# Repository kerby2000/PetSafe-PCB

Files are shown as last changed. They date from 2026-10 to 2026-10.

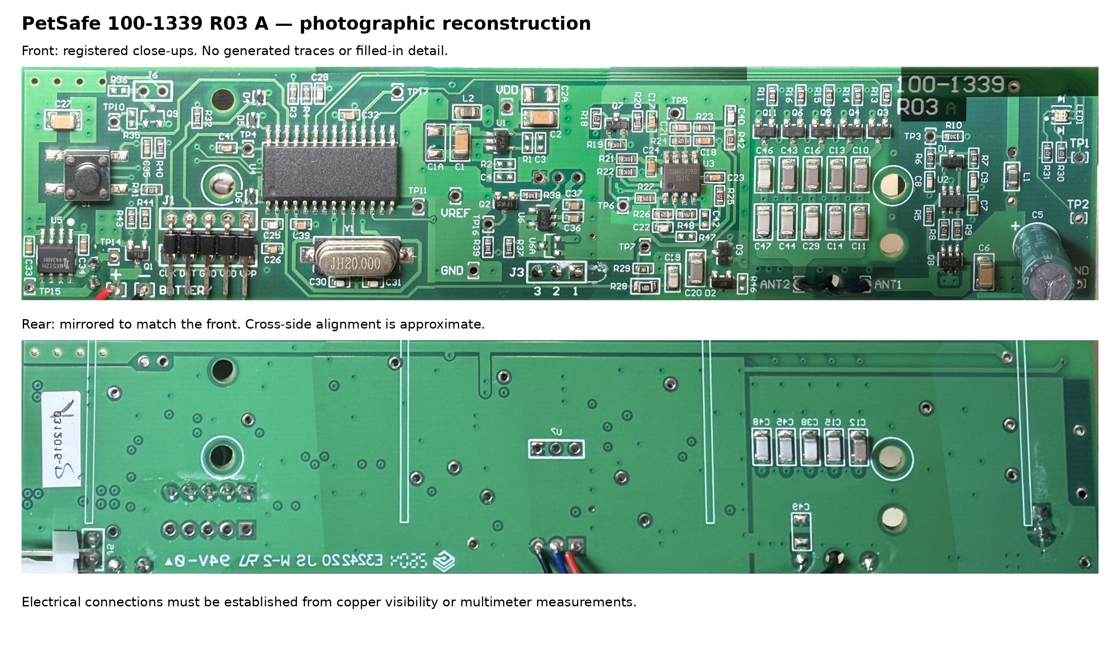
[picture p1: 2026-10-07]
photos/two_sides_overview.jpg

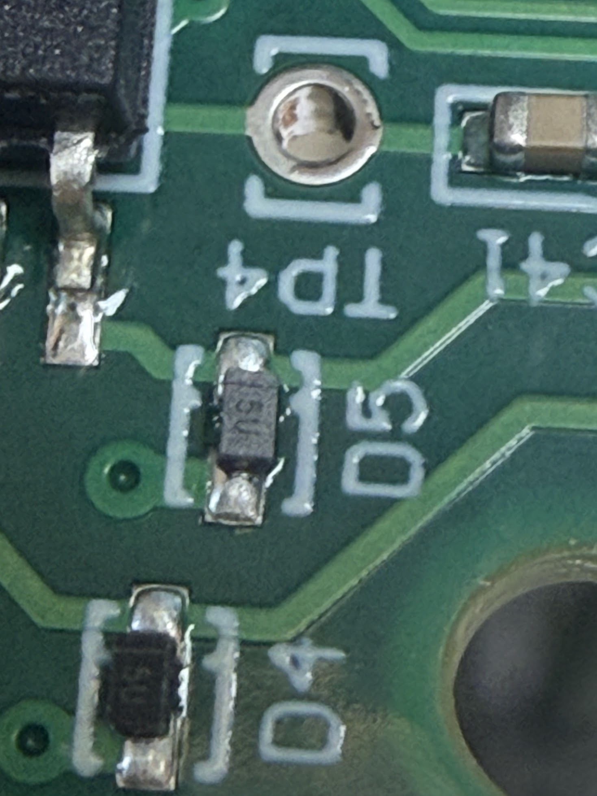
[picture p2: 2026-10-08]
photos/user_updates/D4_D5_5U.png

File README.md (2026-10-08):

# PetSafe PCB reverse engineering

Working reconstruction of the PetSafe PPA19-16811 main board, **100-1339 R03 A**. All 150 catalog entries are drawn on **one A2 KiCad 10 sheet**, with wires within functional blocks and named nets between them. Entries include test pads and unpopulated options.

Start with [the offline overview](index.html), [the current completion checklist](docs/FINISHING_CHECKLIST.html), or [the printable status](output/pdf/PetSafe_completion_status.pdf). Open [the native schematic](schematic/PetSafe_1001339.kicad_sch) in KiCad 10. The [single-sheet PDF](output/pdf/PetSafe_single_sheet.pdf) and SVG are native KiCad exports.

## Current status

Schematic revision **v0.9.9**; investigation cleanup **2026-10-08**. The model and native file agree on 83 net partitions. All PIC pads have modeled local connections, but some remote destinations and circuit roles remain uncertain. There is **no routed KiCad PCB**, confirmed layer stack, or powered functional validation.

| Remaining work | Current state |
|---|---|
| Open physical pads | 28: 10 on populated entries, 18 on empty options |
| Other incomplete connections | 3 isolated labels, plus inferred receiver/RF/PIR branches |
| Values | 44 fitted ceramic values; L1/L2 type and value |
| Footprints | 147/150 assigned; C5, S1 and LED1 geometry missing |
| ERC | 36 findings: 28 open pins, 3 isolated labels, 5 undriven power inputs |
| Libraries | 20 stock definitions and 4 authorized custom candidate definitions in use |

The checklist gives every known issue a stable ID, supporting evidence, next useful check and closure criterion. **A question mark, an assigned footprint, or zero open PIC pads does not measure overall completeness.** The first priority is D3: V082 reaches board VDD, but the corresponding D3 terminal has not been identified. Do not merge the receiver supply into VDD on that basis alone.

## Power names

| Name | Meaning |
|---|---|
| BATTERY+ | Printed BATTERY (+), before Q1 |
| VSYS | User-approved name after Q1; U5/MX512H pin 4 and the supply sides of L1/L2 |
| VDD | Printed VDD test point, regulated logic supply; U5 pin 1 / VCC |
| VREF | Printed VREF test point and confirmed PIC/bias connections |
| GND | Printed GND and BATTERY (-) |

L1/L2 share VSYS on their supply sides; their opposite ends are separate filter branches. H_RF_VDD, H_LDO_IN, H_RX_VDD and H_PIR_VDD are descriptive local branch names, not additional confirmed independent power sources. Actual rail voltages are not yet measured.

## Evidence and navigation

- [Current circuit interpretation](docs/RECONSTRUCTION.md), [measurements](docs/MEASUREMENTS.md), [sources](docs/SOURCES.md), and [library choices / alternatives](docs/LIBRARIES_AND_ALTERNATIVES.md).
- [Front/rear via viewer](docs/VIA_REVIEW.html), [via-pair results](docs/VIA_PAIR_TESTS.html), [current via summary](docs/VIA_REVIEW_RESULTS.md), and [numbered PIC photo](output/pdf/PetSafe_PIC_GPIO_pin_map.pdf).
- [Per-component audit](evidence/completion_audit.csv), [all modeled nets](evidence/proposed_nets.csv), [PIC evidence table](evidence/pic_gpio_status.csv), and [maintained question register](evidence/remaining_work.json).
- [Investigation history](docs/history/README.md). Historical claims and counts are not current instructions or outstanding measurements.

The original ZIP is in `input/`. Original photographs and their checksums are preserved. User reports, photo-derived copper and typical-application hypotheses remain distinct. A source datasheet validates a candidate symbol's pin map, not the fitted part's identity or board wiring. Western alternatives are redesign options, not silent substitutions.

## Reproduce and maintain

Use KiCad **10.x** (validated with 10.0.5), PowerShell and Python 3. Install `tools/requirements.txt` in a Python environment. Author schematic changes with the connected [KiCad MCP server](https://github.com/mixelpixx/KiCAD-MCP-Server); preserve stock library graphics and normal pin numbering. Four project-local symbols are registered using `${KIPRJMOD}`.

```powershell
$env:PYTHONUTF8 = '1'
python -m pip install -r tools/requirements.txt
./tools/build.ps1 -Python python
./tools/refresh_review.ps1 -Python python
```

`build.ps1` exports the existing native file, runs ERC and checks model/netlist partitions and footprints. It does not overwrite native edits. `-Regenerate` explicitly rebuilds from the saved MCP placement template and routing adapter; use it only when those sources are synchronized. `refresh_review.ps1` regenerates current documentation/status and checks electrical regressions and question coverage. Both commands fail on execution or validation errors; the documented outstanding ERC findings are retained.

For electrical edits, keep `evidence/reconstruction.json`, `evidence/library_layout.json`, `evidence/library_placements.json`, the MCP template, native schematic and routing adapter consistent. For documentation updates, maintain `evidence/remaining_work.json`; shared metrics are derived by `tools/current_state.py`. The current electrical regression suite is `tools/verify_v099_review.py`; earlier versioned suites are historical snapshots. Generated outputs should be rebuilt, not edited alone.

Local KiCad history, lock files, caches, QA renders and export ZIPs are ignored. No generated artifact is a fabrication release. Repository: [kerby2000/PetSafe-PCB](https://github.com/kerby2000/PetSafe-PCB).

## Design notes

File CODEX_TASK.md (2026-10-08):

# Current project handoff - 2026-10-08

Read AGENTS.md, README.md and evidence/remaining_work.json first. Schematic v0.9.9; documentation cleanup-1. Repository https://github.com/kerby2000/PetSafe-PCB. Local branch codex/single-sheet-reconstruction. Preserve the user's local schematic/PetSafe_1001339.kicad_pro and ignored schematic/.history/.

Current status is derived by tools/current_state.py. Run tools/build.ps1 followed by tools/refresh_review.ps1 (Python requirements installed; PYTHONUTF8=1). Do not edit generated HTML or status metrics alone. Latest electrical contracts are in tools/verify_v099_review.py; completion coverage in tools/verify_current_review.py. Older scripts/reports are historical, not the current work queue.

The power-path action is finished: BATTERY+ -> Q1 single/native3; Q1.L/native2 -> VSYS -> U5.4 and L1/L2 supply sides. VDD and VREF are separate printed board test points. Q1 is a stock PMOS FMOS3401A? candidate, not the old NPN. Never short across Q1/L1/L2. Keep all user negative evidence, including rejected Q1.L-R43.2 and RC1-VREF joins. The model's 83 partitions and all earlier measured routes remain unchanged by documentation cleanup.

Every known uncertainty has an ID, next check and closure criterion in remaining_work.json. Do not declare the schematic or PCB finished: 10 populated-entry open pads, 18 DNP open pads, 3 isolated labels, partly inferred branches, 44 ceramic values, L1/L2 values and 3 blank footprints remain. Zero open PIC pads only means each has a local modeled net. D3/V082 terminal identification is the first priority. Current docs record the unverified J3.2/.3 roles rather than inferring ground from wire colour.

Original photos/ZIP and chronological records are preserved. No routed PCB exists. No powered functional or rail-voltage readings supplied. Previous file:// browser automation was policy-denied; do not bypass with another browser or localhost. HTML can be inspected as source/data and opened for the user.

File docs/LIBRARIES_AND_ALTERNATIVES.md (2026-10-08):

# KiCad 10 libraries and device alternatives

Revision 0.9.9 uses the existing KiCad MCP Server and the installed KiCad 10.0.5 at `%LOCALAPPDATA%/Programs/KiCad/10.0`. Both its Python backend (`pcbnew.GetBuildVersion()`) and native CLI reported 10.0.5. The MCP created the blank native schematic and placed all 150 components plus five additional units from standard libraries. The checked-in routing adapter reconnects those stock symbols and adds the block frames and annotations. Native KiCad checks the resulting connectivity. MCP PDF/SVG export was also exercised successfully.

The user authorized U1/U5 after vendor files could not be found, and subsequently authorized U6/Q8 datasheet reconstruction. MCP `create_symbol`, `register_symbol_library` and `replace_schematic_component` created and installed U1/U5 from the manufacturer pin tables. The other 20 definitions retain unmodified KiCad stock artwork and numbering. `tools/templates/mcp_standard_placements.kicad_sch` is the MCP placement output; `evidence/library_placements.json` is the replay manifest. `evidence/pin_crosswalk.json` maps all 352 photographed pads to their library pin numbers. Pin mapping can be provisional even when the underlying part symbol is exact.

## Library choices

| References | Library symbol | Reason / status |
|---|---|---|
| U4 | `MCU_Microchip_PIC16:PIC16F18855-xSO` | Exact SOIC family symbol; default SOIC-28W footprint. |
| U2 A/B/C | `74xGxx:74LVC2G14` | Standard multi-unit Schmitt inverter, value `SN74LVC2G14DBV?`, SOT-23-6 footprint. This preserves separate readable gates and supply unit. The exact monolithic `SN74LVC2G14DBV` also exists. |
| U3 A/B/C | `Amplifier_Operational:Opamp_Dual` | Standard generic dual op-amp with matching 1-8 pin functions; value remains SGM8542XS. No modified or custom op-amp symbol. |
| Q1 | `Transistor_FET:Q_PMOS_GSD` | v0.9.9: FMOS3401A candidate, matching manufacturer R1A marking and SOT-23 G1/S2/D3 pinout. Photo R=gate, L=source, single S=drain. Original NPN hypothesis withdrawn. Exact fitted maker unconfirmed. |
| Q2, Q7 | `Transistor_BJT:BC847`, `Transistor_BJT:BC857` | Standard family symbols; values preserve the B/C gain-bin candidates. |
| Q3/Q4/Q5/Q6/Q11 | `Transistor_BJT:Q_PNP_BEC` | Standard generic PNP with B=1, E=2, C=3; value MMBTA55? preserves the uncertain 2H identification. |
| D1/D3 | `Diode:BAV99` | A7 marking candidates; D3 marking now confirmed by the user. Physical orientation and external clamp routes remain inferred. |
| D2 | `Connector_Generic:Conn_01x03` | Unidentified 4P part. Stock numbered placeholder with L=1/R=2/S=3 as bookkeeping only; no functional assignment. Prior BAV99 clamp ties withdrawn. |
| LED1, S1 | `Device:LED_Dual_AAKK`, `Switch:SW_Push_Dual` | Stock four-pin symbols; photographed pad mapping remains provisional. |
| R/C/L/Y/TP | `Device:R`, `Device:C`, `Device:C_Polarized`, `Device:L`, `Device:Crystal`, `Connector:TestPoint` | Existing conventional library parts. C5 polarity is inferred from the selected rail topology. |
| U1 | `PetSafe_Datasheet:S-1200B45-M5T1` | MCP-created from ABLIC Rev.6 page 5: 1 VIN, 2 VSS, 3 ON/OFF, 4 NC, 5 VOUT. B option has active-high enable. The fitted part remains a strong identification candidate, not a measured fact. |
| U5 | `PetSafe_Datasheet:MX512H` | MCP-created from Mixic Rev.1.2 page 2: 1 VCC, 2 INA, 3 INB, 4 VDD, 5 OUTB, 6/7 GND, 8 OUTA. Logic/motor supplies and both ground pins retained. |
| U6 | `PetSafe_Datasheet:S-812C33AMC` | MCP-created from ABLIC Table 5; C2N product code and measured likely ground support identification. |
| Q8 | `PetSafe_Datasheet:SIL3724A` | MCP-imported standard generic N/P graphics with manufacturer-verified 1 G_N, 2 S_P, 3 G_P, 4 D_P, 5 S_N, 6 D_N. Fitted maker unconfirmed. |
| D4/D5 | `Device:D_Zener` | Standard unidirectional avalanche symbol, value SD05? / TVS 5V. Semtech maps 5U to SD05. SOD-323 candidate footprint; ICSP and ground routes are photo-derived. |
| D6 | `Device:D_Zener` | G3 supports MMSZ5228BS? / 3.9V, but PZU2.4B / 2.4V remains an alternative. Standard SOD-323 candidate footprint; ICSP and ground routes are photo-derived. |
| J connectors / empty pads | `Connector_Generic` family | Unknown pitches and empty package identities stay unspecified. These entries preserve the source catalog. |

The installed BAV99 symbol has hidden pin-name strings that do not agree with the Nexperia terminology for pins 1/2. Its visible diode geometry and **pin numbers** agree with the datasheet (1 A1, 2 K2, 3 K1/A2). No library modification or pin swapping was made to hide this naming issue.

## Western alternatives

These are engineering candidates, not identifications of the fitted chips. The reconstruction has not been converted into a replacement board.

| Fitted / candidate part | Alternative | Stock KiCad symbol / footprint | Compatibility |
|---|---|---|---|
| SGM8542XS, SOIC-8 | **Microchip MCP6002-I/SN** | `Amplifier_Operational:MCP6002-xSN`; `Package_SO:SOIC-8_3.9x4.9mm_P1.27mm` | Same eight pin functions and nominal narrow SOIC-8 package. Plausible pin-compatible option, but electrical equivalence is not established. |
| MX512H, SOP-8 | **TI DRV8212PDSGR** | `Driver_Motor:DRV8212P`; `Package_SON:Texas_DSG0008A_WSON-8-1EP_2x2mm_P0.5mm_EP0.9x1.6mm_ThermalVias` | Preferred redesign candidate. Separate logic/motor supplies, two logic inputs, up to 4 A peak. Different package, pinout, exposed ground pad, and sleep control: **requires PCB and control review**. |
| MX512H, lower-current option | TI DRV8837DSGR | `Driver_Motor:DRV8837`; standard WSON-8 footprint | Similar interface, but its 1.8 A headline drive rating is below MX512H's advertised 3 A peak. Do not choose it without establishing motor current margin. |

MCP6002 offers 1.8-6.0 V operation and 1 MHz bandwidth. Against SGM8542's 2.1-5.5 V, 1.1 MHz and 46 uA/amplifier, its typical 100 uA/amplifier increases the receiver's two-channel quiescent load by about **108 uA**. Its 4.5 mV maximum offset versus 3.5 mV also matters in the high-gain chain. The same resistor gain does not guarantee the same receiver threshold or filtering response. Sources: [Microchip DS20001733L](https://ww1.microchip.com/downloads/aemDocuments/documents/MSLD/ProductDocuments/DataSheets/MCP6001-1R-1U-2-4-1-MHz-Low-Power-Op-Amp-DS20001733L.pdf), [SGMICRO datasheet](https://www.sg-micro.com/rect/assets/537cce2c-8022-4ea6-97f4-6524851a35e8/SGM8541_SGM8542_SGM8544.pdf).

DRV8212P covers the inferred battery range with its motor supply and has a 1.65-5.5 V logic supply. Its 4 A figure is a peak rating subject to thermal limits, not a promise of 4 A continuous output on a tiny footprint. MX512H advertises 1.4 A continuous and 3 A peak at 6.5 V; the larger peak margin makes DRV8212P a more useful redesign candidate than DRV8837. Sleep/wake timing, coast/brake behavior, stall current and supply transients remain design checks. Sources: [TI DRV8212P Rev. A](https://www.ti.com/lit/ds/symlink/drv8212p.pdf), [MX512H Rev.1.2](https://static.chipdip.ru/lib/203/DOC045203539.pdf), [TI DRV8837 Rev. F](https://www.ti.com/lit/ds/symlink/drv8837.pdf).

### Motor-driver function cross-reference (redesign only)

| Function | MX512H pin | DRV8212P pin |
|---|---|---|
| Logic supply | 1 VCC | 8 VCC |
| Motor supply | 4 VDD | 1 VM |
| Control A / B | 2 INA / 3 INB | 6 IN1 / 5 IN2 |
| Motor A / B | 8 OUTA / 5 OUTB | 2 OUT1 / 3 OUT2 |
| Ground | 6 and 7 | 4 plus exposed pad (KiCad 9) |
| Sleep | No separate pin | 7 nSLEEP; must be defined, not left floating |

This table matches functions, not physical pad locations. Motor polarity and truth-table behavior still require review before implementing a redesign. DMC3071LVT is a Western Q8 comparison with the same pin functions but a different TSOT package and electrical ratings; it is not an approved replacement. U6 is now an ABLIC Japanese regulator candidate. ABLIC S-1200B45 is a Japanese regulator, not a Chinese device needing a geographical substitution.

## Footprints and completed datasheet symbols

Standard SOT-23, SOT-23-5, SOT-23-6 and SOIC footprints are assigned only for identified/candidate packages. Assignment is a package-family hypothesis, not a measurement of the photographed land pattern. Current assignments use fitted resistor family 0603, anchored by the user R8 full-body measurement; large tuning capacitors use 1206, supported by C11 dimensions. Other bodies remain photo-based estimates. Earlier 0805 family estimates are superseded. Connector pitches and test-pad drills are lower-confidence approximations. Only C5, S1 and LED1 remain unassigned; selecting a stock switch also requires reconciling its common-pad numbering. J1 retains logical pin numbering, so its square-pad/VPP orientation must be reconciled before PCB recreation. See evidence/footprint_evidence.json for every assignment and its basis. U6 SOT-23-5 and Q8 SOT-23-6 are datasheet-based package candidates, not measured land patterns.

The original two exact-symbol requests are now resolved through authorized MCP creation. U1 uses stock `Package_TO_SOT_SMD:SOT-23-5`. U5 uses stock `Package_SO:SOIC-8_3.9x4.9mm_P1.27mm`, matching the nominal package dimensions on MX512H page 9. Pad numbers were checked through MCP. Land-pattern fit on the photographed PCB remains unmeasured. SGM8542 does not need a custom drawing: the stock generic dual op-amp already represents its actual pinout. U6 and Q8 now have datasheet candidate symbols with normal artwork and pin numbering. The old custom library and generator are archived in `reference/v02/`; they are not registered in the active project.

## U6 / Q8 follow-up (2026-10-08)

See [corrected marking and pin maps](U6_Q8_MARKING_UPDATE.md). MCP library search found no exact S-812C or 3724 symbol. U6 was created from ABLIC's pin table; Q8 reuses KiCad's `Q_Dual_NMOS_PMOS_G1S2G2D2S1D1` artwork through MCP import. The six pins match SIL3724A. Actual 3724A fitted manufacturer remains unconfirmed. The earlier RT9818 intermediate symbol was removed after the new photo corrected the marking.

MCP's property writer damaged a nested KiCad 10 property expression during the first Q8 import attempt. The malformed intermediate was removed, the generic base symbol was reimported through MCP, and metadata was repaired with a parsed S-expression. Graphics and pins were not redrawn by hand. Native export and the library audit validate the final result. Authoring details are recorded in `evidence/datasheet_symbol_authoring.json`.

The U1/U5 pin contracts in `evidence/vendor_symbol_requirements.json` are fulfilled. `evidence/datasheet_symbol_authoring.json` records the actual MCP requests and sources. No vendor files were imported. The library URI uses `${KIPRJMOD}`, so the repository is portable. U1 pin 4 is passive and named NC because ABLIC explicitly permits this internally open pad to connect to VIN/VSS; it preserves the existing optional-pad copper. MX512H outputs use tri-state pin types to reflect high-impedance standby. These changes enable additional ERC checks without hiding unresolved nets.

## v0.7 package correction

The user reports R8 approximately 1.6 x 0.77 mm including both metal end caps, confirming the 0603 body-size match. This supersedes v0.6's 0805 fitted-resistor-family estimate; other resistors are revised as provisional 0603 family candidates. C11 approximately 3.2 x 1.5 mm supports its 1206 assignment. C5 value/voltage are now 470uF/16V; its package remains unset pending dimensions.

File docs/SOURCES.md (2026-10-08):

# Source register

Manufacturer pinouts and application examples establish plausible functions, not photographed board connectivity. Accessed 2026-10-07 and 2026-10-08. Key PDFs are saved under `datasheets/`; SHA-256 checksums are in `evidence/datasheet_manifest.json`.

| Ref | Primary source | What it supports |
|---|---|---|
| U1 | [ABLIC S-1200 Rev.6.0](https://www.ablic.com/en/doc/datasheet/voltage_regulator/S1200_E.pdf), saved as S1200.pdf | Page 5 SOT-23-5 pins; page 23 marking PPE = S-1200B45-M5T1x with fourth-character lot code; typical regulator application. |
| U2 | [TI SN74LVC2G14](https://www.ti.com/lit/ds/symlink/sn74lvc2g14.pdf), saved as SN74LVC2G14.pdf | Page 3 DBV six-pin top view; ordering addendum lists C14R; dual Schmitt inverter function. |
| U3 | [SGMICRO SGM8541/8542/8544](https://www.sg-micro.com/rect/assets/537cce2c-8022-4ea6-97f4-6524851a35e8/SGM8541_SGM8542_SGM8544.pdf), saved as SGM8542.pdf | Dual op-amp pinout, 2.1-5.5 V supply, approximately 1.1 MHz gain-bandwidth. |
| U4 | [Microchip PIC16(L)F18855/75 DS40001802H](https://ww1.microchip.com/downloads/aemDocuments/documents/MCU08/ProductDocuments/DataSheets/PIC16%28L%29F18855-75-Data-Sheet-40001802H.pdf) | 28-pin package, power, oscillator and ICSP pins; configurable peripherals. |
| U5 | [Mixic MX512H Rev.1.2, manufacturer PDF mirrored by Chipdip](https://static.chipdip.ru/lib/203/DOC045203539.pdf), saved as MX512H.pdf | Eight-pin H-bridge map; separate logic/motor supplies; application circuit and at least 4.7 uF logic decoupling. Mirror filename/title is less useful than the MX512H content. |
| Q2 | [Nexperia BC847x datasheet](https://assets.nexperia.com/documents/data-sheet/BC847X_SER.pdf) | BC847B marking 1F plus manufacturing code; NPN B/E/C pinout. |
| Q7 | [Nexperia BC857C product information](https://www.nexperia.com/products/bipolar-transistors/general-purpose-and-low-vcesat-bipolar-transistors/single-bipolar-transistors/single-bipolar-transistors-100-v/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) | BC857C PNP with 3G marking plus manufacturing code. |
| Q1 | [Formosa FMOS3401A Rev.C](https://www.formosams.com/upload/product/Mosfets/FMOS3401A_REV_C.pdf), saved as FMOS3401A_REV_C.pdf | Page 5 explicitly lists R1A, 3401 and R1 markings and shows SOT-23 PMOS pin functions. Fits Q1 photo/power path; exact fitted maker unproved. Earlier MMBT3904 NPN hypothesis withdrawn in v0.9.9. |
| Tuning Qs | [Taitron semiconductor catalog](https://www.taitroncomponents.com/docs/2007%20Semiconductor%20Catalog.pdf) | Manufacturer table lists MMBTA55 / 2H / PNP. Exact fitted manufacturer is unknown. |
| Tuning alternative | [Nexperia PBSS5140T](https://assets.nexperia.com/documents/data-sheet/PBSS5140T.pdf) | Alternative PNP candidate; short-code identification remains ambiguous. |
| D1 | [Nexperia BAV99](https://assets.nexperia.com/documents/data-sheet/BAV99.pdf) | A7 marking, SOT23 dual-series diode and pin map. Current Diodes-branded BAV99 uses a different marking; do not use that to prove A7. |
| Native format | [KiCad schematic format](https://dev-docs.kicad.org/en/file-formats/sexpr-schematic/) | Embedded library, symbol units, wires, junctions, instances and labels. Native validation uses the installed 10.0.5 CLI. |

## Photographs used for circuit decisions

| Photo | Main content |
|---|---|
| IMG_2430 | U1/PPEK, regulator capacitors and empty option network |
| IMG_2431, IMG_2432 | U2/C14R, Q8/3724A (sharper follow-up), D1, RF drive resistors |
| IMG_2433, IMG_2442 | Repeated tuning cells and corresponding rear capacitor/via arrangement |
| IMG_2429, IMG_2434 | U3, feedback resistors, receiver components |
| IMG_2435 | U6, Q2 and daughterboard interface |
| IMG_2436, IMG_2437 | PIC, oscillator, programming area and battery-divider resistors |
| IMG_2438 | Motor driver, Q1 and pushbutton |
| IMG_2421 and overview photos | Separate PIR daughterboard context; its internal circuit is not reconstructed |

Full provenance remains in the original component model and photo manifest. Existing image registration is an approximate alignment, not a dimensioned board or a verified layer-stack reconstruction. No exact schematic of this board was adopted from an unrelated product.

## KiCad 10 rebuild and Western alternatives (2026-10-08)

- [KiCad MCP Server](https://github.com/mixelpixx/KiCAD-MCP-Server): already installed and connected. Used for standard-library searches, blank schematic creation, all 150 component placements, extra units, footprint inspection and PDF/SVG export.
- [Microchip MCP6001/2/4 DS20001733L](https://ww1.microchip.com/downloads/aemDocuments/documents/MSLD/ProductDocuments/DataSheets/MCP6001-1R-1U-2-4-1-MHz-Low-Power-Op-Amp-DS20001733L.pdf): page 1 pinout, pages 3-4 operating range, current, offset and bandwidth; SOIC package drawings. Saved as MCP6002.pdf.
- [TI DRV8212P Rev. A](https://www.ti.com/lit/ds/symlink/drv8212p.pdf): page 4 pin functions and exposed pad, page 5 recommended operating conditions, typical application and package drawing. Saved as DRV8212P.pdf. Preferred motor-driver redesign candidate because MX512H advertises a 3 A peak.
- [TI DRV8837 Rev. F](https://www.ti.com/lit/ds/symlink/drv8837.pdf): alternative lower-current driver; its separate supplies, sleep input and WSON package differ from MX512H. Saved as DRV8837.pdf.

Library existence and footprint names were verified against the user's installed KiCad 10 libraries through MCP, not inferred from online search results. See LIBRARIES_AND_ALTERNATIVES.md for compatibility boundaries.

## U6 / Q8 and diode marking sources

- [ABLIC S-812C](https://www.ablic.com/en/doc/datasheet/voltage_regulator/S812C_E.pdf), saved as S812C.pdf: printed p8 Table1 C2N = S-812C33AMC 3.3 V; p11 Table5 pins 1 VSS, 2 VIN, 3 VOUT, 4/5 NC for A variant.
- [ABLIC MP005-A package](https://www.ablic.com/en/doc/package/MP005-A.pdf), saved as ABLIC_MP005-A.pdf: PDF p5 three product-code characters, fourth assembly month, dot positions assembly year/week. Supports C2NM interpretation; M's exact month not decoded.
- [MCC SIL3724A manufacturer PDF, Chipdip mirror](https://static.chipdip.ru/lib/761/DOC050761871.pdf), saved as SIL3724A.pdf: p1 explicit 3724A marking, N/P pair, pin diagram and SOT23-6L dimensions. Same primary document was read via Mouser; direct Mouser download returned HTML, which was replaced with this valid PDF.
- [Nexperia BAV99](https://assets.nexperia.com/documents/data-sheet/BAV99.pdf), saved as BAV99.pdf: A7 marking and dual-series topology support D3 (user-confirmed A7) and D1. D2 was withdrawn after user-confirmed 4P.
- **Withdrawn D4-D6 candidate:** [Diotec 1N4148WS](https://diotec.com/tl_files/diotec/files/pdf/datasheets/1n4148ws.pdf), saved as 1N4148WS.pdf: T4/W2 mark and SOD-323F switching diode. Earlier photos were misread as T4; newer 5U/G3 readings supersede that guess. The PDF is retained as source history.
- New user photographs are copied unchanged to photos/user_updates/ and checksummed separately in evidence/user_evidence_2026-10-08.json. Measurements and the 0.5-ohm shorted-probe clarification are recorded in evidence/measurement_plan.json. The original 26-image manifest is unchanged.

## Diode marking sources

- [Semtech SD05/SD12, manufacturer PDF mirrored by TME](https://www.tme.eu/Document/7ef0e55cabc749c01c5f7eae977e91a5/SD05.pdf), saved as SD05.pdf: page 6 5U marking; pages 1-2 unidirectional SOD-323 TVS with 5 V standoff. D4/D5 candidate.
- [Diodes MMSZ5228BS](https://www.diodes.com/datasheet/download/MMSZ5228BS.pdf), saved as MMSZ5228BS.pdf: page 2 G3 = 3.9 V SOD-323 Zener. D6 provisional first candidate.
- [Nexperia PZUxB](https://assets.nexperia.com/documents/data-sheet/PZUXB_SER.pdf), saved as PZUXB_SER.pdf: page 2 G3 = PZU2.4B 2.4 V SOD323F. D6 alternative; the marking is not unique.
- New D4/D5/D6 user images are preserved in photos/user_updates. Q8 D-E=2 ohm and S-G=2 ohm support joined drains/ground source. E-F=400 kohm refutes direct C6/output copper; F-P=10 ohm and F-G=300 kohm support a supply-related C6 node, with exact path unresolved.

## Current evidence boundaries

See [recorded measurements](MEASUREMENTS.md), [circuit interpretation](RECONSTRUCTION.md) and [library alternatives](LIBRARIES_AND_ALTERNATIVES.md). Q1 uses the R1A/FMOS3401A candidate above; exact fitted maker and gate operation remain unverified. D2/4P is unidentified; the Zetex FMMT2907R marking is a lead, not a fitted-part identification. The original dated citations, historical candidates, package audits and event-by-event reports are preserved in [the archived source register](history/pre_cleanup_20261008/docs/SOURCES.md). All saved datasheets have hashes in `evidence/datasheet_manifest.json`. Datasheets establish candidate properties, not board connectivity.

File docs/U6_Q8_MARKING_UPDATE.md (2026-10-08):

> Historical investigation: marking/pin-table sources remain useful, but later user continuity supersedes temporary wiring claims. Use [the current checklist](FINISHING_CHECKLIST.html) and [current interpretation](RECONSTRUCTION.md).

# U6 and Q8: corrected markings, v0.5

The sharper user photographs read **C2NM on U6** and **3724A on Q8**. The earlier WN23 and 372A readings were incorrect. This report supersedes the candidate ranking in the historical U6/Q8 investigation.

## Current copper correction - v0.9.2

V113/V115 were incorrectly annotated as Q8 outer drain pads. The user identifies the centre B2/package pin5 instead, connected to GND, consistent with the earlier S-G reading. This resolves those two site conflicts without changing the datasheet pin map or the independent outer-drain join. V114 is the opposite centre T2/package pin2; its older GND report versus the source-supply hypothesis remains unresolved after a location-only follow-up.

## U6: ABLIC S-812C33AMC-C2NT2x, strong candidate

The [ABLIC S-812C datasheet](https://www.ablic.com/en/doc/datasheet/voltage_regulator/S812C_E.pdf), Table 1 on printed page 8, maps product code **C2N** to the **3.3 V S-812C33AMC** in SOT-23-5. The [MP005-A package marking drawing](https://www.ablic.com/en/doc/package/MP005-A.pdf), PDF page 5, specifies three product-code characters followed by an assembly-month character. Thus M is an assembly code; its month has not been decoded here. This is a manufacturer-code match, reinforced by package and ground evidence, rather than a typical-application guess alone.

Table 5 on printed page 11 supplies the pin functions. In the original IMG_2435 photo and measurement guide:

| Probe / original pad | Package pin | Function | User resistance to G |
|---|---|---|---|
| C / R3 | 1 | VSS, ground | 2.7 ohm |
| B / R2 | 2 | VIN | 34 kohm |
| A / R1 | 3 | VOUT | 4.2 kohm |
| L1 | 4 | Internally open NC | Not measured |
| L2 | 5 | Internally open NC, A variant | Not measured |

The user clarified that shorted probe tips now read **0.5 ohm**; the earlier 2-5 ohm baseline varied with contact pressure. C is likely ground. The 2.7 ohm result is not precise proof of a direct copper connection, because it was not measured with an identical stable contact baseline. The very different A/B readings support distinguishing them from ground; resistance does not establish voltage or exact semiconductor identity.

**The RT9818A-33PB supervisor hypothesis is withdrawn.** Its WN code was found in real Richtek marking documentation, but the photographed device does not read WN. Its conventional pin3 ground also conflicts with these readings. The earlier generic LDO drawing used the wrong pin assignment too; v0.5 corrects the assignment from ABLIC Table 5.

The schematic now proposes R37 -> VIN, C36 input bypass, VOUT -> C37/PIR rail and pin1 -> ground. **3.3 V is the candidate rating, not a measured rail voltage.** NC pins remain unwired because no external ties have been established. ABLIC permits tying these internally open pads to VIN/VSS, so the symbol represents them as passive pins named NC.

## Q8: 3724A complementary N/P MOSFET pair

The [MCC SIL3724A manufacturer datasheet, mirrored by Chipdip](https://static.chipdip.ru/lib/761/DOC050761871.pdf), page 1, explicitly shows **3724A**, the six-lead SOT23-6L package, and one N-channel plus one P-channel MOSFET. This substantially strengthens the earlier circuit-role inference from the two 220-ohm drive resistors. The exact fitted manufacturer remains unconfirmed: a matching short marking is not a unique manufacturer logo identification.

| Original photo pad | Pin | Function |
|---|---|---|
| T3 | 1 | N-channel gate |
| T2 | 2 | P-channel source |
| T1 | 3 | P-channel gate |
| B1 | 4 | P-channel drain |
| B2 | 5 | N-channel source |
| B3 | 6 | N-channel drain |

The symbol uses normal KiCad generic N/P MOSFET artwork, imported through MCP and matched to this datasheet pin map. Both units belong to Q8 on the same sheet. The visible value is **SIL3724A?**, preserving uncertainty about the exact fitted part. The footprint is standard KiCad SOT-23-6; physical land-pattern fit remains unmeasured.

The user measured **D-E = 2 ohm**, **S-G = 2 ohm**, and **E-F = 400 kohm**. The low readings support joined drains and the N-source ground return, allowing for probe contact resistance. The 400-kohm result refutes a direct C6 upper-pad/output connection. That proposed wire has been removed; C6.1 is unresolved. The P-source supply and R5 output continuation remain inferred. The follow-up readings are **F-P=10 ohm** and **F-G=300 kohm**. They support a supply-related role for F, but 10 ohm is higher than the roughly 2-ohm direct-connection readings. Contact or series resistance could explain this; the exact path remains unresolved and no 10-ohm resistor is invented. [The annotated guide](../output/pdf/PetSafe_measurement_round1.pdf) records all results. This in-circuit 400-kohm result is not the value of a discrete resistor.

The Diodes **DMC3071LVT** remains a Western comparison with the same pin functions, but different ratings and a TSOT-23-6 package. Its C71 marking does not identify the fitted Q8 and it is not an approved drop-in replacement. U6 is an ABLIC Japanese part; no geographical substitute is needed to draw the fitted candidate accurately.

## D2-D6 candidates

- **D3: BAV99?** The user clearly reads **A7**. [Nexperia BAV99](https://assets.nexperia.com/documents/data-sheet/BAV99.pdf), page 2, supports A7 and the series-dual pin map. Board orientation and clamp routing remain inferred.
- **D2: 4P, unidentified.** The user clearly reads **4P**. The earlier BAV99 assignment and all three guessed clamp connections are withdrawn. The [Zetex manufacturer FMMT2907 datasheet](https://media.digikey.com/pdf/Data%20Sheets/Zetex%20PDFs/FMMT2907%28A%29.pdf), page 1, lists **FMMT2907R = 4P**, a SOT-23 PNP transistor. That is a credible marking/package lead, not proof of the fitted identity or its pin functions. A stock three-pin numbered placeholder retains the photographed pads until the internal junction arrangement and copper routes are established. No transistor pin map is forced onto it.
- **D4/D5: SD05?**, a 5 V unidirectional TVS. The sharper user photos read **5U**, contradicting the earlier T4/1N4148WS guess. [Semtech's manufacturer datasheet](https://www.tme.eu/Document/7ef0e55cabc749c01c5f7eae977e91a5/SD05.pdf), page 6, explicitly maps SD05 to 5U; page 1 specifies SOD-323. Five volts is the working/standoff rating, not its surge clamp voltage. Fitted manufacturer remains unconfirmed. A stock avalanche/Zener symbol is appropriate for this unidirectional TVS; a bidirectional TVS symbol would be wrong.
- **D6: MMSZ5228BS? / 3.9 V Zener**, a provisional first candidate. [Diodes' table](https://www.diodes.com/datasheet/download/MMSZ5228BS.pdf), page 2, maps **G3** to this SOD-323 part. However, [Nexperia PZU2.4B](https://assets.nexperia.com/documents/data-sheet/PZUXB_SER.pdf), page 2, also uses G3 for a **2.4 V** SOD323F Zener. The code does not uniquely establish the voltage or maker. No breakdown voltage was measured.

The cathode bands are visible in the new diode photos. Their mapped board endpoints and external connections remain unresolved; all six D4-D6 pads stay open. These candidates replace the earlier 1N4148WS guess. D2 and D3 are the three-lead parts beside C20 near U3, shown in [the location image](../output/D2_D3_location_v1.png).

The fitted identities, package dimensions and circuit connections have different confidence levels. A symbol pin table can be verified while a board wire remains inferred. See evidence/measurement_plan.json for raw readings and evidence/v05_net_changes.json for the specific revisions to net assignments.

## R41

The user clearly reads **331**: the three-digit resistor code is 33 x 10^1 = **330 ohm**. This is a recovered nominal value, not a multimeter reading; tolerance and power rating are not encoded here. The schematic, inventory and MCP placement template now use 330.

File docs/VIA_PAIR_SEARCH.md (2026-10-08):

# Targeted via-to-via search — current round

Basis: **v0.9.9**. The remaining search pool has **9 sites in 8 local endpoint groups**. These are not 8 proven missing nets. V067/U6A is now mapped to J3.1/PIR supply; no generic GPIO batch remains pending.

V035 now reaches VREF, V042 reaches board VDD. VSYS names the separate post-Q1 supply; L1/L2 share it. V015/TP14 is on battery+ by photo. See [current power evidence](VIA_REVIEW_RESULTS.md). Later v0.9.8 notes below are retained as historical context.

## Results applied

| Pair | Result | Consequence |
|---|---|---|
| V053–V070 | Connected | PIC12/RC1 → R18.1; user checked |
| V053–VREF | NOT connected | Withdraw old RC1/VREF photo assumption |
| V049–TP3 | Connected | PIC13/RC2 → TP3; local R10 branch remains photo-derived |
| V026–VREF | Connected | PIC21/RB0 → native TP104, labelled VREF |
| V067–J3.1 | Connected | Earlier U6A pad association joins H_PIR_VDD; DNP retained |
| V036–V108 | Working | PIC5/RA3 → R14 |
| V037–V102 | Working | PIC6/RA4 → R15 |
| V039–V097 | Working | PIC7/RA5 → R16 |
| V047–V091 | Working | PIC11/RC0 → R11 |
| V064–V063 | Working | R37/R39 feed joins regulated VDD |
| V064–V075 | Working | V075 joins regulated VDD; Q7/R19 local pad selection photo-derived |
| V064–V070 | 11.2 kΩ | Resistive path; direct R18 input-to-VDD assumption withdrawn |
| V049–V071 | 20 kΩ | Resistive path to the R21-associated node; not the pending V070/R18 test |
| V049–V070 | Variable 200–300 kΩ | No continuity demonstrated; contact-dependent, not a definitive open |
| V053–V071 | Not connected | Reject proposed V053/RC1-to-R21 direct link |
| V090–V095 | OL | No measured direct connection |
| V090–V100 | OL | No measured direct connection |
| V090–V103 | OL | No measured direct connection |
| V090–V107 | OL | No measured direct connection |
| V095–V100 | OL | No measured direct connection |
| V095–V103 | OL | No measured direct connection |
| V095–V107 | OL | No measured direct connection |

Positive pairs and the V053–V071 result were reported without numerical ohms. No numerical reading has been invented. All five tuning controls are now mapped, including the earlier RC6/R13 route. No PIC pads remain open in the model. RC1 now reaches R18, RC2 reaches TP3 and RB0 reaches VREF. Other already drawn local nets can still have unknown or inferred remote connections.

## Why those pairs were proposed

The successful GPIO tests had a specific functional basis: a repeated bank of transistor/resistor cells plausibly needs separate PIC control outputs. The supply tests compared a known rail with a plausible local feed. Neither geometry nor a typical application establishes a connection without evidence.

The capacitor tests were weaker: repeated neighboring cells suggested that their junctions *might* share hidden copper. A shared node needs only one fixed-probe sweep to detect, rather than all possible pair combinations. V090 gave OL to all four others. The second sweep used V095 to test whether the remaining four shared a different node. That was a hypothesis based on repeated structure, not an observed trace or a datasheet requirement.

**Seven OL results now weaken that common-node hypothesis enough to stop broad capacitor-pair testing.** The three remaining mutual comparisons (V100–V103, V100–V107, V103–V107) are untested, not inferred negative. An OL resistance result excludes a measured direct DC path in this test; it does not exclude a signal path through capacitors. Any later test must follow a visible local route or a specific circuit endpoint.

## What the 11.2 kΩ reading changes

R18 is marked 122 (1.2 kΩ) and R19 is marked 01C (10 kΩ). Their nominal sum is **11.2 kΩ**, matching the reported in-circuit reading. The measured path is not direct copper. Combined with IMG_2434 and the earlier V064–V075 supply confirmation, it supports this local reconstruction:

`V070 → R18 (1.2k) → Q7 base / R19 (10k) → V075 / regulated VDD`

Q7's emitter joins VDD; R19 is a base-emitter pull-up, and the collector feeds the receiver supply through R20. This is a **photo/resistance-supported circuit inference**, not proof from resistance alone. The Q7 candidate remains BC857C; the official Nexperia datasheet supplies the candidate pin roles (1=B, 2=E, 3=C), not the board wiring. No reverse-probe reading or isolated resistor measurement was supplied.

Native v0.9.7 removes the old direct R18.1-to-VDD assumption, moves R18.2 to the base junction, and places Q7.R/R19.2 on VDD. No GPIO source is invented. Validation checks 86 model/native partitions; 42 ERC findings remain (33 open pads, four isolated labels, five power findings).

The additional **V049–V071 = 20 kΩ** report is recorded independently. V071 reaches R21; V070 reaches R18. This reading excludes a direct RC2-to-V071 link but does not identify the resistance path through the unpowered receiver circuit. It is independent of D1, and no specific series-resistor path is claimed from 20 kΩ alone.

## Completed GPIO follow-up

V049–V070 returned variable 200–300 kΩ with probe placement. This remains inconclusive/contact-dependent, not OL or a recovered resistor value. The proposed D2 V070–V026 check was never measured and was withdrawn when the user identified RB0/VREF. It must not be recorded as rejected.

The user then explicitly excluded V053 from VREF and confirmed **V053–V070**. Thus RC1/PIC12 reaches R18.1 while RB0/PIC21 reaches VREF/TP104. The former RC1–VREF photo interpretation is withdrawn. RC2/PIC13 reaches TP3; its prior local R10.1 branch remains photo-derived. V067 reaches J3 pin 1/red wire, mapped to H_PIR_VDD; this preserves the previous local U6A.R1 pad association without identifying the unpopulated device.

The [photo locator](VIA_PAIR_TESTS.html) and [printable guide](../output/pdf/PetSafe_via_pair_next_check.pdf) now show the completed V053–V070 route. No repeat reading is requested. Earlier browser storage and round-2/3/4/5 evidence are preserved. New reports are in `v098_net_changes.json` and `via_user_review.json`.

Validation: **83 native/model net partitions PASS; 36 ERC findings = 28 open pads + 3 isolated labels + 5 power findings**. The 28 open pads comprise 10 populated-entry and 18 empty-option pads. Local modeled connections can still have missing remote continuations or inferred branches.

## Remaining decisions

- Q1.L / V011–V014 is user-confirmed to motor VDD/U5 pin4. The logic and motor rails remain separate. Q1.L remains separate from explicitly excluded R43.2/V015.
- V114 is resolved as U2.T2/pin2 GND and removed from the candidate pool. It is not Q8.T2.
- B3 is complete at 11.2 kΩ. Do not repeat it or start a blind rail sweep. V064–V063 and V064–V075 remain confirmed.
- V071/R21 is now confirmed to VREF/TP104 and PIC21/RB0. V053/RC1 remains explicitly rejected; no further V071 GPIO search is needed.
- The formerly open GPIO list is complete. Prioritize remote continuations of already-local nodes, receiver/PIR/button interfaces, Q7 identity/function qualifications and the D3 terminal at V082. V067/U6A is now mapped to J3.1.

The [complete via-group inventory and hypotheses](../evidence/via_pair_plan.json) retains each local endpoint association separately. No proposed next pair has been added as a schematic connection.

Latest v0.9.8 report: **V015-TP14 confirmed**, joining R43.2 to TP14. Q1.L remains excluded. Existing TP14-Q1.S branch and H_BAT_DETECT functional name remain hypotheses; no numeric resistance supplied.

Latest v0.9.8 report: **V017-TP4 confirmed**, joining R42.1/R44.1 to TP4 and PIC25/RB4. Existing C41 branch and R44 pad selection retain their photo-derived basis. No numeric resistance supplied.

V082 follow-up: user confirms board VDD test point = TP103/H_VDD logic supply. H-bridge pin1 VCC shares logic supply; pin4 VDD is separate H_VBAT motor supply. V082 exact D3 terminal remains unresolved: no D3.R or receiver-rail merge. TP103 relabelled VDD (logic supply). Search pool now 16 sites/12 groups.

V071 follow-up: user confirms V071–VREF, mapping R21.2 to TP104/VREF/PIC21/RB0. Prior R22.2/R23.2/R48.2 bias branches are retained hypotheses; the new report does not independently confirm them. H_RX_BIAS net name is merged into PIC_RB0_VREF. VREF remains separate from VDD and RC1.

Q1 rail resolved by user: V011–V014/Q1.L connects to MX512H pin4 VDD, modeled H_VBAT motor supply. Distinct from TP103/H_VDD logic rail. No rail question remains pending. Q1 identity/polarity remains unverified; retain explicit Q1.L–R43.2 exclusion.

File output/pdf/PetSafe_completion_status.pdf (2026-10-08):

PetSafe | Evidence-qualified reconstruction | v0.9.9 | 1

# Schematic completion status

PetSafe 100-1339 R03 A | v0.9.9 | 2026-10-08
All catalog entries are drawn on one sheet. The remaining questions are listed explicitly below. This is a partially verified reconstruction, not a completed hardware validation or a routed PCB.
Coverage | Open connections | Values / packages
150 entries; 1 A2 sheet; 20 stock + 4 custom symbol definitions. | 10 populated-entry pads + 18 DNP pads. 0 open PIC pads in the model. | 44 ceramic values and L1/L2 unknown; 147/150 footprints assigned.

## Power rails - current names

Name | Known path
BATTERY+ | Battery positive -> Q1 single pad/native3 (candidate drain); TP14/R43.2 on the raw side.
VSYS | Q1.L/native2 -> U5/MX512H pin4; L1.1 and L2.1 supply sides.
VDD | TP103, PIC20/C32, U5 pin1/VCC, V064/V063/V075/V082.
VREF | TP104, PIC21/RB0/V026, PIC4/RA2/V035/C39, R21.2/V071.
GND | Battery negative and ground copper.
L1/L2 share the VSYS supply side. Their opposite ends are not shorted together. H_RF_VDD, H_LDO_IN, H_RX_VDD and H_PIR_VDD describe local branches; these are not additional confirmed independent supplies. Rail voltages have not been measured.

## Recommended next checks

1. Identify which D3 pad joins V082/VDD (E02).
2. Resolve D2, C6/Q8, and the isolated button/antenna paths.
3. Cross-check receiver/PIR branches and candidate pin functions.
4. Recover RF/tuning values, then other passives and missing package geometry.

## Validation and limits

83 modeled net partitions match KiCad 10.0.5. ERC retains 36 findings: 28 open pins, 3 isolated labels and 5 undriven power checks. No artificial NC/power flags hide gaps. All 26 original photo hashes are unchanged. This proves file consistency, not all physical connections.
The three isolated labels are H_ANT_B (ANT2), H_D1_FREE (D1.R) and H_BUTTON_MCU (R41.1). A PIC pin can have a local net and still lack an onward destination. Question-mark count is not a completion metric.

# Priority circuit gaps

## E01 - D2 / marking 4P

Known: The user clearly reads 4P; its three physical pads are retained by a numbered stock placeholder.
Uncertain: Identity, internal pin functions and all three external connections. The earlier BAV99 clamp assumption is withdrawn. Next: With power disconnected, take the six directed diode-mode readings between D2 pads shown in the existing D2 guide. Then trace only the terminal indicated by the result.

## E02 - D3 / V082 supply association

Known: A7 supports a BAV99 candidate. User continuity joins V082 to the board VDD test point.
Uncertain: Which physical D3 terminal reaches V082. Current D3.L=GND, D3.R=H_RX_VDD and D3.S=H_RX_RF_SENSE are provisional; none is presently assigned to VDD.
Next: Measure V082 to each of D3's three pads. Record low-ohm continuity separately from diode/resistive readings.

## E03 - RF supply / Q8 / C6

Known: Q8 centre B2/native5 is GND via V113/V115. V114 is U2.T2/native2 GND. Outer Q8 pads are joined by the earlier low-resistance result.
Uncertain: C6.1 route and Q8 source-supply path. F-P=10 ohm supports a supply-related path but does not establish a direct copper join. Exact Q8 maker remains a candidate.
Next: Start with C6's non-ground pad and the L1 output/Q8 supply node; record resistance both ways. Use the existing labelled Q8 photo, not the withdrawn C6-to-output wire.

## E04 - Antenna / five tuning cells

Known: All five PIC control inputs are mapped. Seven capacitor-midpoint comparisons gave OL.
Uncertain: Remote paths of the five capacitor midpoints and ANT2; the modeled tuning network is not yet a verified closed antenna circuit. Transistor orientation is provisional.
Next: Follow one cell at a time from ANT1/ANT2 toward a visible capacitor pad or via. Choose the next specific pair from the photographs; do not repeat a broad midpoint sweep.

## E05 - Button circuit

Known: R41=331 gives nominal 330 ohm. One modeled button side is GND.
Uncertain: R41.1/H_BUTTON_MCU has no destination. S1 common lead pairs are currently assumed from a normal tactile switch.
Next: With power disconnected, determine S1 common pairs released/pressed; then trace R41.1 toward the MCU side.

## E06 - Local-only PIC / discrete nodes

Known: Every PIC pad has a modeled local net. PIC2 reaches C25/V031; PIC14 reaches TP11; PIC18 reaches TP17. Uncertain: Onward roles of those three nodes, D1.R/H_D1_FREE, C26.1 and TP9.1. Local connectivity is not proof that these are intentionally unused.
Next: Inspect the matching opposite-side vias first, then request only a specific continuity pair for each unresolved branch.

# Other routing and identity gaps

## E07 - PIR interface / U6 / J3

Known: C2NM supports an S-812C33AMC candidate. V067 reaches J3.1/red and the U6A option pad; V063 reaches regulated VDD. U6 ground is supported by the user readings.
Uncertain: U6 VIN/VOUT external branches, NC-pad external ties, actual PIR voltage, J3.2/.3 roles and Q2 signal path. The model uses J3.2=GND and J3.3=raw signal; blue/black colour alone is not confirmation or grounds to swap them.
Next: First verify J3.2 and J3.3 against GND and the modeled signal endpoint; then check U6 supply/output continuity. Powered voltage checks come after this routing audit.

## E08 - Receiver / bias / Q7

Known: PIC12/RC1 reaches R18 via V053-V070. V064-V075 is continuity; V064-V070=11.2 kohm supports the R18+R19 path. VREF reaches R21.2, PIC21 and PIC4. TP6/C18.2 is separate from U3.5/C18.1.
Uncertain: Q7 terminal selection and power-switch role, receiver feedback/coupling branches, and R22.2/R23.2/R48.2 VREF ties remain inferred. TP6/V072 and U3.5/V079/V080 lack fully verified onward roles.
Next: Resolve E02 first because it may change receiver power. Then confirm the three provisional VREF bias branches and selected U3 feedback endpoints; retain C18 as a component boundary.

## E09 - Power input / Q1 / rail voltages

Known: BATTERY+ and VSYS are separate. User confirms Q1.L to U5.4 and both L1/L2 supply sides on VSYS. VDD TP is the separate logic rail. R1A matches FMOS3401A marking.
Uncertain: Exact Q1 maker and gate operation, unmeasured rail voltages, and U1 enable/option branches. Reverse-polarity protection is an interpretation, not a powered test.
Next: Retain the confirmed rail split. Cross-check the Q1 gate/R44 path and U1 enable wiring before a targeted voltage test.

## E10 - ICSP protection / D6 / J1

Known: D4/D5=5U supports SD05 TVS candidates. D6=G3 has at least two documented Zener candidates. ICSP signal routes are photo-derived.
Uncertain: Both D6 pad routes, D6 exact voltage/polarity, and J1 physical pin-number orientation including square-pad/VPP correspondence.
Next: Measure D6 pads to the adjacent PIC/ICSP nodes. Confirm J1 pad order against the board labels before relying on connector numbering.

## I01 - Candidate identities / transistor pin maps

Known: Primary datasheets and marking evidence are recorded; custom symbols use the selected candidate pin tables. Uncertain: Short markings do not uniquely prove manufacturers. Candidate choices and some B/E/C or MOSFET source/drain assignments remain qualified. Western alternatives are redesign options, not identities of fitted parts.
Next: Use electrical pad behavior and package/marking evidence for specific candidates. Do not request sharper photos where the existing marking is already legible.

## I02 - LED / motor connector

Known: V127 reaches the photo-selected LED common pair; the two PIC LED drives are mapped. MX512H OUTA/OUTB map to the modeled motor connector.
Uncertain: LED internal polarity/colour mapping and J5 physical A/B lead polarity remain provisional.
Next: Check LED pad pairs in diode mode and record emitted colour. Match J5 wire positions to U5 outputs by continuity.

# Values, mechanics and scope

## V01 - Unmarked passive values

Known: C5 is 470 uF / 16 V; 38 fitted resistors have nominal marked values. R8 full-body dimensions support 0603 and C11 dimensions support 1206.
Uncertain: 44 fitted ceramic capacitances and L1/L2 type/value remain unrecovered. Capacitor voltage rating/dielectric and resistor tolerance/power rating are also not established by geometry.
Next: Use the LCR meter first on C6 and one tuning cell, recording frequency/mode and in-circuit status. Isolate one terminal only if an individual value is needed and the network reading cannot resolve it.

## M01 - Package geometry / PCB reproduction

Known: 147 of 150 catalog entries have candidate stock footprints. R8 and C11 have user dimensions.
Uncertain: C5, S1 and LED1 footprints are blank. Other families, connector pitch, test-pad drills, switch lead span and exact board geometry are partly photo-based.
Next: Measure C5 can diameter/lead spacing, S1 body/lead span and LED1 body/pad pitch. Refine other footprints only where a photo scale or ruler contradicts the selected family.

## D01 - Empty options

Known: 18 open pads belong to unpopulated options, not missing fitted chips.
Uncertain: Optional-pad routing is incomplete; values and intended uses may remain unknowable without another board variant. Next: Record option copper where visible; defer measurement unless it affects a populated net.

## F01 - Function / internal layers / daughterboard

Known: A one-sheet schematic and photo/via evidence exist; 83 modeled net partitions match the native schematic. Uncertain: No powered functional validation, actual layer stack or routed KiCad PCB has been created. The PIR daughterboard internal circuit is not reconstructed. MCU firmware behavior and operating timing are not established.
Next: Finish priority electrical gaps first. Then test defined functions/voltages and decide whether physical PCB reproduction and daughterboard reverse engineering are needed.

## Every unrecovered ceramic value

C1, C2, C6, C7, C8, C9, C10, C11, C12, C13, C14, C15, C16, C17, C18, C19, C20, C21, C22, C23, C24, C25, C26, C27, C28, C29, C30, C31, C32, C33, C34, C35, C36, C37, C38, C39, C40, C41, C43, C44, C45, C46, C47, C48
C5 is already 470 uF / 16 V. In-circuit LCR readings may include parallel components and semiconductor paths; record frequency, mode and whether a lead was isolated. Geometry cannot establish capacitance, dielectric or voltage rating.

# PIC connections

Physical package pins. All have modeled local nets; the evidence column distinguishes confirmed endpoints from photo-derived or incomplete branches. Use the separate numbered photo guide for physical locations.

Pin | Function | Local destination / evidence
1 | RE3/MCLR | J1 VPP; mapping inferred; D6 route missing
2 | RA0 | C25 signal pad / V031; onward destination unknown
3 | RA1 | R28 + R29 + TP7; user meter / visible trace
4 | RA2 | VREF TP via V035; user confirms via-to-TP; C39.1 local photo route
5 | RA3 | V036-V108 to R14; user continuity report
6 | RA4 | V037-V102 to R15; user continuity report
7 | RA5 | V039-V097 to R16; user continuity report
8 | VSS | GND / V041 photo anchor
9 | RA7/OSC1 | Y1 oscillator; photo-derived
10 | RA6/OSC2 | Y1 oscillator; photo-derived
11 | RC0 | V047-V091 to R11; user continuity report
12 | RC1 | R18.1 via V053-V070; user-confirmed; VREF link explicitly rejected
13 | RC2 | TP3 via V049; user-confirmed; existing R10 branch photo-derived
14 | RC3 | TP11; visible route; onward destination unknown
15 | RC4 | V022-V016 to U5 pin2 / INA; user-confirmed
16 | RC5 | V023-V019 to U5 pin3 / INB; user-confirmed
17 | RC6 | R13; user meter / visible trace
18 | RC7 | TP17; visible route; old R13 guess withdrawn
19 | VSS | GND / C32 / V045 photo anchor
20 | VDD | V042 to board VDD TP user-confirmed; C32.1 local photo route
21 | RB0 | VREF (TP104), V026 and V071/R21.2; user-confirmed
22 | RB1 | TP2 / R31; user meter / visible trace
23 | RB2 | TP1 / R30; user meter / visible trace
24 | RB3 | R4; photo-derived; sensing role remains inferred
25 | RB4 | TP4 / V017 / R42.1 / R44.1; user continuity; C41 photo-derived
26 | RB5 | TP10 / R35; user meter / visible trace
27 | RB6/CLK | ICSP CLK / D4 / R32; photo-derived
28 | RB7/DAT | ICSP DAT / D5 / R40; photo-derived

## Every remaining open pad

Populated entries: C26.1, C6.1, D2.L, D2.R, D2.S, D6.1, D6.2, TP9.1, U6.L1, U6.L2.
Empty options: C42.1, C42.2, C49.1, C49.2, J6.1, J6.2, Q9.S, R36.1, R36.2, R46.1, R46.2, R47.1, R47.2, U6A.L, U6A.R2, U7.1, U7.2, U7.3. U6.L1/L2 are candidate internal NC pins 4/5; external ties remain unknown. Photo pad S means single pad, not necessarily source. Current completion checklist includes closure criteria and the full per-component audit. Sources: reconstruction.json, remaining_work.json, via_audit.json, v099_net_changes.json, native validation and the preserved earlier measurement records.

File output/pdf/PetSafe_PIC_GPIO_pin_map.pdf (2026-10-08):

# PIC GPIO: 0 open pads in the model

U4 / PIC16F18855 / 28-pin SOIC | Pin numbers are physical package numbers, not schematic drawing order.
Orange = onward destination unknown | Grey = already represented, sometimes still inferred

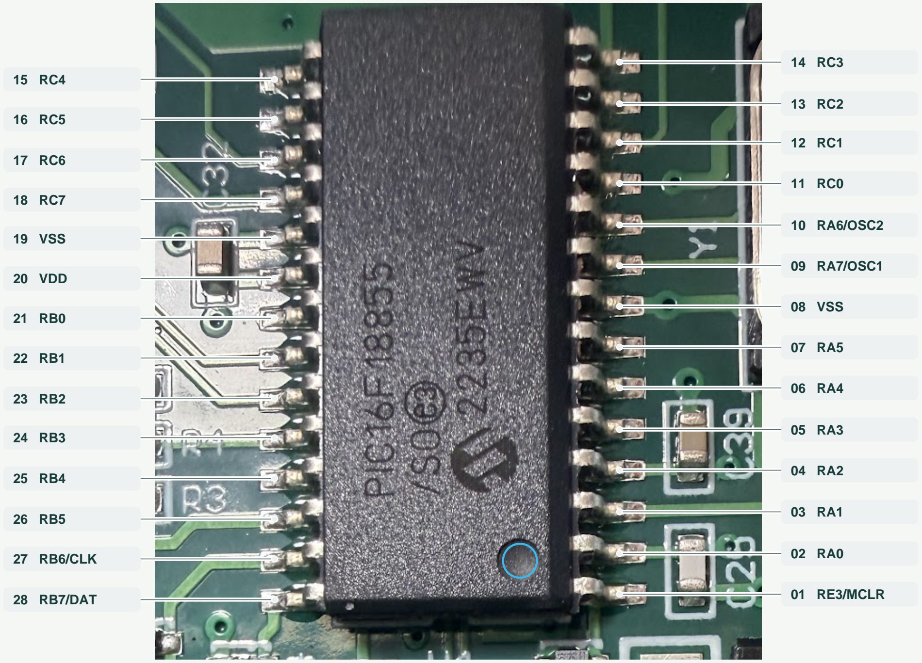
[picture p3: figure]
01 RE3/MCLR; 08 VSS; 09 RA7/OSC1; 10 RA6/OSC2; 19 VSS; 20 VDD; 27 RB6/CLK; 28 RB7/DAT

Orientation: pin 1 is at the lower right, beside the round moulded dot (blue ring). Right row: bottom to top 1-14. Left row: top to bottom 15-28. Do not mirror the image.

# Connection checklist

All PIC pads have modeled local destinations.

Pin | GPIO | Current observation

Latest confirmed: 12/RC1 -> R18 via V053-V070; 13/RC2 -> TP3 via V049; 21/RB0 -> VREF (TP104) via V026. Now also V035/4/RA2/C39 to VREF and V042/20/VDD to board VDD. V053-VREF is rejected.

Tuning controls resolved: 5/RA3 -> R14 (V036-V108); 6/RA4 -> R15 (V037-V102); 7/RA5 -> R16 (V039-V097); 11/RC0 -> R11 (V047-V091). Existing 17/RC6 -> R13 retained.
Motor controls resolved: 15/RC4 -> U5.2 INA (V022-V016); 16/RC5 -> U5.3 INB (V023-V019). User-reported connections.
User meter + visual trace: 3-R28/R29/TP7; 17-R13; 22-TP2; 23-TP1; 25-TP4. 26-TP10 corroborated. Numerical ohms not supplied.
12: R18/V053-V070 | 21: VREF | 2: C25 | 4: VREF/C39 | 14: TP11 |
18: TP17 | 24: R4 | 26: TP10/R35 | 27/28: ICSP nodes.

These are not included in the orange pins. No visible route is not proof of NC. No no-connect flags were added. RP7 wording interpreted as photographed TP7.

Unpowered checks: disconnect battery and programmer. Compare low readings with your shorted-probe baseline (about 0.5 ohm). Reply example: U4.3 -> Rxx, left pad -> 0.7 ohm. A visual trace is useful too. Give exact pads and actual ohms, rather than only a beep.
Orange lines are callout leaders, not traced copper. Source: your new close-up; original photograph pixels retained.

Pinout: Microchip DS40001802G, page 4. Current schematic: (https://ww1.microchip.com/downloads/en/DeviceDoc/40001802G.pdf#page=4) v0.9.9. Date: 2026-10-08. Full details: evidence/pic_gpio_request.json.

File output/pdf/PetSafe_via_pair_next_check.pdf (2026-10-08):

# Confirmed: RC1 reaches R18 via V053-V070

PIC12/RC1 -> V053 -> V070 -> R18.1. V053-VREF explicitly rejected; RB0/VREF stays separate.

Recorded from your continuity report; no numerical ohms supplied. This page now locates the completed connection. No repeat measurement requested. V067 also reaches J3 pin 1/red wire, on H_PIR_VDD.

Test | Fixed probe | Moving probe | What this tests | Recorded result
F1 | V053 | V070 | PIC12/RC1 to R18.1 control input | Connected (user checked)

What this resolves: RC1 supplies the R18 control input in the reconstructed circuit. The earlier photo-only RC1-to-VREF link was wrong and is withdrawn. RC2 now reaches TP3; RB0 reaches VREF (native TP104). All PIC pads have modeled local destinations; other circuit gaps remain.

A - V053: PIC pin 12 / RC1 | B - V070: R18 control input

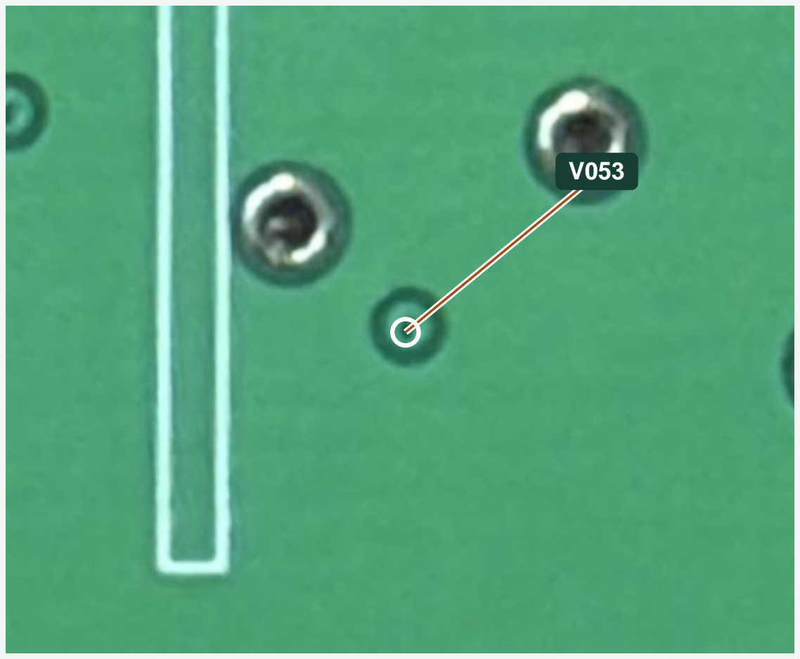
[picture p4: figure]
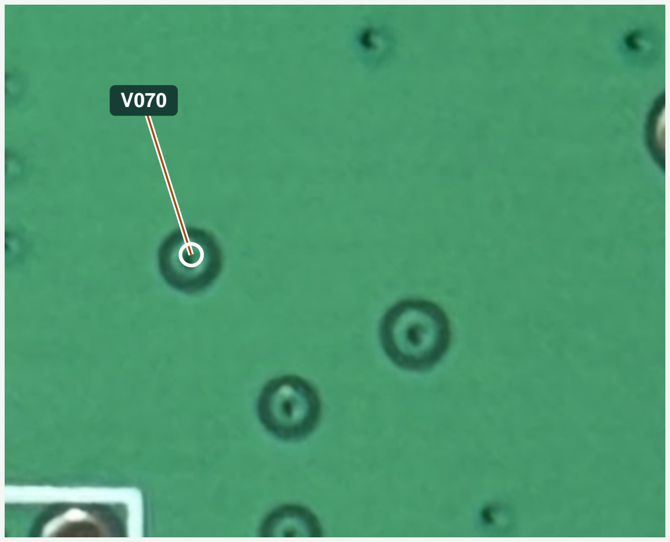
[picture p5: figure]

Evidence limits: V053-V070 is user-confirmed. The existing local V070-to-R18.1 pad association is retained. Q7/R19 base-emitter topology remains a photo/resistance-supported reconstruction, not a powered functional test.

Rear mosaic is already mirrored to match the front. Circles mark vias; leaders are annotations, not traces. Use board landmarks and the paired photo locator to zoom. The completed V064-V070 reading is resistive, not direct continuity.

No GPIO batch pending. Remaining work includes other hidden continuations, candidate identities, values and package geometry.

PetSafe | 8 October 2026 | Basis v0.9.9 | Completed result locator | V053-V070 confirmed; V053-VREF rejected

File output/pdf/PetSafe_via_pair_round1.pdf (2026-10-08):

# 11 useful readings, then we choose the next step

Start with the tuning controls, receiver reference/supplies, and the repeated capacitor cells.

PetSafe | 8 October 2026 | Basis v0.9.5 | Proposed pairs only; no unmeasured connection added | 1

## 1 Set the contact baseline

Disconnect battery and programmer. Short the probes, then measure the known V022-V016 connection once. Write both readings. Use actual ohms, kohms, OL, or changing; a beep alone can include a resistor path.

### Shorted: __________ ohm

### V022-V016: ________ ohm

## 2 Measure this first batch

Keep probe A fixed within each group. Stop A at the first verified direct hit; complete all B and C rows.

Test | Probe A | Probe B | Why this pair | Reading | Reversed if low
A1 | V047 | V108 | RC0 to R14: possible tuning control | ________________ | ________________
A2 | V047 | V102 | RC0 to R15: next tuning candidate | ________________ | ________________
A3 | V047 | V097 | RC0 to R16: next tuning candidate | ________________ | ________________
A4 | V047 | V091 | RC0 to R11: next tuning candidate | ________________ | ________________
B1 | V053 | V071 | VREF-labelled pad to R21 receiver bias | ________________ | ________________
B2 | V064 | V063 | Regulated VDD to R37/R39 feed | ________________ | ________________
B3 | V064 | V070 | Regulated VDD to R18 receiver feed | ________________ | ________________
C1 | V090 | V095 | Capacitor bank: C46/C47 to C43/C44 | ________________ | ________________
C2 | V090 | V100 | Capacitor bank: C46/C47 to C16/C29 | ________________ | ________________
C3 | V090 | V103 | Capacitor bank: C46/C47 to C13/C14 | ________________ | ________________
C4 | V090 | V107 | Capacitor bank: C46/C47 to C10/C11 | ________________ | ________________

## 3 Interpret, without turning guesses into wires

A direct hit should be stable and close to the connected-pair baseline, with probes reversed as a cross-check. Tens/hundreds of ohms,
polarity-dependent readings or charging behaviour do not prove direct copper. Even near-zero may include a zero-ohm link or an
inductor. | | | | | A is a candidate sweep: we know RC6 reaches R13, but do not know the other four assignments. Do not infer the last pair by elimination

without measuring it.

## After these results

We will test RC2 and accessible TP11/TP17 against the unmatched tuning controls; choose supply/reference alternatives only when needed; and test one representative of each confirmed capacitor group to ANT1/ANT2. V011-V015 is already excluded. DNP V067 can wait.

Photo locator: docs/VIA_PAIR_TESTS.html. Two zoomed points per test, with a copyable reply form. Photo atlas on page 2.

# Where to put the probes

## A anchor / B1 reference

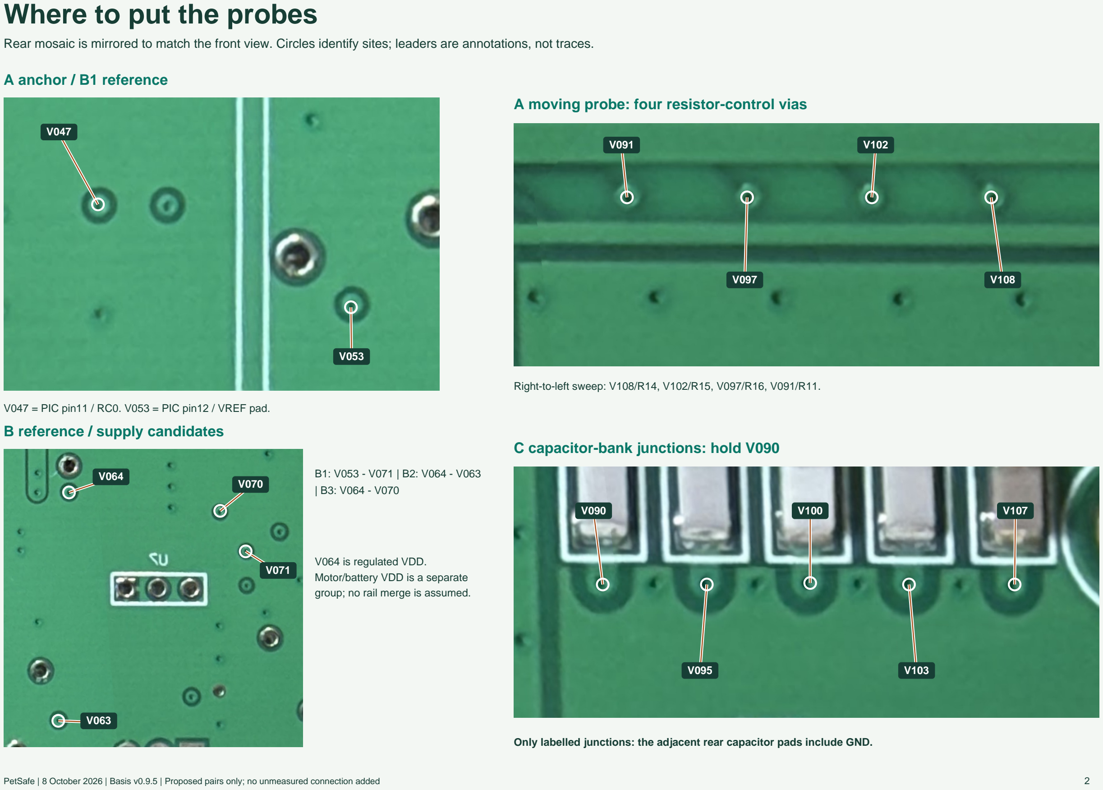
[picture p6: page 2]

Rear mosaic is mirrored to match the front view. Circles identify sites; leaders are annotations, not traces.

PetSafe | 8 October 2026 | Basis v0.9.5 | Proposed pairs only; no unmeasured connection added | 2

V047

V053

V047 = PIC pin11 / RC0. V053 = PIC pin12 / VREF pad.

## A moving probe: four resistor-control vias

V091

V097

V102

V108

Right-to-left sweep: V108/R14, V102/R15, V097/R16, V091/R11.

## B reference / supply candidates

V063

V064 | V070

V071

B1: V053 - V071 | B2: V064 - V063
| B3: V064 - V070

V064 is regulated VDD.
Motor/battery VDD is a separate group; no rail merge is assumed.

## C capacitor-bank junctions: hold V090

V090

V095

V100

V103

V107

Only labelled junctions: the adjacent rear capacitor pads include GND.

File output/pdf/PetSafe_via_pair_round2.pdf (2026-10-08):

# Four next checks after your results

Controls and V064-V063 confirmed. V053-V071 rejected. V090 to V095/V100/V103/V107: all OL.

Battery and programmer disconnected. Report actual resistance, OL or changing. Compare near-zero readings with your probe/contact baseline and reverse probes to check. A beep alone is not proof of a direct connection.

Test | Fixed probe | Moving probe | What this tests | Reading / reversed if low
B3 | V064 | V070 | Regulated VDD to R18 receiver feed | ________________________
C5 | V095 | V100 | C43/C44 junction to C16/C29 junction | ________________________
C6 | V095 | V103 | C43/C44 junction to C13/C14 junction | ________________________
C7 | V095 | V107 | C43/C44 junction to C10/C11 junction | ________________________
B3 Is the receiver feed also on regulated VDD? | C5-C7 Do the other four junctions share a node?

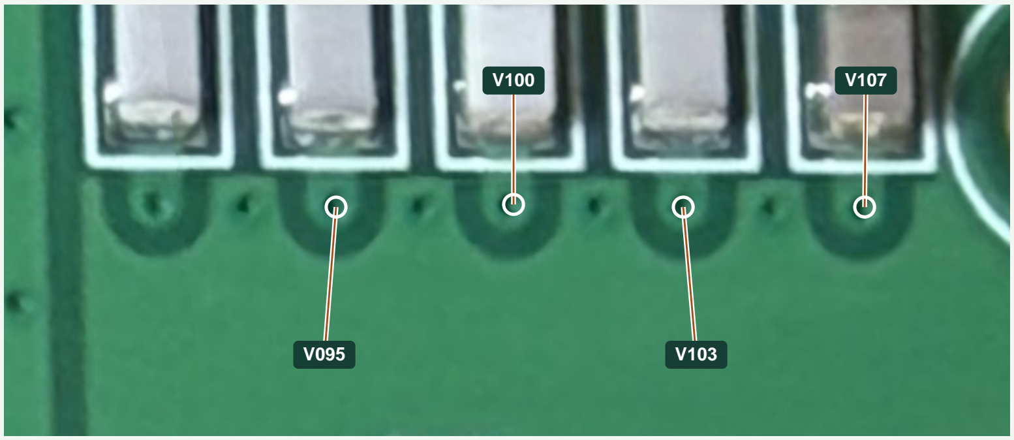
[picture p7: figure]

Keep one probe on V095 for all three new C readings. If all are OL, stop broad pairwise testing; we will trace toward antenna/component endpoints instead.

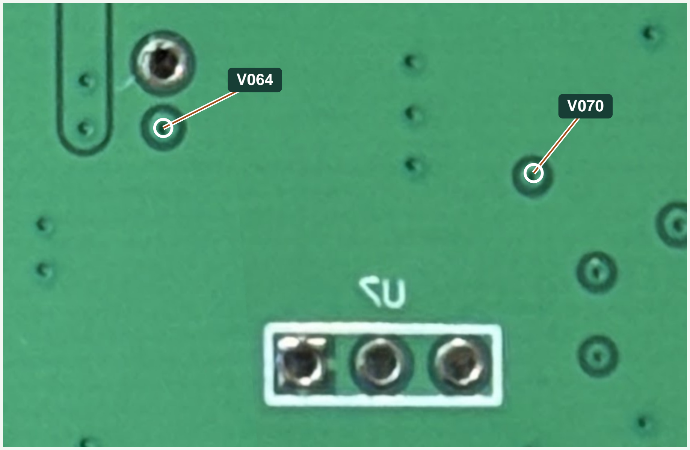
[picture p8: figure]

Photographs: rear mosaic already mirrored to match the front. Circles mark vias; leaders are annotations, not traces. Use the paired photo locator for zoomed views. Near-zero can also include an inductor or zero-ohm link.

Next: choose antenna/group tests and remaining RC2/RB0 candidates from these results. Q1 VDD rail choice is still pending.

PetSafe | 8 October 2026 | Basis v0.9.6 | Proposed pairs only; no unmeasured connection added

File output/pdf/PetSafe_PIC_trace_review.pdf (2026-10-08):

# PIC: connections recovered from existing photos

Callouts mark endpoints; the straight leaders are annotations, not fabricated copper tracks.

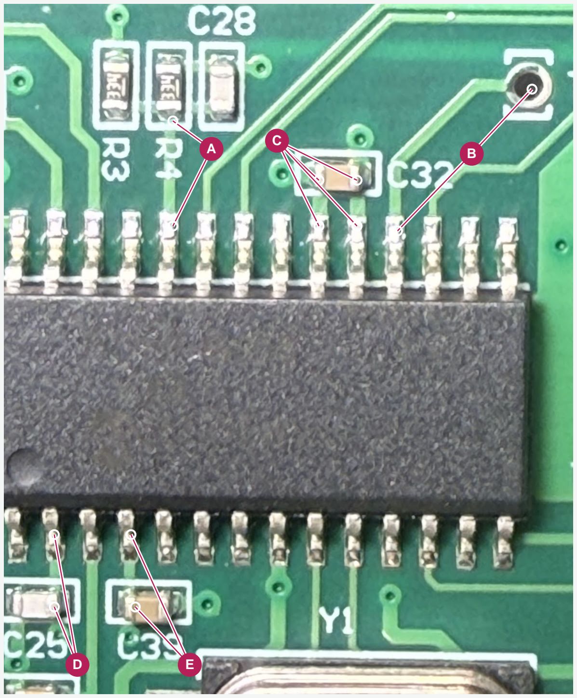
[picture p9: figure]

PetSafe v0.7 | 2026-10-08 | Photo evidence, not continuity verification | Page 1/2

### A - pin 24 / RB3 to R4 lower pad

Direct visible copper. R4 was incorrectly tied to ground; that tie is removed.

### B - pin 18 / RC7 to TP17

Direct local trace. The lowest top-edge continuation to R13 is probable across overlapping photos; retained as a qualified inference.

### C - C32 across pins 20 and 19

VDD and VSS respectively. C32 moved from the PIR block to the PIC supply. Its 100 nF value remains an estimate.

### D - pin 2 / RA0 to C25 right pad

The old VDD connection and generic 100 nF value are withdrawn.

### E - pin 4 / RA2 to C39 left pad

The old VDD connection and generic 100 nF value are withdrawn.

C26: the old VDD tie is also withdrawn. Its signal-side route is still unresolved. Opposite capacitor-pad ground assignments remain hypotheses.

# Programming lines and the empty option network

The same programming pins may serve other firmware functions during normal operation.

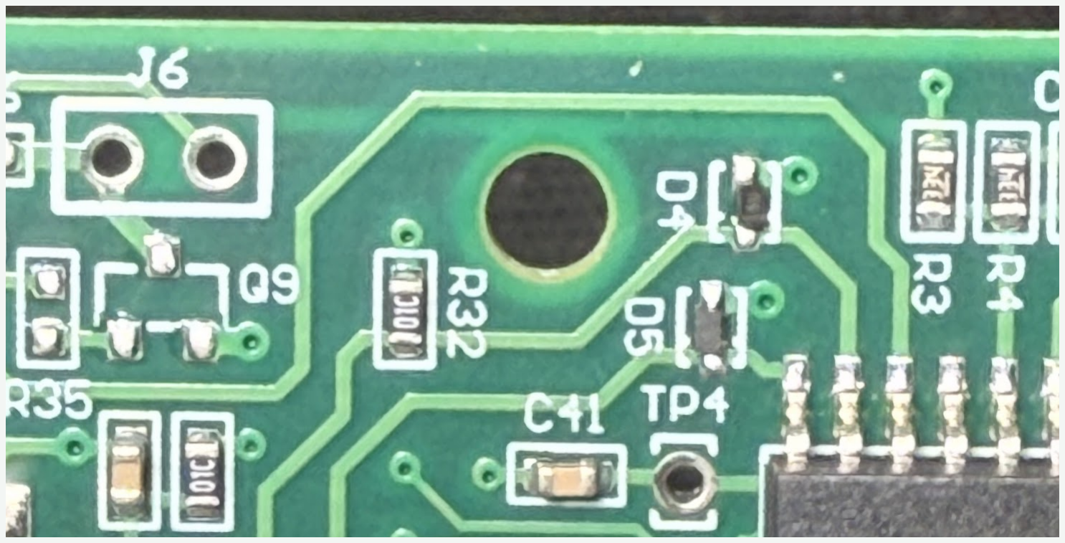
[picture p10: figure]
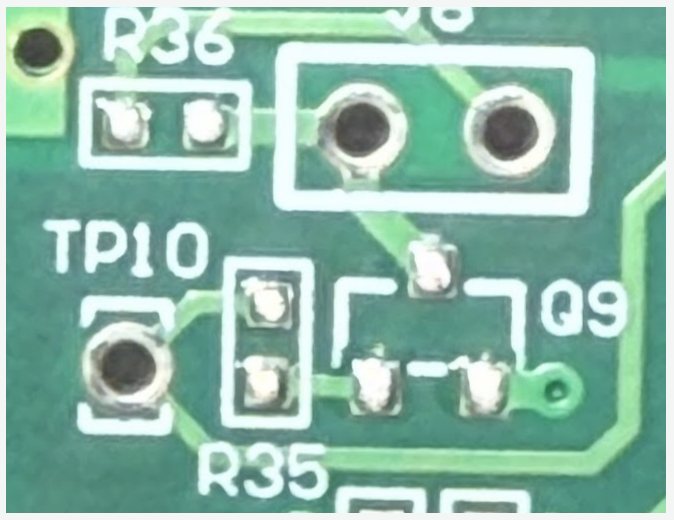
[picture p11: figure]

PetSafe v0.7 | 2026-10-08 | Photo evidence, not continuity verification | Page 2/2

Pin 27 / RB6 / ICSP clock
The lower pad of D4 and lower pad of R32 join this pin. The earlier R32-to-PIR-supply tie is removed.

Pin 28 / RB7 / ICSP data
The lower pad of D5 and upper pad of R40 join this pin. The earlier R40-to-VDD tie is removed.

Pin 26 / RB5 to TP10 and R35 upper
Follow the long loop outside D4, across the board edge and below Q9. It joins TP10. R35 lower instead joins Q9 lower-left; the empty resistor separates these nodes.

C41 to TP4
The right capacitor pad joins TP4. The continuation disappears under U4, so the previous antenna-net assignment is withdrawn.

What a clearer photo would help resolve
Take a straight-down, full-resolution PIC-area shot with both pin rows and nearby parts in focus. Also capture the top-edge tracks toward R11-R16 and LED1 in overlapping close-ups. Keep the actual board edge in frame.

The upper image is IMG_2437; the lower is IMG_2438. Both retain their original pixels and orientation.

Routes under the IC body or into vias may still require a few targeted continuity checks; a sharper photo cannot expose covered copper.

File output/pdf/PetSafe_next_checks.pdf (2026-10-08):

# D2: identify the junction pattern

Battery and programmer disconnected. Use diode-test mode; report volts or OL.

## Record these six readings

RED probe BLACK probe | Reading
X | Y | ________
Y | X | ________
X | Z | ________
Z | X | ________
Y | Z | ________
Z | Y | ________

X/Y/Z identify physical solder pads only. They do not assume pin numbers or internal functions.

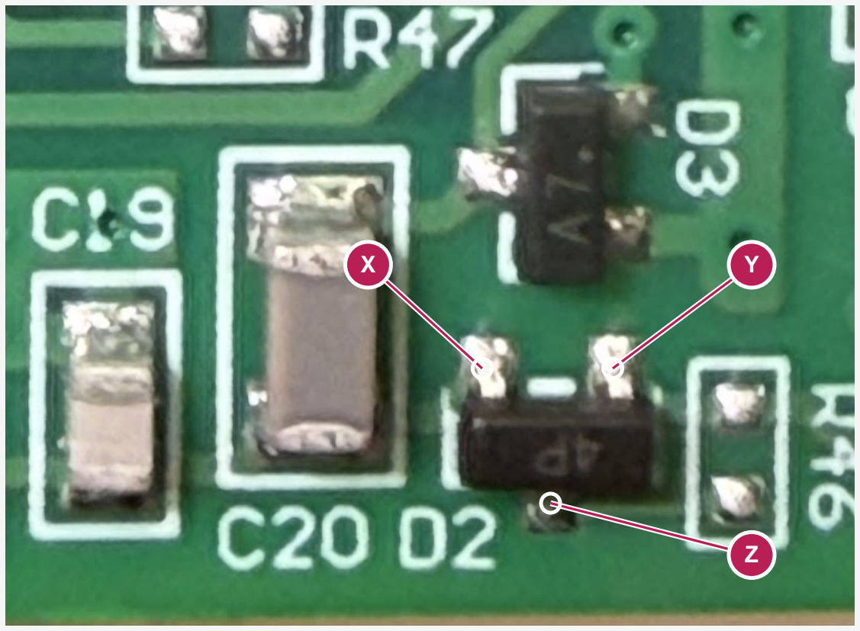
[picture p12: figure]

D2 is the three-terminal part below D3 in this photo. Touch the circled metal pads, not the black body. Report a changing reading too. No desoldering is requested in this round.

In-circuit results can include other paths. This test narrows the candidates; it does not by itself prove a transistor versus a dual-diode package.

### Two extra observations

C5: read/photo the sleeve value and voltage; report can diameter and lead-centre spacing if accessible. R8: measure body length and width, excluding solder, to check the 0805 estimate.

PetSafe 100-1339 R03 A | v0.6 | Original photo pixels with vector callouts | 2026-10-08

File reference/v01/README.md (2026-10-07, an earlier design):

# PetSafe 100-1339 R03 A — reverse engineering v0.1

## What this package is

A photographic atlas, a native KiCad **initial capture**, an observed-part inventory, and a targeted continuity worksheet for Sergey's PetSafe PPA19-16811. It is **not a complete or electrically verified schematic** and is not a manufacturable replacement-board design.

Open `index.html` for the photographs and searchable inventory. Open `schematic/PetSafe_1001339.kicad_pro` in KiCad (8 or later is the intended target), then the root schematic. Symbols are embedded and also supplied as a local symbol library. There are six child sheets. No external symbol library is required to display the captured symbols.

## Current evidence

- 150 catalog entries: observed designators, test points, named-pad aliases and empty footprints. This is NOT a count of 150 fitted electronic parts.
- 29 short, locally visible net fragments encoded in the schematic.
- Zero continuity-confirmed nets; 290 modeled pads remain unresolved in this revision.
- Known ICs: U4 PIC16F18855; U5 MX512H; U3 SGM8542XS. U1/U2/U6 and several short-marked devices remain unidentified.
- Unmarked capacitor values are UNKNOWN. Empty footprints are DNP, not zero-ohm links.
- The separate PIR daughterboard is included in the source photographs but is **not reconstructed** yet.

## Photograph outputs

`front_registered.png` combines a perspective-rectified overview with registered detail photographs. Each output pixel is taken from a selected source; there is no inpainting or invented copper. Seams are visible where the selected source changes. `front_source_ids.png` and `front_registration.json` record provenance.

`back_unrectified.png` is the sequential rear mosaic. `back_mirrored_registered.png` aligns the rear to the front for comparison. This is approximate registration, NOT a dimensional or electrical measurement. `back_readable.png` restores readable rear orientation. Full-size JPEG companions support the browser atlas. The original JPEG uploads are included byte-for-byte under `photos/originals/` with SHA-256 checksums.

The compact ZIP omits the large PNG mosaics; full-resolution JPEG companions and original photos are included. Lossless PNG front/rear mosaics are provided separately in the chat. Stitching scripts regenerate PNG outputs from the original photos.

## Layer count

Unconfirmed. The rear looks like a broad copper plane and numerous signal routes disappear at vias without a visible rear track. This raises the possibility of inner routing layers, rather than establishing a two-layer stackup. It is not photographic proof of a four-layer stackup. Electrical endpoint reconstruction is possible without knowing the physical layer used by each net.

## How evidence is represented

`VISUAL_LOCAL`: a short trace is visible in a specific source photograph. This is weaker than continuity confirmation and can be corrected.

`CANDIDATE_NOT_CONNECTED` / `HYPOTHESIS`: plausible relationship recorded outside the schematic. No wire is drawn for it.

`UNRESOLVED_NOT_NC`: the symbol pin is left open because its connection is not known. There are no no-connect flags to make these uncertainties disappear.

Known package pins use datasheet numbering. Unknown ICs/transistors use physical pad IDs; their source-photo orientation is recorded. Passive pin 1 is left/top and pin 2 right/bottom in the cited upright detail photo; this is a reconstruction convention, not a verified PCB-footprint pad numbering system. Multiple photographic ground pads are not silently collapsed into one electrical node.

## Validation performed

`evidence/validation.json` records balanced/native-file structural parsing, existence of child sheets, unique catalog references, matching symbol pins, valid model endpoints and the absence of fabricated no-connect flags. **KiCad is not installed in the execution environment: the native editor has not opened the files, and native ERC/netlist export were not run.** SVG previews are independently generated from the same data; they are not KiCad renderings.

## Continue the work

Start with `docs/MEASUREMENTS.md` and fill `evidence/measurements_round1.csv`. `CODEX_TASK.md` gives the continuation task. The immediate goal is reconstructing the original board, not choosing an ESP32 retrofit circuit.

The generators run with Python 3. `build_reconstruction.py`, `generate_kicad.py` and `validate_structure.py` use the standard library. Photo tools additionally use Pillow, NumPy and OpenCV. Do not overwrite manual KiCad edits blindly: the JSON/CSV model and the generator must be updated in parallel before regenerating.

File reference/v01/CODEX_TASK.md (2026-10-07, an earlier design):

# Codex task: complete the PetSafe as-built schematic reconstruction

## Goal

Continue the attached `PetSafe_RE_v01` project into a complete, evidence-backed KiCad schematic of the existing **100-1339 R03 A** main PCB, then the **100-1398 R001** PIR daughterboard. Preserve original reference designators. This is NOT an ESP32 add-on design task.

## Starting point

Read README.md and AGENTS.md. Inspect the original photographs, not just stitched seams. Open `schematic/PetSafe_1001339.kicad_pro`. The current generated files have only structural validation; first establish that they open in native KiCad and fix any format issues without inventing electrical content. Then export a native netlist and SVG/PDF preview and record exactly which checks ran.

There are 150 catalog entries and 29 visual local net fragments, not a finished netlist. Pin identifiers for unknown packages are physical placeholders. The independent SVG preview is not evidence that KiCad accepted the project.

## Work autonomously where the evidence permits

1. Audit the photo-derived component inventory against all original images. Correct duplicated/missing aliases, reference-designator readings, marking transcription, population status and package pin orientation. Do not invent components merely because a reference number is skipped.
2. Use manufacturer datasheets to resolve IC identities. U3 is SGM8542XS, U4 PIC16F18855 (28-pin SOIC), U5 MX512H. U1 marking PPEK; U2 approximately C14R with six leads; U6 marking uncertain. Short marking matches with a different pin count/package are not acceptable identifications.
3. Expand only genuinely visible copper connections. Each electrical net must retain photo and/or measurement evidence. Update evidence/reconstruction.json, the generator/model and KiCad together. Do not populate a schematic by copying a datasheet application circuit.
4. Incorporate Sergey's measurements from measurements_round1.csv. Use actual resistance readings, not beeper-only guesses. Direct copper, semiconductor paths and resistance through another component are different findings.
5. Trace the full ground/supply domains, ICSP header, motor inputs/outputs, crystal, user switch/LED, PIR interface, receiver and antenna drive/tuning networks. Many apparently isolated vias may connect through hidden layers; the physical route need not be known if endpoint continuity is proven.
6. After the first measurement batch, request only the next small high-information batch with precise pin/pad names and annotated crop references. Complete one tuning branch (Q3, C10/C12/C11) before assuming the topology of the other four. Do not assume those three capacitors are simply parallel.
7. Move from the provisional component-grid capture to readable functional circuitry as nets become established. Keep an unresolved-pins register until every fitted component pin and intentional empty footprint is accounted for.
8. Add the daughterboard as its own hierarchical sheet, preserving its local designators without collisions. Request a clear opposite-side photograph only if needed; do not infer its three-wire protocol or logic level from wire colors.

## Deliverables

A native KiCad project that has actually been opened/exported; readable circuit sheets; an as-built BOM with unknown fields explicit; an evidence-linked netlist; the measurement history; an unresolved-items list; and an updated photo atlas. Capacitor values may require later LCR/isolated measurements. Connectivity completion and value completion must be reported separately.

## Acceptance conditions

No fabricated wires/values, no ambiguous part identified solely by a short code, no unverified ground merges, no NC flags used to hide unknowns. Native exports and ERC results must be reported honestly. Preserve factory firmware and physical hardware. Do not claim completion until every connection has evidence or is explicitly unresolved.

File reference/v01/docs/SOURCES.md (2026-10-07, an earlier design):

# Component/document sources

Datasheet pin functions are separate evidence from the photographed PCB connections.

* U3: SGMICRO SGM8541/SGM8542/SGM8544 manufacturer datasheet, product page https://www.sg-micro.com/product/SGM8542 . The marking and SOIC-8 pin diagram were inspected. Exact top mark in IMG_2429 is SGM8542XS.
* U4: Microchip PIC16(L)F18855/75 data sheet DS40001802H. https://ww1.microchip.com/downloads/aemDocuments/documents/MCU08/ProductDocuments/DataSheets/PIC16%28L%29F18855-75-Data-Sheet-40001802H.pdf . The 28-pin diagram was inspected. The fitted part is the F, not LF, variant.
* U5: Mixic MX512H manufacturer datasheet, Rev. 1.2, previously identified in this project's analysis. A distributor's document link is available at https://jlcpcb.com/partdetail/Mixic-MX512H/C5119047 . The direct document download was not retrievable during this packaging pass. Pin mapping is retained from the earlier document identification; check its top-view diagram before hardware changes.
* Native KiCad format: https://dev-docs.kicad.org/en/file-formats/sexpr-schematic/ . Native format generation does not constitute an editor-load/ERC test.

No schematic of the exact 100-1339 R03 A board has been adopted. Older PetPorte/PIC16F886 firmware projects use different hardware and must not supply inferred nets or firmware for this board.

Searches for U1's PPEK and other short device marks did not establish sufficiently reliable, package-matching identities. Those fields remain unresolved.

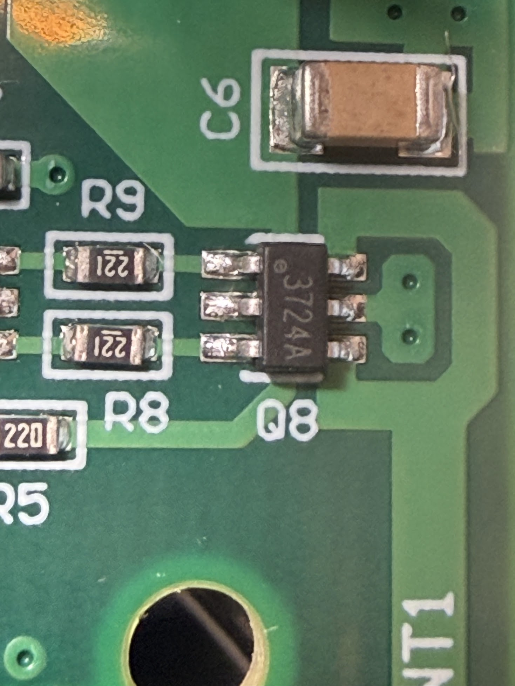
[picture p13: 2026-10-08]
photos/user_updates/Q8_3724A.png

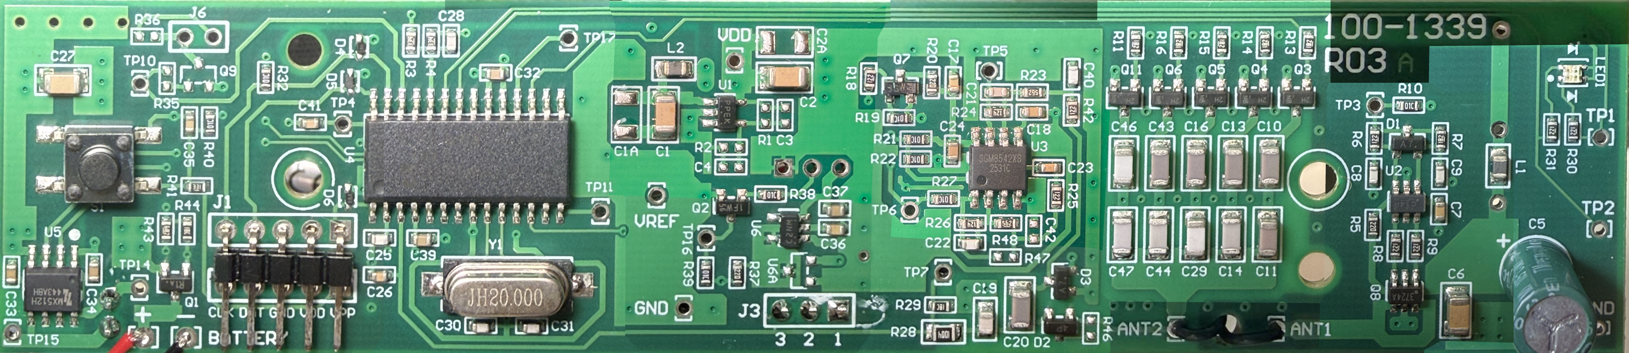
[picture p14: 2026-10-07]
photos/front_registered.jpg

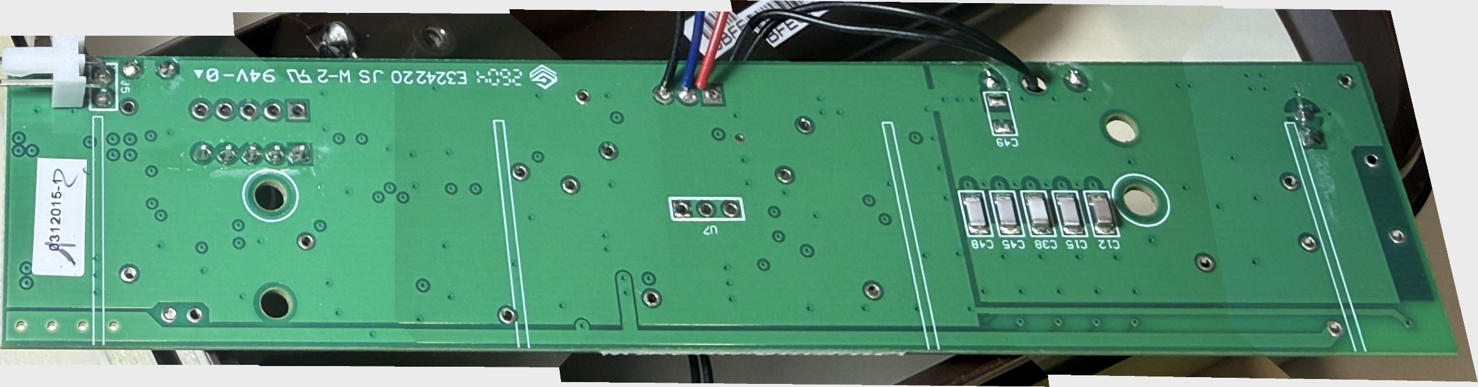
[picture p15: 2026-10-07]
photos/back_unrectified_preview.jpg

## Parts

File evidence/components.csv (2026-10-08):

original_ref | kicad_ref | observed_value | proposed_value | marking | population | source | hypothesis | unresolved_pin_count | library_symbol | footprint
R3 | R3 | 330k | 330k | 334 | populated | IMG_2436.jpg;IMG_2437.jpg;IMG_2438.jpg | See reconstruction notes; added connectivity inferred | 0 | Device:R | Resistor_SMD:R_0603_1608Metric
R4 | R4 | 330k | 330k | 334 | populated | IMG_2436.jpg;IMG_2437.jpg;IMG_2438.jpg | v0.7: lower photo pad/model pin2 visibly joins U4.24 / RB3. Withdraw hard ground tie; the remaining R3/R4/C28 sensing-network topology is inferred. | 0 | Device:R | Resistor_SMD:R_0603_1608Metric
R5 | R5 | 22 | 22 | 220 | populated | IMG_2431.jpg;IMG_2432.jpg | See reconstruction notes; added connectivity inferred | 0 | Device:R | Resistor_SMD:R_0603_1608Metric
R6 | R6 | 1.2k | 1.2k | 122 | populated | IMG_2431.jpg;IMG_2432.jpg | See reconstruction notes; added connectivity inferred | 0 | Device:R | Resistor_SMD:R_0603_1608Metric
R7 | R7 | 1.8k | 1.8k | 182 | populated | IMG_2431.jpg;IMG_2432.jpg | See reconstruction notes; added connectivity inferred | 0 | Device:R | Resistor_SMD:R_0603_1608Metric
R8 | R8 | 220 | 220 | 221 | populated | IMG_2431.jpg;IMG_2432.jpg | See reconstruction notes; added connectivity inferred | 0 | Device:R | Resistor_SMD:R_0603_1608Metric
R9 | R9 | 220 | 220 | 221 | populated | IMG_2431.jpg;IMG_2432.jpg | See reconstruction notes; added connectivity inferred | 0 | Device:R | Resistor_SMD:R_0603_1608Metric
R10 | R10 | 10k | 10k | 01C | populated | IMG_2431.jpg;IMG_2432.jpg | See reconstruction notes; added connectivity inferred | 0 | Device:R | Resistor_SMD:R_0603_1608Metric
R11 | R11 | 1.8k | 1.8k | 182 | populated | IMG_2433.jpg | See reconstruction notes; added connectivity inferred | 0 | Device:R | Resistor_SMD:R_0603_1608Metric
R13 | R13 | 1.8k | 1.8k | 182 | populated | IMG_2433.jpg | v0.8: user meter and visual trace place the free/model1 end on U4.17/RC6. Previous U4.18/RC7 assignment withdrawn; model2 still joins Q3. | 0 | Device:R | Resistor_SMD:R_0603_1608Metric
R14 | R14 | 1.8k | 1.8k | 182 | populated | IMG_2433.jpg | See reconstruction notes; added connectivity inferred | 0 | Device:R | Resistor_SMD:R_0603_1608Metric
R15 | R15 | 1.8k | 1.8k | 182 | populated | IMG_2433.jpg | See reconstruction notes; added connectivity inferred | 0 | Device:R | Resistor_SMD:R_0603_1608Metric
R16 | R16 | 1.8k | 1.8k | 182 | populated | IMG_2433.jpg | See reconstruction notes; added connectivity inferred | 0 | Device:R | Resistor_SMD:R_0603_1608Metric
R18 | R18 | 1.2k | 1.2k | 122 | populated | IMG_2429.jpg;IMG_2434.jpg | See reconstruction notes; added connectivity inferred | 0 | Device:R | Resistor_SMD:R_0603_1608Metric
R19 | R19 | 10k | 10k | 01C | populated | IMG_2429.jpg;IMG_2434.jpg | See reconstruction notes; added connectivity inferred | 0 | Device:R | Resistor_SMD:R_0603_1608Metric
R20 | R20 | 22 | 22 | 220 | populated | IMG_2429.jpg;IMG_2434.jpg | See reconstruction notes; added connectivity inferred | 0 | Device:R | Resistor_SMD:R_0603_1608Metric
R21 | R21 | 10k | 10k | 01C | populated | IMG_2429.jpg;IMG_2434.jpg | See reconstruction notes; added connectivity inferred | 0 | Device:R | Resistor_SMD:R_0603_1608Metric
R22 | R22 | 10k | 10k | 01C | populated | IMG_2429.jpg;IMG_2434.jpg | See reconstruction notes; added connectivity inferred | 0 | Device:R | Resistor_SMD:R_0603_1608Metric
R23 | R23 | 5.6k | 5.6k | 562 | populated | IMG_2429.jpg;IMG_2434.jpg | See reconstruction notes; added connectivity inferred | 0 | Device:R | Resistor_SMD:R_0603_1608Metric
R24 | R24 | 120k | 120k | 124 | populated | IMG_2429.jpg;IMG_2434.jpg | See reconstruction notes; added connectivity inferred | 0 | Device:R | Resistor_SMD:R_0603_1608Metric
R25 | R25 | 1.2k | 1.2k | 122 | populated | IMG_2429.jpg;IMG_2434.jpg | See reconstruction notes; added connectivity inferred | 0 | Device:R | Resistor_SMD:R_0603_1608Metric
R26 | R26 | 120k | 120k | 124 | populated | IMG_2429.jpg;IMG_2434.jpg | See reconstruction notes; added connectivity inferred | 0 | Device:R | Resistor_SMD:R_0603_1608Metric
R27 | R27 | 10k | 10k | 01C | populated | IMG_2429.jpg;IMG_2434.jpg | See reconstruction notes; added connectivity inferred | 0 | Device:R | Resistor_SMD:R_0603_1608Metric
R28 | R28 | 1M | 1M | 1004 | populated | IMG_2429.jpg;IMG_2434.jpg | v0.8: U4.3/RA1, TP7 and R29 share R28 model1 node per user continuity and local photo trace; earlier common RX-bias assignment withdrawn. | 0 | Device:R | Resistor_SMD:R_0603_1608Metric
R29 | R29 | 15k | 15k | 18C | populated | IMG_2429.jpg;IMG_2434.jpg | v0.8: nominal 15k from 18C. Model1 joins R28.1, TP7 and RA1 per user continuity/photo trace. Prior RX-bias tie withdrawn. | 0 | Device:R | Resistor_SMD:R_0603_1608Metric
R30 | R30 | 220 | 220 | 221 | populated | IMG_2431.jpg;IMG_2432.jpg | See reconstruction notes; added connectivity inferred | 0 | Device:R | Resistor_SMD:R_0603_1608Metric
R31 | R31 | 220 | 220 | 221 | populated | IMG_2431.jpg;IMG_2432.jpg | See reconstruction notes; added connectivity inferred | 0 | Device:R | Resistor_SMD:R_0603_1608Metric
R32 | R32 | 10k | 10k | 01C | populated | IMG_2436.jpg;IMG_2437.jpg;IMG_2438.jpg | v0.9: pin2 to ICSP CLK / D4 / PIC27; pin1 to user-GND V024. Earlier PIR-signal assumption withdrawn; moved into the PIC/ICSP block. | 0 | Device:R | Resistor_SMD:R_0603_1608Metric
R33 | R33 | 10k | 10k | 01C | populated | IMG_2435.jpg | See reconstruction notes; added connectivity inferred | 0 | Device:R | Resistor_SMD:R_0603_1608Metric
R37 | R37 | 22 | 22 | 220 | populated | IMG_2435.jpg | v0.9: pin1 joins R39.2 at V063; remote feed unknown. Pin2 to U6 VIN remains a local routing hypothesis. | 0 | Device:R | Resistor_SMD:R_0603_1608Metric
R38 | R38 | 10k | 10k | 01C | populated | IMG_2435.jpg | See reconstruction notes; added connectivity inferred | 0 | Device:R | Resistor_SMD:R_0603_1608Metric
R39 | R39 | 10k | 10k | 01C | populated | IMG_2435.jpg | v0.9: pin2 joins R37.1 at V063; earlier ground guess withdrawn. Pin1 retained on PIR_BASE candidate net. | 0 | Device:R | Resistor_SMD:R_0603_1608Metric
R40 | R40 | 10k | 10k | 01C | populated | IMG_2436.jpg;IMG_2437.jpg;IMG_2438.jpg | v0.7: upper photo pad/model pin1 visibly joins D5 cathode and U4.28 / ICSP data. Withdraw VDD tie. Opposite-end button hypothesis remains unverified. | 0 | Device:R | Resistor_SMD:R_0603_1608Metric
R41 | R41 | 330 | 330 | 331 | populated | IMG_2436.jpg;IMG_2437.jpg;IMG_2438.jpg | Observed marking 331 establishes nominal 330 ohm. Tolerance, power rating, package dimensions and external connections are not established by the code. | 0 | Device:R | Resistor_SMD:R_0603_1608Metric
R42 | R42 | 1.2k | 1.2k | 122 | populated | IMG_2429.jpg;IMG_2434.jpg | See reconstruction notes; added connectivity inferred | 0 | Device:R | Resistor_SMD:R_0603_1608Metric
R43 | R43 | 6.8k | 6.8k | 682 | populated | IMG_2436.jpg;IMG_2437.jpg;IMG_2438.jpg | See reconstruction notes; added connectivity inferred | 0 | Device:R | Resistor_SMD:R_0603_1608Metric
R44 | R44 | 15k | 15k | 18C | populated | IMG_2436.jpg;IMG_2437.jpg;IMG_2438.jpg | Re-read existing photo crop: 18C is legible. EIA-96 code18=150, multiplierC=100: nominal15kohm. No electrical value measurement. | 0 | Device:R | Resistor_SMD:R_0603_1608Metric
R48 | R48 | 5.6k | 5.6k | 562 | populated | IMG_2429.jpg;IMG_2434.jpg | See reconstruction notes; added connectivity inferred | 0 | Device:R | Resistor_SMD:R_0603_1608Metric
R1 | R1 | DNP | DNP |  | DNP | IMG_2430.jpg;IMG_2434.jpg;IMG_2438.jpg | See reconstruction notes; added connectivity inferred | 0 | Device:R | Resistor_SMD:R_0603_1608Metric
R2 | R2 | DNP | DNP |  | DNP | IMG_2430.jpg;IMG_2434.jpg;IMG_2438.jpg | See reconstruction notes; added connectivity inferred | 0 | Device:R | Resistor_SMD:R_0603_1608Metric
R35 | R35 | DNP | DNP |  | DNP | IMG_2430.jpg;IMG_2434.jpg;IMG_2438.jpg | See reconstruction notes; added connectivity inferred | 0 | Device:R | Resistor_SMD:R_0603_1608Metric
R36 | R36 | DNP | DNP |  | DNP | IMG_2430.jpg;IMG_2434.jpg;IMG_2438.jpg | See reconstruction notes; added connectivity inferred | 2 | Device:R | Resistor_SMD:R_0603_1608Metric
R46 | R46 | DNP | DNP |  | DNP | IMG_2430.jpg;IMG_2434.jpg;IMG_2438.jpg | See reconstruction notes; added connectivity inferred | 2 | Device:R | Resistor_SMD:R_0603_1608Metric
R47 | R47 | DNP | DNP |  | DNP | IMG_2430.jpg;IMG_2434.jpg;IMG_2438.jpg | See reconstruction notes; added connectivity inferred | 2 | Device:R | Resistor_SMD:R_0603_1608Metric
C1 | C1 | UNKNOWN | 1u? |  | populated | IMG_2430.jpg;IMG_2435.jpg | See reconstruction notes; added connectivity inferred | 0 | Device:C | Capacitor_SMD:C_1206_3216Metric
C2 | C2 | UNKNOWN | 4.7u? |  | populated | IMG_2430.jpg;IMG_2435.jpg | See reconstruction notes; added connectivity inferred | 0 | Device:C | Capacitor_SMD:C_1206_3216Metric
C3 | C3 | DNP | DNP |  | DNP | IMG_2430.jpg;IMG_2435.jpg | See reconstruction notes; added connectivity inferred | 0 | Device:C | Capacitor_SMD:C_0603_1608Metric
C4 | C4 | DNP | DNP |  | DNP | IMG_2430.jpg;IMG_2435.jpg | See reconstruction notes; added connectivity inferred | 0 | Device:C | Capacitor_SMD:C_0603_1608Metric
C5 | C5 | 470uF | 470uF / 16V | 470uF 16V | populated | IMG_2431.jpg;IMG_2432.jpg | See reconstruction notes; added connectivity inferred | 0 | Device:C_Polarized
C6 | C6 | UNKNOWN | UNKNOWN |  | populated | IMG_2431.jpg;IMG_2432.jpg | E-F=400kohm refutes direct output tie. F-P=10ohm and F-G=300kohm support supply-related upper pad. Exact path unresolved; no new 10ohm resistor invented. C6.1 open, C6.2 ground still inferred. | 1 | Device:C | Capacitor_SMD:C_1206_3216Metric
C7 | C7 | UNKNOWN | 100n? |  | populated | IMG_2431.jpg;IMG_2432.jpg | See reconstruction notes; added connectivity inferred | 0 | Device:C | Capacitor_SMD:C_0805_2012Metric
C8 | C8 | UNKNOWN | UNKNOWN |  | populated | IMG_2431.jpg;IMG_2432.jpg | See reconstruction notes; added connectivity inferred | 0 | Device:C | Capacitor_SMD:C_0805_2012Metric
C9 | C9 | UNKNOWN | UNKNOWN |  | populated | IMG_2431.jpg;IMG_2432.jpg | See reconstruction notes; added connectivity inferred | 0 | Device:C | Capacitor_SMD:C_0805_2012Metric
C10 | C10 | UNKNOWN | UNKNOWN |  | populated | IMG_2433.jpg;IMG_2442.jpg | See reconstruction notes; added connectivity inferred | 0 | Device:C | Capacitor_SMD:C_1206_3216Metric
C11 | C11 | UNKNOWN | UNKNOWN |  | populated | IMG_2433.jpg;IMG_2442.jpg | See reconstruction notes; added connectivity inferred | 0 | Device:C | Capacitor_SMD:C_1206_3216Metric
C12 | C12 | UNKNOWN | ? (rear) |  | populated | IMG_2433.jpg;IMG_2442.jpg | See reconstruction notes; added connectivity inferred | 0 | Device:C | Capacitor_SMD:C_1206_3216Metric
C13 | C13 | UNKNOWN | UNKNOWN |  | populated | IMG_2433.jpg;IMG_2442.jpg | See reconstruction notes; added connectivity inferred | 0 | Device:C | Capacitor_SMD:C_1206_3216Metric
C14 | C14 | UNKNOWN | UNKNOWN |  | populated | IMG_2433.jpg;IMG_2442.jpg | See reconstruction notes; added connectivity inferred | 0 | Device:C | Capacitor_SMD:C_1206_3216Metric
C15 | C15 | UNKNOWN | ? (rear) |  | populated | IMG_2433.jpg;IMG_2442.jpg | See reconstruction notes; added connectivity inferred | 0 | Device:C | Capacitor_SMD:C_1206_3216Metric
C16 | C16 | UNKNOWN | UNKNOWN |  | populated | IMG_2433.jpg;IMG_2442.jpg | See reconstruction notes; added connectivity inferred | 0 | Device:C | Capacitor_SMD:C_1206_3216Metric
C17 | C17 | UNKNOWN | 100n? |  | populated | IMG_2434.jpg | See reconstruction notes; added connectivity inferred | 0 | Device:C | Capacitor_SMD:C_0805_2012Metric
C18 | C18 | UNKNOWN | UNKNOWN |  | populated | IMG_2434.jpg | See reconstruction notes; added connectivity inferred | 0 | Device:C | Capacitor_SMD:C_0805_2012Metric
C19 | C19 | UNKNOWN | UNKNOWN |  | populated | IMG_2434.jpg | See reconstruction notes; added connectivity inferred | 0 | Device:C | Capacitor_SMD:C_0805_2012Metric
C20 | C20 | UNKNOWN | UNKNOWN |  | populated | IMG_2434.jpg | See reconstruction notes; added connectivity inferred | 0 | Device:C | Capacitor_SMD:C_1206_3216Metric
C21 | C21 | UNKNOWN | UNKNOWN |  | populated | IMG_2434.jpg | See reconstruction notes; added connectivity inferred | 0 | Device:C | Capacitor_SMD:C_0805_2012Metric
C22 | C22 | UNKNOWN | UNKNOWN |  | populated | IMG_2434.jpg | See reconstruction notes; added connectivity inferred | 0 | Device:C | Capacitor_SMD:C_0805_2012Metric
C23 | C23 | UNKNOWN | UNKNOWN |  | populated | IMG_2434.jpg | See reconstruction notes; added connectivity inferred | 0 | Device:C | Capacitor_SMD:C_0805_2012Metric
C24 | C24 | UNKNOWN | 100n? |  | populated | IMG_2434.jpg | See reconstruction notes; added connectivity inferred | 0 | Device:C | Capacitor_SMD:C_0805_2012Metric
C25 | C25 | UNKNOWN | ? |  | populated | IMG_2436.jpg;IMG_2437.jpg;IMG_2438.jpg | v0.7 photo review withdraws the generic 100n bypass assumption. Right photo pad (model pin1) visibly connects U4 pin2 / RA0. | 0 | Device:C | Capacitor_SMD:C_0805_2012Metric
C26 | C26 | UNKNOWN | ? |  | populated | IMG_2436.jpg;IMG_2437.jpg;IMG_2438.jpg | v0.7 photo review withdraws the generic 100n bypass assumption. The old VDD tie is not supported by visible copper. Signal-side destination remains unresolved. | 1 | Device:C | Capacitor_SMD:C_0805_2012Metric
C27 | C27 | UNKNOWN | UNKNOWN |  | populated | IMG_2436.jpg;IMG_2437.jpg;IMG_2438.jpg | v0.9: photo left pad/pin1 to motor VDD via V003/V004; right pad/pin2 to GND via V008/V009/V010. Capacitance still unknown. | 0 | Device:C | Capacitor_SMD:C_1206_3216Metric
C28 | C28 | UNKNOWN | 100n? |  | populated | IMG_2436.jpg;IMG_2437.jpg;IMG_2438.jpg | See reconstruction notes; added connectivity inferred | 0 | Device:C | Capacitor_SMD:C_0805_2012Metric
C29 | C29 | UNKNOWN | UNKNOWN |  | populated | IMG_2433.jpg;IMG_2442.jpg | See reconstruction notes; added connectivity inferred | 0 | Device:C | Capacitor_SMD:C_1206_3216Metric
C30 | C30 | UNKNOWN | 18p? |  | populated | IMG_2436.jpg;IMG_2437.jpg;IMG_2438.jpg | See reconstruction notes; added connectivity inferred | 0 | Device:C | Capacitor_SMD:C_0805_2012Metric
C31 | C31 | UNKNOWN | 18p? |  | populated | IMG_2436.jpg;IMG_2437.jpg;IMG_2438.jpg | See reconstruction notes; added connectivity inferred | 0 | Device:C | Capacitor_SMD:C_0805_2012Metric
C32 | C32 | UNKNOWN | 100n? |  | populated | IMG_2436.jpg;IMG_2437.jpg;IMG_2438.jpg | v0.7: visible local copper joins left pad/model pin1 to U4.20 VDD and right pad/model pin2 to U4.19 VSS. Withdraw old PIR-supply tie. 100n remains a value estimate. | 0 | Device:C | Capacitor_SMD:C_0805_2012Metric
C33 | C33 | UNKNOWN | 1u? |  | populated | IMG_2436.jpg;IMG_2437.jpg;IMG_2438.jpg | See reconstruction notes; added connectivity inferred | 0 | Device:C | Capacitor_SMD:C_0805_2012Metric
C34 | C34 | UNKNOWN | 100n? |  | populated | IMG_2436.jpg;IMG_2437.jpg;IMG_2438.jpg | See reconstruction notes; added connectivity inferred | 0 | Device:C | Capacitor_SMD:C_0805_2012Metric
C35 | C35 | UNKNOWN | 100n? |  | populated | IMG_2436.jpg;IMG_2437.jpg;IMG_2438.jpg | See reconstruction notes; added connectivity inferred | 0 | Device:C | Capacitor_SMD:C_0805_2012Metric
C36 | C36 | UNKNOWN | 1u? |  | populated | IMG_2430.jpg;IMG_2435.jpg | See reconstruction notes; added connectivity inferred | 0 | Device:C | Capacitor_SMD:C_0805_2012Metric
C37 | C37 | UNKNOWN | 1u? |  | populated | IMG_2430.jpg;IMG_2435.jpg | See reconstruction notes; added connectivity inferred | 0 | Device:C | Capacitor_SMD:C_0805_2012Metric
C38 | C38 | UNKNOWN | ? (rear) |  | populated | IMG_2433.jpg;IMG_2442.jpg | See reconstruction notes; added connectivity inferred | 0 | Device:C | Capacitor_SMD:C_1206_3216Metric
C39 | C39 | UNKNOWN | ? |  | populated | IMG_2436.jpg;IMG_2437.jpg;IMG_2438.jpg | v0.7 photo review withdraws the generic 100n bypass assumption. Left photo pad (model pin1) visibly connects U4 pin4 / RA2. | 0 | Device:C | Capacitor_SMD:C_0805_2012Metric
C40 | C40 | UNKNOWN | UNKNOWN |  | populated | IMG_2434.jpg | See reconstruction notes; added connectivity inferred | 0 | Device:C | Capacitor_SMD:C_0805_2012Metric
C41 | C41 | UNKNOWN | UNKNOWN |  | populated | IMG_2436.jpg;IMG_2437.jpg;IMG_2438.jpg | v0.8: C41.1-TP4-RB4/pin25 is user continuity plus local photo trace; C41.2 via V025 joins VSS-associated rear copper (photo inference). | 0 | Device:C | Capacitor_SMD:C_0805_2012Metric
C42 | C42 | DNP | DNP |  | DNP | IMG_2434.jpg | See reconstruction notes; added connectivity inferred | 2 | Device:C | Capacitor_SMD:C_0603_1608Metric
C43 | C43 | UNKNOWN | UNKNOWN |  | populated | IMG_2433.jpg;IMG_2442.jpg | See reconstruction notes; added connectivity inferred | 0 | Device:C | Capacitor_SMD:C_1206_3216Metric
C44 | C44 | UNKNOWN | UNKNOWN |  | populated | IMG_2433.jpg;IMG_2442.jpg | See reconstruction notes; added connectivity inferred | 0 | Device:C | Capacitor_SMD:C_1206_3216Metric
C45 | C45 | UNKNOWN | ? (rear) |  | populated | IMG_2433.jpg;IMG_2442.jpg | See reconstruction notes; added connectivity inferred | 0 | Device:C | Capacitor_SMD:C_1206_3216Metric
C46 | C46 | UNKNOWN | UNKNOWN |  | populated | IMG_2433.jpg;IMG_2442.jpg | See reconstruction notes; added connectivity inferred | 0 | Device:C | Capacitor_SMD:C_1206_3216Metric
C47 | C47 | UNKNOWN | UNKNOWN |  | populated | IMG_2433.jpg;IMG_2442.jpg | See reconstruction notes; added connectivity inferred | 0 | Device:C | Capacitor_SMD:C_1206_3216Metric
C48 | C48 | UNKNOWN | ? (rear) |  | populated | IMG_2433.jpg;IMG_2442.jpg | See reconstruction notes; added connectivity inferred | 0 | Device:C | Capacitor_SMD:C_1206_3216Metric
C49 | C49 | DNP | DNP |  | DNP | IMG_2433.jpg;IMG_2442.jpg | See reconstruction notes; added connectivity inferred | 2 | Device:C | Capacitor_SMD:C_1206_3216Metric
C1A | C101 | DNP | DNP |  | DNP | IMG_2430.jpg | See reconstruction notes; added connectivity inferred | 0 | Device:C | Capacitor_SMD:C_1206_3216Metric
C2A | C102 | DNP | DNP |  | DNP | IMG_2430.jpg | See reconstruction notes; added connectivity inferred | 0 | Device:C | Capacitor_SMD:C_1206_3216Metric
L1 | L1 | UNKNOWN | bead / L ? |  | populated | IMG_2432.jpg | See reconstruction notes; added connectivity inferred | 0 | Device:L | Inductor_SMD:L_0805_2012Metric
L2 | L2 | UNKNOWN | bead / L ? |  | populated | IMG_2430.jpg | See reconstruction notes; added connectivity inferred | 0 | Device:L | Inductor_SMD:L_0805_2012Metric
Y1 | Y1 | 20MHz | 20 MHz | JH20.000 | populated | IMG_2436.jpg | See reconstruction notes; added connectivity inferred | 0 | Device:Crystal | Crystal:Crystal_SMD_HC49-SD
U4 | U4 | PIC16F18855 | PIC16F18855 | PIC16F18855 /SO | populated | IMG_2424.jpg | See reconstruction notes; added connectivity inferred | 0 | MCU_Microchip_PIC16:PIC16F18855-xSO | Package_SO:SOIC-28W_7.5x17.9mm_P1.27mm
U5 | U5 | MX512H | MX512H | MX512H | populated | IMG_2424.jpg;IMG_2438.jpg | See reconstruction notes; added connectivity inferred | 0 | PetSafe_Datasheet:MX512H | Package_SO:SOIC-8_3.9x4.9mm_P1.27mm
U3 | U3 | SGM8542XS | SGM8542XS | SGM8542XS / 2531C | populated | IMG_2429.jpg | See reconstruction notes; added connectivity inferred | 0 | Amplifier_Operational:Opamp_Dual | Package_SO:SOIC-8_3.9x4.9mm_P1.27mm
U1 | U1 | UNKNOWN_5PIN | S-1200B45? | PPEK | populated | IMG_2430.jpg | H01: ABLIC S1200 Rev6 page23 maps PPE to S-1200B45-M5T1x and fourth character to lot. Strong identity candidate; board-wide connections remain inferred. | 0 | PetSafe_Datasheet:S-1200B45-M5T1 | Package_TO_SOT_SMD:SOT-23-5
U2 | U2 | UNKNOWN_6PIN | 74LVC2G14? | C14R? | populated | IMG_2431.jpg | H07: exact TI C14R marking and 6-pin DBV package match. Photo top row left to right = 3,2,1; bottom = 4,5,6. | 0 | 74xGxx:74LVC2G14 | Package_TO_SOT_SMD:SOT-23-6
U6 | U6 | UNKNOWN_5PIN | S-812C33AMC? / 3.3V | C2NM | populated | IMG_2435.jpg | H14v05: C2N product code matches ABLIC S-812C33AMC (Table 1); fourth character assembly month per MP005-A marking drawing. Pin1=VSS matches C=2.7ohm to G (shorted tips later 0.5ohm). Input/output routing inferred, 3.3V not measured. RT9818 supervisor hypothesis withdrawn. | 2 | PetSafe_Datasheet:S-812C33AMC | Package_TO_SOT_SMD:SOT-23-5
U6A | U106 | DNP | DNP |  | DNP | IMG_2435.jpg | See reconstruction notes; added connectivity inferred | 2 | Connector_Generic:Conn_01x03 | Package_TO_SOT_SMD:SOT-23
U7 | U7 | DNP | DNP |  | DNP | IMG_2441.jpg | See reconstruction notes; added connectivity inferred | 3 | Connector_Generic:Conn_01x03 | Connector_PinHeader_2.54mm:PinHeader_1x03_P2.54mm_Vertical
Q1 | Q1 | UNKNOWN | FMOS3401A? | R1A | populated | IMG_2438.jpg | R1A marking matches Formosa FMOS3401A datasheet p5; SOT-23 PMOS with G=1 (photo R), S=2 (photo L), D=3 (photo single S). Candidate identification, not manufacturer proof. Drain at battery+ and source at load support reverse-polarity protection; gate-control behavior not verified. Earlier MMBT3904 NPN hypothesis withdrawn. | 0 | Transistor_FET:Q_PMOS_GSD | Package_TO_SOT_SMD:SOT-23
Q2 | Q2 | UNKNOWN | BC847B? | 1FW / 56 | populated | IMG_2435.jpg | 1FW supports BC847B. Candidate B=R, E=L, C=S and PIR interface role remain inferred. J3.1/red supply is user-confirmed; J3.2/.3 functions still require cross-check. | 0 | Transistor_BJT:BC847 | Package_TO_SOT_SMD:SOT-23
Q3 | Q3 | UNKNOWN | MMBTA55? | 2H | populated | IMG_2433.jpg | H13: 2H marking suggests PNP MMBTA55/FMMTA55 family; PBSS5140T alternative. B=R E=L C=S assumed. | 0 | Transistor_BJT:Q_PNP_BEC | Package_TO_SOT_SMD:SOT-23
Q4 | Q4 | UNKNOWN | MMBTA55? | 2H | populated | IMG_2433.jpg | H13: 2H marking suggests PNP MMBTA55/FMMTA55 family; PBSS5140T alternative. B=R E=L C=S assumed. | 0 | Transistor_BJT:Q_PNP_BEC | Package_TO_SOT_SMD:SOT-23
Q5 | Q5 | UNKNOWN | MMBTA55? | 2H | populated | IMG_2433.jpg | H13: 2H marking suggests PNP MMBTA55/FMMTA55 family; PBSS5140T alternative. B=R E=L C=S assumed. | 0 | Transistor_BJT:Q_PNP_BEC | Package_TO_SOT_SMD:SOT-23
Q6 | Q6 | UNKNOWN | MMBTA55? | 2H | populated | IMG_2433.jpg | H13: 2H marking suggests PNP MMBTA55/FMMTA55 family; PBSS5140T alternative. B=R E=L C=S assumed. | 0 | Transistor_BJT:Q_PNP_BEC | Package_TO_SOT_SMD:SOT-23
Q7 | Q7 | UNKNOWN | BC857C? | 3GW / 54 | populated | IMG_2434.jpg | 3GW supports BC857C PNP. Photo and 11.2 kohm R18+R19 path support B=L, E=R/VDD, C=S/R20; terminal selection and switching role remain inferred. Control input R18.1 is now user-confirmed to PIC12/RC1 via V053-V070. | 0 | Transistor_BJT:BC857 | Package_TO_SOT_SMD:SOT-23
Q8 | Q8 | UNKNOWN | SIL3724A? | 3724A | populated | IMG_2431.jpg | 3724A supports the SIL3724A complementary MOSFET candidate; fitted maker unconfirmed. V113/V115 centre B2/native5 GND is resolved; outer-drain join retains D-E low-resistance evidence. V114 belongs to U2.T2 GND, not Q8. Q8 supply path and C6.1 remain incomplete; no current centre-ground conflict. | 0 | PetSafe_Datasheet:SIL3724A | Package_TO_SOT_SMD:SOT-23-6
Q9 | Q9 | DNP | DNP |  | DNP | IMG_2438.jpg | See reconstruction notes; added connectivity inferred | 1 | Connector_Generic:Conn_01x03 | Package_TO_SOT_SMD:SOT-23
Q11 | Q11 | UNKNOWN | MMBTA55? | 2H | populated | IMG_2433.jpg | H13: 2H marking suggests PNP MMBTA55/FMMTA55 family; PBSS5140T alternative. B=R E=L C=S assumed. | 0 | Transistor_BJT:Q_PNP_BEC | Package_TO_SOT_SMD:SOT-23
D1 | D1 | UNKNOWN | BAV99? | A7 | populated | IMG_2431.jpg | H08: A7 mark + SOT23 fits BAV99 series dual diode. Photo pad mapping is provisional. | 0 | Diode:BAV99 | Package_TO_SOT_SMD:SOT-23
D2 | D2 | UNKNOWN | 4P / unidentified | 4P | populated | IMG_2434.jpg | User clearly reads 4P. Withdraw BAV99 identity and all three guessed rail-clamp ties. Zetex FMMT2907R PNP is an exact code/package match but not established as the fitted part. Stock numbered placeholder retains L=1/R=2/S=3 as pad identifiers only; internal functions and routing unresolved. | 3 | Connector_Generic:Conn_01x03 | Package_TO_SOT_SMD:SOT-23
D3 | D3 | UNKNOWN | BAV99? | A7 | populated | IMG_2434.jpg | User clearly reads A7. Nexperia BAV99 manufacturer marking table and SOT-23 series-dual pin map support this candidate. Physical orientation and external rail-clamp routing remain inferred. | 0 | Diode:BAV99 | Package_TO_SOT_SMD:SOT-23
D4 | D4 | UNKNOWN | SD05? / TVS 5V | 5U | populated | IMG_2437.jpg | v0.8: cathode/model1 to ICSP clock retained. Anode/model2 via V030 joins VSS-associated rear copper (photo inference). 5U/SD05 remains a candidate identification. | 0 | Device:D_Zener | Diode_SMD:D_SOD-323
D5 | D5 | UNKNOWN | SD05? / TVS 5V | 5U | populated | IMG_2437.jpg | v0.8: cathode/model1 to ICSP data retained. Anode/model2 via V027 joins VSS-associated rear copper (photo inference). 5U/SD05 remains a candidate identification. | 0 | Device:D_Zener | Diode_SMD:D_SOD-323
D6 | D6 | UNKNOWN | MMSZ5228BS? / 3.9V | G3 | populated | IMG_2437.jpg | H17v05: New sharp user marking supersedes T4/1N4148WS guess. Diodes table maps G3 to MMSZ5228BS 3.9V SOD323; Nexperia PZU2.4B 2.4V SOD323F also uses G3. Selected first as provisional; voltage not confirmed. Cathode band visible; photo-pad numbering and external routes still unresolved. | 2 | Device:D_Zener | Diode_SMD:D_SOD-323
S1 | S1 | pushbutton | pushbutton |  | populated | IMG_2438.jpg | See reconstruction notes; added connectivity inferred | 0 | Switch:SW_Push_Dual
J1 | J1 | ICSP header | ICSP |  | populated | IMG_2437.jpg | See reconstruction notes; added connectivity inferred | 0 | Connector_Generic:Conn_01x05 | Connector_PinHeader_2.54mm:PinHeader_1x05_P2.54mm_Horizontal
J3 | J3 | PIR daughterboard | PIR BOARD |  | populated | IMG_2435.jpg;IMG_2441.jpg | See reconstruction notes; added connectivity inferred | 0 | Connector_Generic:Conn_01x03 | Connector_PinHeader_2.54mm:PinHeader_1x03_P2.54mm_Vertical
J5 | J5 | motor connector | MOTOR |  | populated | IMG_2439.jpg | See reconstruction notes; added connectivity inferred | 0 | Connector_Generic:Conn_01x02 | Connector_JST:JST_XH_B2B-XH-A_1x02_P2.50mm_Vertical
J6 | J6 | DNP | DNP |  | DNP | IMG_2438.jpg | See reconstruction notes; added connectivity inferred | 2 | Connector_Generic:Conn_01x02 | Connector_PinHeader_2.54mm:PinHeader_1x02_P2.54mm_Vertical
LED1 | LED1 | UNKNOWN_4PAD | 2-colour LED? |  | populated | IMG_2432.jpg | See reconstruction notes; added connectivity inferred | 0 | Device:LED_Dual_AAKK
TP1 | TP1 | test point | test point |  | populated | IMG_2431.jpg;IMG_2432.jpg | v0.8: user confirms RB2/pin23. IMG_2432 shows R30 free-end track; previous LED-common assignment withdrawn. | 0 | Connector:TestPoint | TestPoint:TestPoint_THTPad_D2.0mm_Drill1.0mm
TP2 | TP2 | test point | test point |  | populated | IMG_2431.jpg;IMG_2432.jpg | v0.8: user confirms RB1/pin22. IMG_2432 shows R31 free-end track; previous RF-supply assignment withdrawn. | 0 | Connector:TestPoint | TestPoint:TestPoint_THTPad_D2.0mm_Drill1.0mm
TP3 | TP3 | test point | test point |  | populated | IMG_2431.jpg;IMG_2432.jpg | See reconstruction notes; added connectivity inferred | 0 | Connector:TestPoint | TestPoint:TestPoint_THTPad_D2.0mm_Drill1.0mm
TP4 | TP4 | test point | test point |  | populated | IMG_2436.jpg;IMG_2437.jpg;IMG_2438.jpg | v0.8: user confirms RB4/pin25. Local C41.1 connection retained. | 0 | Connector:TestPoint | TestPoint:TestPoint_THTPad_D2.0mm_Drill1.0mm
TP5 | TP5 | test point | test point |  | populated | IMG_2434.jpg | See reconstruction notes; added connectivity inferred | 0 | Connector:TestPoint | TestPoint:TestPoint_THTPad_D2.0mm_Drill1.0mm
TP6 | TP6 | test point | test point |  | populated | IMG_2434.jpg | See reconstruction notes; added connectivity inferred | 0 | Connector:TestPoint | TestPoint:TestPoint_THTPad_D2.0mm_Drill1.0mm
TP7 | TP7 | test point | test point |  | populated | IMG_2434.jpg | v0.8: user RP7 wording interpreted as photographed TP7. Joins RA1/R28/R29; old detector-net hypothesis withdrawn. | 0 | Connector:TestPoint | TestPoint:TestPoint_THTPad_D2.0mm_Drill1.0mm
TP9 | TP9 | test point | test point |  | populated | IMG_2436.jpg;IMG_2437.jpg;IMG_2438.jpg | See reconstruction notes; added connectivity inferred | 1 | Connector:TestPoint | TestPoint:TestPoint_THTPad_D2.0mm_Drill1.0mm
TP10 | TP10 | test point | test point |  | populated | IMG_2436.jpg;IMG_2437.jpg;IMG_2438.jpg | v0.8: user meter/visual tracing corroborates U4.26/RB5 to TP10. | 0 | Connector:TestPoint | TestPoint:TestPoint_THTPad_D2.0mm_Drill1.0mm
TP11 | TP11 | test point | test point |  | populated | IMG_2436.jpg;IMG_2437.jpg;IMG_2438.jpg | See reconstruction notes; added connectivity inferred | 0 | Connector:TestPoint | TestPoint:TestPoint_THTPad_D2.0mm_Drill1.0mm
TP14 | TP14 | test point | test point |  | populated | IMG_2436.jpg;IMG_2437.jpg;IMG_2438.jpg | See reconstruction notes; added connectivity inferred | 0 | Connector:TestPoint | TestPoint:TestPoint_THTPad_D2.0mm_Drill1.0mm
TP15 | TP15 | test point | test point |  | populated | IMG_2436.jpg;IMG_2437.jpg;IMG_2438.jpg | See reconstruction notes; added connectivity inferred | 0 | Connector:TestPoint | TestPoint:TestPoint_THTPad_D2.0mm_Drill1.0mm
TP16 | TP16 | test point | test point |  | populated | IMG_2435.jpg | See reconstruction notes; added connectivity inferred | 0 | Connector:TestPoint | TestPoint:TestPoint_THTPad_D2.0mm_Drill1.0mm
TP17 | TP17 | test point | test point |  | populated | IMG_2436.jpg;IMG_2437.jpg;IMG_2438.jpg | v0.8: local U4.18/RC7 connection retained; earlier onward R13 guess withdrawn after user reports R13 on RC6. | 0 | Connector:TestPoint | TestPoint:TestPoint_THTPad_D2.0mm_Drill1.0mm
GND | TP101 | GND | GND pad |  | populated | IMG_2430.jpg;IMG_2433.jpg;IMG_2435.jpg;IMG_2438.jpg | See reconstruction notes; added connectivity inferred | 0 | Connector:TestPoint | TestPoint:TestPoint_THTPad_D2.0mm_Drill1.0mm
GND_RF | TP102 | GND (RF end) | GND pad |  | populated | IMG_2432.jpg | See reconstruction notes; added connectivity inferred | 0 | Connector:TestPoint | TestPoint:TestPoint_THTPad_D2.0mm_Drill1.0mm
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

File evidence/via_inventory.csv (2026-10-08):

id | active | rear_x | rear_y | front_x | front_y | rear_appearance | front_match | review_status | user_claims | endpoints | net | modeled_nets | component_crosscheck | conflict
V001 | True | 66 | 1706 | 66 | 1706 | REAR_CLEARANCE | PROJECTED: inspect original front photo; may be under a component | ASSIGNED | Same net as MX512H/U5 pin4 VDD | U5.4 | VSYS | VSYS | MX512H motor VDD, distinct from logic VCC pin1.
V002 | True | 66 | 1828 | 66 | 1828 | REAR_CLEARANCE | PROJECTED: inspect original front photo; may be under a component | ASSIGNED | Same net as MX512H/U5 pin4 VDD | U5.4 | VSYS | VSYS | MX512H motor VDD, distinct from logic VCC pin1.
V003 | True | 178 | 506 | 178 | 506 | REAR_CLEARANCE | PROJECTED: inspect original front photo; may be under a component | ASSIGNED | Same net as MX512H/U5 pin4 VDD | C27.1 | VSYS | VSYS | C27 left photo pad on user motor-supply island.
V004 | True | 178 | 630 | 178 | 630 | REAR_CLEARANCE | PROJECTED: inspect original front photo; may be under a component | ASSIGNED | Same net as MX512H/U5 pin4 VDD | C27.1 | VSYS | VSYS | C27 left photo pad on user motor-supply island.
V005 | True | 186 | 1708 | 186 | 1708 | REAR_CLEARANCE | PROJECTED: inspect original front photo; may be under a component | ASSIGNED | Same net as MX512H/U5 pin4 VDD |  | VSYS
V006 | True | 208 | 2096 | 208 | 2096 | MAIN_REAR_COPPER | PROJECTED: inspect original front photo; may be under a component | ASSIGNED | C33; earlier user GND report retained | C33.2 | GND | GND | User adds C33 to earlier GND report; pad2 selected from photo/model.
V007 | True | 682 | 1794 | 682 | 1794 | REAR_CLEARANCE | PROJECTED: inspect original front photo; may be under a component | ASSIGNED | C34; earlier user GND report retained | C34.2 | GND | GND | User adds C34 to earlier GND report; pad2 selected from photo/model.
V008 | True | 750 | 430 | 750 | 430 | MAIN_REAR_COPPER | PROJECTED: inspect original front photo; may be under a component | ASSIGNED | GND | C27.2 | GND | GND | C27 right photo pad on user GND island.
V009 | True | 750 | 580 | 750 | 580 | MAIN_REAR_COPPER | PROJECTED: inspect original front photo; may be under a component | ASSIGNED | GND | C27.2 | GND | GND | C27 right photo pad on user GND island.
V010 | True | 750 | 714 | 750 | 714 | MAIN_REAR_COPPER | PROJECTED: inspect original front photo; may be under a component | ASSIGNED | GND | C27.2 | GND | GND | C27 right photo pad on user GND island.
V011 | True | 892 | 1826 | 892 | 1826 | REAR_CLEARANCE | PROJECTED: inspect original front photo; may be under a component | ASSIGNED | v0.9.9: User corrects raw battery+ versus post-Q1 rail. BATP -> Q1.S (single physical pad/native3, candidate drain); Q1.L/native2 (candidate source) -> U5.4/V011-V014. These are distinct copper nets, connected through Q1. IMG_2438 also supports TP14 on battery+; V015/R43.2-TP14 user confirmation retained. Q1.R/native1 is candidate gate at R44.2. Photo S means SINGLE, not MOSFET source. | Q1.L | VSYS | VSYS | User explicitly confirms same rail as MX512H pin4. Q1.L reaches motor VSYS, distinct from regulated VDD/TP103. R43.2 remains excluded.
V012 | True | 894 | 1672 | 894 | 1672 | REAR_CLEARANCE | PROJECTED: inspect original front photo; may be under a component | ASSIGNED | v0.9.9: User corrects raw battery+ versus post-Q1 rail. BATP -> Q1.S (single physical pad/native3, candidate drain); Q1.L/native2 (candidate source) -> U5.4/V011-V014. These are distinct copper nets, connected through Q1. IMG_2438 also supports TP14 on battery+; V015/R43.2-TP14 user confirmation retained. Q1.R/native1 is candidate gate at R44.2. Photo S means SINGLE, not MOSFET source. | Q1.L | VSYS | VSYS | User explicitly confirms same rail as MX512H pin4. Q1.L reaches motor VSYS, distinct from regulated VDD/TP103. R43.2 remains excluded.
V013 | True | 1042 | 1678 | 1042 | 1678 | REAR_CLEARANCE | PROJECTED: inspect original front photo; may be under a component | ASSIGNED | v0.9.9: User corrects raw battery+ versus post-Q1 rail. BATP -> Q1.S (single physical pad/native3, candidate drain); Q1.L/native2 (candidate source) -> U5.4/V011-V014. These are distinct copper nets, connected through Q1. IMG_2438 also supports TP14 on battery+; V015/R43.2-TP14 user confirmation retained. Q1.R/native1 is candidate gate at R44.2. Photo S means SINGLE, not MOSFET source. | Q1.L | VSYS | VSYS | User explicitly confirms same rail as MX512H pin4. Q1.L reaches motor VSYS, distinct from regulated VDD/TP103. R43.2 remains excluded.
V014 | True | 1046 | 1826 | 1046 | 1826 | REAR_CLEARANCE | PROJECTED: inspect original front photo; may be under a component | ASSIGNED | v0.9.9: User corrects raw battery+ versus post-Q1 rail. BATP -> Q1.S (single physical pad/native3, candidate drain); Q1.L/native2 (candidate source) -> U5.4/V011-V014. These are distinct copper nets, connected through Q1. IMG_2438 also supports TP14 on battery+; V015/R43.2-TP14 user confirmation retained. Q1.R/native1 is candidate gate at R44.2. Photo S means SINGLE, not MOSFET source. | Q1.L | VSYS | VSYS | User explicitly confirms same rail as MX512H pin4. Q1.L reaches motor VSYS, distinct from regulated VDD/TP103. R43.2 remains excluded.
V015 | True | 1218 | 1862 | 1218 | 1862 | REAR_CLEARANCE | PROJECTED: inspect original front photo; may be under a component | ASSIGNED | v0.9.8: User confirms V015-TP14. Earlier V015-R43.2 lower-pad association retained. R43.2 joins TP14 on H_BAT_DETECT, whose existing Q1.S branch and functional name remain photo/circuit hypotheses. Q1.L-R43.2 remains explicitly rejected. No numeric resistance supplied. | R43.2;TP14.1 | BATTERY+ | BATTERY+ | User confirms V015-TP14 and R43.2. IMG_2438 places TP14 on battery-positive copper to Q1 single pad3. Raw battery stays separate from post-Q1 motor VDD; the former battery-detect net name is withdrawn.
V016 | True | 1224 | 1224 | 1224 | 1224 | REAR_CLEARANCE | PROJECTED: inspect original front photo; may be under a component | ASSIGNED | U5 pin2 / INA, connected to V022 / PIC15 RC4 | U5.2;U4.15 | MOTOR_INA | MOTOR_INA | User confirms V016-V022 joins U5 INA pin2 to PIC15 RC4.
V017 | True | 1232 | 1520 | 1232 | 1520 | REAR_CLEARANCE | PROJECTED: inspect original front photo; may be under a component | ASSIGNED | v0.9.8: User confirms V017-TP4. Prior V017-R42.1/R44.1 local junction now joins TP4 and PIC25/RB4. R42.1 explicitly user-named; R44 pad1 and C41 branch retain earlier photo selection. No numeric resistance supplied; circuit operating role remains inferred. | R42.1;R44.1;TP4.1;U4.25 | PIC_TP4_C41 | PIC_TP4_C41 | User confirms V017-TP4, previously mapped to PIC25/RB4. R42.1 explicitly named; R44 free pad1 photo-selected. Old ANT2 hypothesis remains withdrawn.
V018 | True | 1290 | 840 | 1290 | 840 | MAIN_REAR_COPPER | PROJECTED: inspect original front photo; may be under a component | ASSIGNED | C35; earlier user GND report retained | C35.2 | GND | GND | User adds C35 to earlier GND report; pad2 selected from photo/model.
V019 | True | 1302 | 1112 | 1302 | 1112 | REAR_CLEARANCE | PROJECTED: inspect original front photo; may be under a component | ASSIGNED | U5 pin3 / INB, connected to V023 / PIC16 RC5 | U5.3;U4.16 | MOTOR_INB | MOTOR_INB | User confirms V019-V023 joins U5 INB pin3 to PIC16 RC5.
V020 | True | 1640 | 826 | 1640 | 826 | REAR_CLEARANCE | PROJECTED: inspect original front photo; may be under a component | ASSIGNED | R40 | R40.1 | ICSP_DAT | ICSP_DAT | User identifies R40; photo selects upper/free pad1 on the existing ICSP DAT node.
V021 | True | 1650 | 614 | 1650 | 614 | MAIN_REAR_COPPER | PROJECTED: inspect original front photo; may be under a component | ASSIGNED | GND | Q9.R | GND | GND | Q9 DNP lower-right pad; stock pin2.
V022 | True | 1956 | 1032 | 1956 | 1032 | REAR_CLEARANCE | PROJECTED: inspect original front photo; may be under a component | ASSIGNED | Connected to V016 / U5 pin2; earlier PIC15 RC4 report retained | U5.2;U4.15 | MOTOR_INA | MOTOR_INA | User confirms V016-V022 joins U5 INA pin2 to PIC15 RC4.
V023 | True | 1958 | 876 | 1958 | 876 | REAR_CLEARANCE | PROJECTED: inspect original front photo; may be under a component | ASSIGNED | Connected to V019 / U5 pin3; earlier PIC16 RC5 report retained | U5.3;U4.16 | MOTOR_INB | MOTOR_INB | User confirms V019-V023 joins U5 INB pin3 to PIC16 RC5.
V024 | True | 1970 | 398 | 1970 | 398 | MAIN_REAR_COPPER | PROJECTED: inspect original front photo; may be under a component | ASSIGNED | GND | R32.1 | GND | GND | R32 upper photo pad. Old PIR assignment withdrawn.
V025 | True | 2134 | 890 | 2125 | 900 | MAIN_REAR_COPPER | MANUALLY MATCHED | ASSIGNED | GND | C41.2 | GND | GND
V026 | True | 2646 | 1030 | 2658 | 1055 | REAR_CLEARANCE | MANUALLY MATCHED | ASSIGNED | V026 reaches the VREF test point (native TP104). Earlier PIC21/RB0 association retained. | U4.21;VREF.1 | VREF | VREF | User V026-VREF report with prior V026-PIC21/RB0 mapping. VREF is native TP104; voltage/function not established.
V027 | True | 2688 | 522 | 2685 | 542 | MAIN_REAR_COPPER | MANUALLY MATCHED | PHOTO_LOCAL |  | D5.2 | GND | GND
V028 | True | 2732 | 2278 | 2738 | 2262 | MAIN_REAR_COPPER | MANUALLY MATCHED | PHOTO_LOCAL |  | C26.2 | GND | GND
V029 | True | 2736 | 1932 | 2736 | 1932 | MAIN_REAR_COPPER | PROJECTED: inspect original front photo; may be under a component | ASSIGNED | C25/C26; earlier user GND report retained | C25.2;C26.2 | GND | GND | User adds both capacitors to earlier GND report; return pads selected from photos/model. C26.1 remains unresolved.
V030 | True | 2760 | 262 | 2752 | 292 | MAIN_REAR_COPPER | MANUALLY MATCHED | PHOTO_LOCAL |  | D4.2 | GND | GND
V031 | True | 2852 | 1848 | 2852 | 1848 | REAR_CLEARANCE | PROJECTED: inspect original front photo; may be under a component | ASSIGNED | PIC RA0 / U4.2 and C25 | U4.2;C25.1 | PIC_RA0_FILTER | PIC_RA0_FILTER | User RA0/C25 association corroborates existing local signal node.
V032 | True | 2906 | 1342 | 2906 | 1342 | MAIN_REAR_COPPER | PROJECTED: inspect original front photo; may be under a component | ASSIGNED | GND |  | GND
V033 | False | 2910 | 1612 | 2910 | 1612 | MAIN_REAR_COPPER | PROJECTED: inspect original front photo; may be under a component | REJECTED_NOT_VIA | Not a via; recognition artifact |  |  |  | User rejects this detection as not a via. Stable ID retained; excluded from active markers.
V034 | True | 3028 | 80 | 3028 | 80 | OTHER_REAR_REGION | PROJECTED: inspect original front photo; may be under a component | ASSIGNED | Clearly VDD, R3; earlier MX512H pin4 common-supply report retained | R3.1 | VSYS | VSYS | User VDD/R3, previously explicitly the same net as V001 and MX512H pin4. This is motor supply VSYS, not regulated VDD.
V035 | True | 3056 | 1848 | 3056 | 1848 | REAR_CLEARANCE | PROJECTED: inspect original front photo; may be under a component | ASSIGNED | v0.9.9: User checked V035-VREF TP. Prior photo association V035-PIC4/RA2-C39.1 retained; joins the already confirmed RB0/V026/R21.2/V071 VREF node. No voltage or numerical resistance supplied. Other modeled bias branches retain earlier inferred status. | U4.4;C39.1;VREF.1 | VREF | VREF | User confirms V035-VREF TP; earlier local PIC4/RA2-C39.1 photo route retained. Same VREF node as V026/RB0 and V071/R21.2.
V036 | True | 3166 | 1296 | 3166 | 1296 | REAR_CLEARANCE | PROJECTED: inspect original front photo; may be under a component | ASSIGNED | User reports working via pair V036-V108: PIC pin5 to R14.1; no numerical resistance supplied. | U4.5;R14.1 | H_TUNE_2 | H_TUNE_2 | User working via pair V036-V108; PIC control to resistor confirmed. No numerical ohms supplied.
V037 | True | 3264 | 1384 | 3264 | 1384 | REAR_CLEARANCE | PROJECTED: inspect original front photo; may be under a component | ASSIGNED | User reports working via pair V037-V102: PIC pin6 to R15.1; no numerical resistance supplied. | U4.6;R15.1 | H_TUNE_3 | H_TUNE_3 | User working via pair V037-V102; PIC control to resistor confirmed. No numerical ohms supplied.
V038 | True | 3274 | 1750 | 3288 | 1760 | MAIN_REAR_COPPER | MANUALLY MATCHED | PHOTO_LOCAL |  | C39.2 | GND | GND
V039 | True | 3370 | 1296 | 3370 | 1296 | REAR_CLEARANCE | PROJECTED: inspect original front photo; may be under a component | ASSIGNED | User reports working via pair V039-V097: PIC pin7 to R16.1; no numerical resistance supplied. | U4.7;R16.1 | H_TUNE_4 | H_TUNE_4 | User working via pair V039-V097; PIC control to resistor confirmed. No numerical ohms supplied.
V040 | True | 3428 | 202 | 3428 | 202 | MAIN_REAR_COPPER | PROJECTED: inspect original front photo; may be under a component | ASSIGNED | C28; earlier user GND report retained | C28.2 | GND | GND | User adds C28 to earlier GND report; return pad selected from photo/model.
V041 | True | 3476 | 1694 | 3485 | 1698 | MAIN_REAR_COPPER | MANUALLY MATCHED | ASSIGNED | GND | U4.8 | GND | GND
V042 | True | 3480 | 506 | 3492 | 540 | REAR_CLEARANCE | MANUALLY MATCHED | ASSIGNED | User confirms V042-board VDD TP/TP103. Retain PIC20/C32.1 local photo route on H_VDD. | U4.20;C32.1;VDD.1 | VDD | VDD | User confirms V042-board VDD TP, matching prior PIC20/C32.1 photo mapping. Regulated VDD, not motor VDD or raw battery.
V043 | True | 3480 | 1396 | 3480 | 1396 | MAIN_REAR_COPPER | PROJECTED: inspect original front photo; may be under a component | ASSIGNED | GND |  | GND
V044 | True | 3694 | 852 | 3694 | 852 | MAIN_REAR_COPPER | PROJECTED: inspect original front photo; may be under a component | ASSIGNED | GND |  | GND
V045 | True | 3700 | 404 | 3715 | 432 | MAIN_REAR_COPPER | MANUALLY MATCHED | ASSIGNED | GND | U4.19;C32.2 | GND | GND
V046 | True | 3728 | 2342 | 3728 | 2342 | MAIN_REAR_COPPER | PROJECTED: inspect original front photo; may be under a component | ASSIGNED | GND |  | GND
V047 | True | 3790 | 1378 | 3790 | 1378 | REAR_CLEARANCE | PROJECTED: inspect original front photo; may be under a component | ASSIGNED | User reports working via pair V047-V091: PIC pin11 to R11.1; no numerical resistance supplied. | U4.11;R11.1 | H_TUNE_5 | H_TUNE_5 | User working via pair V047-V091; PIC control to resistor confirmed. No numerical ohms supplied.
V048 | True | 3790 | 1712 | 3790 | 1712 | MAIN_REAR_COPPER | PROJECTED: inspect original front photo; may be under a component | ASSIGNED | GND |  | GND
V049 | True | 4000 | 1378 | 4000 | 1378 | REAR_CLEARANCE | PROJECTED: inspect original front photo; may be under a component | ASSIGNED | V049 reaches TP03, interpreted as board TP3. Earlier user V049-PIC13/RC2 association retained. | U4.13;TP3.1 | RF_MONITOR_PAD | RF_MONITOR_PAD | User confirms V049 reaches TP03 (board TP3), with earlier PIC13/RC2 association. Existing TP3-R10.1 local branch remains photo-derived; no new resistance supplied.
V050 | False | 4002 | 1710 | 4002 | 1710 | MAIN_REAR_COPPER | PROJECTED: inspect original front photo; may be under a component | REJECTED_NOT_VIA | Not a via; wrong recognition |  |  |  | User rejects this detection as not a via. Stable ID retained; excluded from active markers.
V051 | True | 4264 | 700 | 4264 | 700 | MAIN_REAR_COPPER | PROJECTED: inspect original front photo; may be under a component | ASSIGNED | GND |  | GND
V052 | True | 4440 | 1114 | 4440 | 1114 | MAIN_REAR_COPPER | PROJECTED: inspect original front photo; may be under a component | ASSIGNED | GND |  | GND
V053 | True | 4568 | 1694 | 4592 | 1698 | REAR_CLEARANCE | MANUALLY MATCHED | ASSIGNED | User confirms V053-V070 (PIC12/RC1 to R18); V053 explicitly NOT connected to VREF. No numeric reading supplied. | U4.12;R18.1 | H_RX_ENABLE_CTL | H_RX_ENABLE_CTL | User confirms V053-V070 and excludes V053-VREF. PIC12/RC1 reaches R18 input; Q7 local operating role remains inferred. No numeric ohms supplied.
V054 | True | 4620 | 338 | 4620 | 338 | MAIN_REAR_COPPER | PROJECTED: inspect original front photo; may be under a component | ASSIGNED | GND |  | GND
V055 | True | 4630 | 2274 | 4630 | 2274 | MAIN_REAR_COPPER | PROJECTED: inspect original front photo; may be under a component | ASSIGNED | GND |  | GND
V056 | True | 4768 | 168 | 4768 | 168 | OTHER_REAR_REGION | PROJECTED: inspect original front photo; may be under a component | ASSIGNED | Same net as MX512H/U5 pin4 VDD |  | VSYS
V057 | True | 5056 | 956 | 5056 | 956 | MAIN_REAR_COPPER | PROJECTED: inspect original front photo; may be under a component | ASSIGNED | GND | R2.1;C4.1 | GND | GND | DNP option free pads in the front ground copper.
V058 | True | 5060 | 840 | 5060 | 840 | MAIN_REAR_COPPER | PROJECTED: inspect original front photo; may be under a component | ASSIGNED | GND | R2.1;C4.1 | GND | GND | DNP option free pads in the front ground copper.
V059 | True | 5168 | 584 | 5168 | 584 | OTHER_REAR_REGION | PROJECTED: inspect original front photo; may be under a component | ASSIGNED | L2; earlier MX512H pin4 common-supply report retained | L2.1 | VSYS | VSYS | User adds L2 to the earlier common motor-supply report; source/right pad1 selected from photo/model.
V060 | True | 5168 | 1424 | 5168 | 1424 | MAIN_REAR_COPPER | PROJECTED: inspect original front photo; may be under a component | ASSIGNED | Q2; earlier user GND report retained | Q2.L | GND | GND | User adds Q2 to earlier GND report; local ground-side pad selected from photo/model.
V061 | True | 5170 | 454 | 5170 | 454 | MAIN_REAR_COPPER | PROJECTED: inspect original front photo; may be under a component | ASSIGNED | L2; earlier MX512H pin4 common-supply report retained | L2.1 | VSYS | VSYS | User adds L2 to the earlier common motor-supply report; source/right pad1 selected from photo/model.
V062 | True | 5238 | 2274 | 5238 | 2274 | MAIN_REAR_COPPER | PROJECTED: inspect original front photo; may be under a component | ASSIGNED | GND |  | GND
V063 | True | 5306 | 2070 | 5306 | 2070 | REAR_CLEARANCE | PROJECTED: inspect original front photo; may be under a component | ASSIGNED | v0.9.6: User confirms V064-V063. R37.1/R39.2 feed junction is regulated board VDD, not motor VDD. | R37.1;R39.2 | VDD | VDD | User V064-V063 confirms R37/R39 feed on regulated board VDD. Motor supply remains separate.
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

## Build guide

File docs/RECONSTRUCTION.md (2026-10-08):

# Current circuit interpretation

This document describes v0.9.9. [The completion checklist](FINISHING_CHECKLIST.html) is the authoritative list of known unresolved work. [Earlier reasoning](history/README.md) is preserved as history, including rejected guesses.

## What is established

All 150 catalog entries are represented on one A2 sheet. Twenty stock and four authorized custom symbol definitions provide the selected pin maps. All 352 physical pad identifiers have library-number crosswalks. The native netlist matches 83 modeled net partitions; this is a file-consistency result, not proof of every board connection.

The user supplied multimeter continuity, resistance readings, clear component markings and dimensions. Visible traces and approximate front/rear photo registration provide additional evidence. A via touching a surface copper region can support a local association; its appearance cannot establish a buried net or prove a four-layer stack.

## Power path

BATTERY+ reaches Q1's single physical pad (native pin 3). Q1.L (native pin 2) supplies VSYS, which reaches MX512H pin 4 and the supply sides of L1/L2. The user confirmed these associations and that raw battery and VSYS are distinct. TP14/R43.2 remain on the raw side; the previous Q1.L-R43.2 join was explicitly rejected.

The R1A marking matches the Formosa FMOS3401A PMOS candidate, with gate 1/source 2/drain 3. Reverse-polarity protection is a supported interpretation; exact maker and gate operation remain unverified. Photo label `S` means **single pad**, not source.

Board VDD/TP103 is the separate logic rail and feeds MX512H pin 1/VCC. VREF/TP104 is separate again: user reports connect PIC21/RB0/V026, PIC4/RA2/V035 and R21.2/V071. Other VREF bias branches remain hypotheses. GND includes BATTERY (-). Candidate regulator outputs of 4.5 V and 3.3 V are datasheet ratings, not measured board voltages.

## Controller, motor and controls

Every PIC pad has a local modeled net. User continuity resolves RC4/RC5 to H-bridge INA/INB and all five tuning-control inputs: RC6-R13, RA3-R14, RA4-R15, RA5-R16, RC0-R11. RC1 reaches R18 via V053-V070; the old VREF join is rejected. RC2 reaches TP3. The [complete PIC table](../evidence/pic_gpio_status.csv) distinguishes each evidence basis.

Some connected PIC nodes still lack a known remote role, notably PIC2/C25, PIC14/TP11 and PIC18/TP17. The R41.1 button node is isolated; S1 common lead pairs are provisional. J1 physical pin orientation, D6 protection routing and motor connector A/B orientation need resolution.

## RF drive and antenna tuning

U2/C14R supports a dual Schmitt inverter. Q8/3724A supports a complementary MOSFET candidate. V113/V115 ground its centre B2/native5; V114 is U2.T2 ground, not Q8. Earlier low-resistance readings support the joined outer Q8 pads. C6-to-output was rejected by a 400 kohm result; its 10 ohm reading toward the opposite centre pad is not proof of a direct wire.

The five control inputs are mapped, but capacitor-midpoint continuations and ANT2 are not complete. Seven OL readings reject a simple shared-midpoint assumption; no broad pair sweep remains queued. Capacitor values and transistor orientations still constrain the circuit interpretation. D1.R is also a local isolated node.

## Receiver and PIR interface

The 11.2 kohm V064-V070 measurement fits nominal R19 + R18 and supports the Q7 supply-switch hypothesis. Q7 terminal selection remains photo/circuit inference. V082 reaches board VDD, but the D3 terminal is unknown; the modeled receiver rail must not be merged blindly. Op-amp feedback, coupling and bias branches are still partly inferred. TP6/C18.2 and U3.5/C18.1 are separate sides of a capacitor.

U6/C2NM supports S-812C33AMC; the supervisor guess based on WN23 is withdrawn. User confirms V067 to J3.1/red PIR supply. The model's J3.2 ground and J3.3 raw-signal roles, U6 external branches and Q2 interface need cross-checking. Wire colour alone does not establish a role. The separate PIR board's internal circuit is outside this main-board reconstruction.

## Reading uncertainty

Unconnected physical pads, isolated labels, incomplete onward routes, candidate identities, unmarked values and package geometry are different gaps. The checklist covers all of these, with exact open-pad and capacitor lists. Do not remove a question mark merely because a symbol exists or a plausible typical circuit can be drawn. Record deliberate assumptions explicitly if exact identity or value cannot be recovered.

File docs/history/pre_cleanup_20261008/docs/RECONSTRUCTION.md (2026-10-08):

# PetSafe functional reconstruction, v0.9.9

Current correction: **BATTERY+ -> Q1 -> VSYS**, with **L1/L2 supply sides and MX512H pin4 on VSYS**. Board **VDD** is the separate regulated test-point rail; **VREF** now includes V035/RA2/C39 as well as V026/RB0 and V071/R21. V042 confirms PIC20/C32.1 on VDD. Ground uses the printed **GND** name; battery negative joins it. Q1 is now a marking-backed **FMOS3401A PMOS candidate**, installed using the stock KiCad symbol through MCP. See [current power-path evidence](VIA_REVIEW_RESULTS.md) and [manufacturer sources](SOURCES.md).

Current checks: 83 native/model partitions; 36 ERC findings (28 open pads, 3 isolated labels, 5 power findings). Zero open PIC pads in the model; partial nets and hypotheses remain. The explanatory sections below originated in earlier revisions; the current via findings and completion report supersede old counts and connection hypotheses.

The deliverable is one editable KiCad schematic sheet with all 150 entries in the original main-board catalog. It uses wires inside functional blocks and labels between blocks. The 150 entries include named pads, test points and unpopulated footprints; they are not 150 fitted components. The separate PIR daughterboard appears in the photos, but only its main-board connector and interface are modeled here.

The user's instruction to make calculated guesses governs this revision. The imported v0.1 documents requested a measurement-first workflow; those documents are historical reference, not instructions overriding the current task. The original ZIP, photographs, capture and source model remain available for comparison.

## Follow-up identity review

The [corrected marking report](U6_Q8_MARKING_UPDATE.md) supersedes the historical WN23/372A interpretation. Sharp photos read C2NM and 3724A. U6 is a strong ABLIC S-812C33AMC 3.3 V regulator candidate; Q8 is a complementary N/P MOSFET with SIL3724A as a datasheet candidate. U6 ground is supported by user resistance readings, while input/output and some Q8 copper routing remain inferred.

## How to read the drawing

- `H_*` names identify inferred inter-block nets. A name without this prefix is not a measurement claim: local wiring also contains hypotheses.
- `?` marks candidate identities, pin roles and estimated values. An unknown unmarked capacitor remains `?` unless a useful conventional starting value has been selected.
- 28 original `VISUAL_LOCAL` fragments remain joined. The user explicitly withdrew V_Q1_LEFT (Q1.L-R43.2) in v0.9.4; it is preserved only as rejected historical evidence. Their source photographs remain in `original_visual_fragments` in the JSON. Even these fragments are photographic evidence, not continuity results.
- New links carry individual evidence classes; some pairwise GPIO connections are now user-reported multimeter checks. `evidence/proposed_nets.csv` distinguishes each proposed net and the original fragments it contains. Merging several visual fragments into one net is an inference.
- Open pins mean unresolved; they do not carry fabricated no-connect flags. No power flags were added just to silence ERC.
- U2/U3 have separate functional and supply units; Q8 has separate N/P units on this same A2 sheet. There are 20 stock definitions from the installed KiCad 10 libraries plus four user-authorized datasheet definitions, all placed or replaced through the KiCad MCP server. Library pin numbers are mapped to photographed pad IDs in `evidence/pin_crosswalk.json`.
- U1 and U5 now have datasheet-derived symbols created through MCP after explicit user authorization. Their 13 numbered pins and standard footprints were checked. U6/Q8 now have datasheet-backed candidate symbols; their 11 pins and stock package footprints are checked independently in the native netlist.
- [LIBRARIES_AND_ALTERNATIVES.md](LIBRARIES_AND_ALTERNATIVES.md) records stock symbols, package choices and Western alternatives. The fitted identities remain in the reconstruction. Selecting an alternative does not authorize changing the board pin map.

## Identity candidates

Confidence describes identification, not confidence in every connected wire. Primary sources are linked in [SOURCES.md](SOURCES.md).

| Ref / visible mark | Working identity | Confidence and reason | Remaining alternative or limitation |
|---|---|---|---|
| U1 / PPEK | ABLIC S-1200B45-M5T1x, 4.5 V LDO | Strong. Manufacturer Rev.6 page 23 explicitly maps PPE to this SOT-23-5 part; fourth character is lot code. Pinout also fits input/output capacitor fragments. | Exact environmental suffix is not recoverable from this mark. Actual rail voltage and routing remain unmeasured. |
| U2 / C14R | TI SN74LVC2G14DBV, dual Schmitt inverter | Strong. Manufacturer ordering table lists C14R for the six-lead DBV package. Two outputs fit the two 220-ohm resistors near Q8. | Package orientation is inferred from the photographed pin-one dot. This is not a single-gate five-pin device. |
| U3 / SGM8542XS | SGMICRO dual op-amp | Strong; readable full marking and standard eight-pin dual-op-amp arrangement. | External signal path and filter values remain hypotheses. |
| U4 / PIC16F18855 | Microchip PIC16F18855, 28 pins | Strong, supplied capture and photograph. | Peripheral pin select means a typical application cannot establish the board's GPIO map. |
| U5 / MX512H | Mixic dual-input H-bridge | Strong, readable marking and manufacturer pin diagram. | J5 A/B order and MCU control destinations are not visible enough to establish. |
| Q2 / 1FW56 | BC847B NPN | Good candidate; Nexperia identifies 1F plus a manufacturing-site character. | Manufacturer, lot interpretation and physical orientation still need corroboration. |
| Q7 / 3GW54 | BC857C PNP | Good candidate; Nexperia identifies 3G plus a manufacturing-site character. | Switched receiver supply role is inferred. |
| Q1 / R1A | FMOS3401A-class PMOS | Formosa datasheet p5 explicitly lists R1A and matches the package/power path. | Exact fitted maker unconfirmed; reverse-polarity-protection role inferred. Earlier MMBT3904 NPN hypothesis withdrawn. |
| Q3/Q4/Q5/Q6/Q11 / 2H | MMBTA55/FMMTA55-family PNP | Plausible. Taitron's manufacturer catalog lists MMBTA55 with 2H marking. Five repeated cells suggest switched capacitance. | PBSS5140T is another PNP candidate; the short code is not globally unique. Neither exact part nor B/C/E orientation is certain. |
| D1 / A7 | BAV99 series dual diode | Good candidate. Nexperia lists A7 and the expected SOT23 dual-series topology. | Photo-to-pin orientation remains inferred. |
| D3 / A7 | BAV99 series dual diode candidate | User-confirmed A7; manufacturer marking match. | Board orientation and clamp routes remain inferred. |
| D2 / 4P | Unidentified three-terminal part | Zetex FMMT2907R is an exact code/package lead, not a verified identity. | Numbered stock placeholder; all three guessed clamp ties withdrawn. |
| Q8 / 3724A | SIL3724A? complementary N/P MOSFET | Strong device-type match: MCC datasheet explicitly shows mark and six-pin map. | Fitted manufacturer unconfirmed; external copper connections inferred. |
| U6 / C2NM | ABLIC S-812C33AMC-C2NT2x, 3.3 V regulator | Strong C2N code/package match; pin1=C/R3 supported by low resistance to ground. | Rail voltage and input/output routing unverified; RT9818 withdrawn. |

## Physical pad mapping

Original physical identifiers are kept so an identity correction does not silently renumber the evidence.

| Device | Proposed photographed-pad to datasheet-pin map |
|---|---|
| U1 | L1=1 VIN, L2=2 VSS, L3=3 EN, R1=5 VOUT, R2=4 NC |
| U2 | T1=3 2A, T2=2 GND, T3=1 1A, B1=4 2Y, B2=5 VCC, B3=6 1Y |
| U3 | 1 OUTA, 2 -A, 3 +A, 4 VSS, 5 +B, 6 -B, 7 OUTB, 8 VDD |
| U5 | 1 logic VCC, 2 INA, 3 INB, 4 motor VDD, 5 OUTB, 6/7 GND, 8 OUTA |
| Q1 | R=gate1, L=source2, single S=drain3 for the FMOS3401A candidate; photo S means single pad |
| Q2 and tuning PNPs | R=base, L=emitter, S=collector, provisional |
| Q7 | L=base, R=emitter, S=collector, provisional |
| D1 | L=pin 1/anode 1, R=pin 2/cathode 2, S=pin 3/midpoint, provisional |
| U6 | R3=1 VSS (probe C), R2=2 VIN (B), R1=3 VOUT (A), L1=4 NC, L2=5 NC |
| Q8 | T3=1 G_N, T2=2 S_P, T1=3 G_P, B1=4 D_P, B2=5 S_N, B3=6 D_N |

KiCad requires numerical reference endings. C1A/C2A/U6A are C101/C102/U106 in the native file, with the original reference in a property and visible value. GND/GND_RF/VDD/VREF/ANT1/ANT2/BATP/BATN are TP101 through TP108. This is reference normalization, not additional physical components.

## Functional decisions and calculations

### H01 - main supply

Selected path: battery positive -> L2 -> U1, with EN tied to its input and nominal 4.5 V output distributed as H_VDD. C1=1 uF and C2=4.7 uF are design starting values, not recovered markings. ABLIC permits small ceramic input/output capacitors; the larger proposed output bulk value also supports the MX512H logic-supply decoupling requirement. The original U1.R2/R1.2/C3.2 fragment is retained, but R1/R2/C3/C4 are empty option footprints. Pin 4 is NC for the identified regulator, not an invented feedback input. Ground pads across blocks are provisionally unified.

### H02/H03 - controller, programming and battery sense

PIC power, crystal and ICSP functions come from the 28-pin datasheet. The two photographed crystal fragments are retained. The visible oscillator marking is 20 MHz. C30/C31=18 pF are provisional: equal 18 pF capacitors give 9 pF in series, and approximately 3 pF stray would yield a 12 pF effective load. The crystal's actual specified load is unknown.

R3=R4=330 kohm suggests battery sensing: Vout=VBAT/2 and I=VBAT/660 kohm, approximately 3 V and 9.1 uA at a hypothetical 6 V battery. No ADC pin is assigned solely from this calculation. ICSP mapping is inferred from datasheet functions and the named header pads. Remaining GPIOs are open rather than arbitrarily numbered.

### H04/H05/H06 - motor, discrete interface and button

U5 retains separate logic and motor supplies. The datasheet application has at least 4.7 uF logic decoupling; C34 is proposed as local 100 nF, supported by the proposed C2 bulk capacitor. C33=1 uF is a starting motor-supply bypass value. Motor A/B, button pull-up/debounce, and Q1 interface wiring are plausible arrangements, not recovered hidden tracks. R44=15 kohm is conditional on reading its mark as EIA-96 `18C` (150 x 100). R41 is nominal 330 ohm from the user-confirmed 331 marking (33 x 10^1); this resolves the prior ambiguous reading.

### H07/H08/H09 - RF excitation

U2's Schmitt outputs drive the gates of the 3724A N/P MOSFET candidate through R8/R9=220 ohm. Normal transistor symbols replace the numbered placeholder. The selected source rails and shared drains were a push-pull working hypothesis. In v0.9 the user reports V113/V115 as GND, while the front island appears to connect the outer joined pads. That conflicts with the current output model and is held pending resistance clarification; no output-to-ground merge is applied. D-E=2 ohm supports joined drains and S-G=2 ohm supports the N-source ground return. E-F=400 kohm refutes the proposed C6 upper-pad/output tie, so that wire has been removed and C6.1 remains unresolved after F-P=10 ohm and F-G=300 kohm supported a supply-related node without establishing the exact path. L1/C5 and the P-source rail remain a proposed supply filter.

D1 is a BAV99 candidate; its shaping network, LED polarity/common connections and spare R10 monitor routing remain low-confidence choices.

### H10/H11/H12 - receiver

R26=120 kohm and R48=5.6 kohm form the selected first-stage non-inverting feedback pair; R24=120 kohm and R23=5.6 kohm form the second. Each nominal low-frequency gain is 1+120/5.6 = 22.43; their ideal product is about 503 (54 dB). With the SGM8542's approximately 1.1 MHz gain-bandwidth, a simple gain/GBW estimate gives roughly 49 kHz per stage. That is an estimate, not proof of the operating carrier frequency or filter response. Unknown feedback capacitors can reduce bandwidth further.

R21/R22 retain a provisional bias hypothesis. In v0.8 the user identifies R28/R29 free ends and TP7 on RA1; those ends are no longer tied to the other guessed bias nodes. The purpose of this GPIO-controlled/shared reference remains unresolved. Input/interstage coupling, clamp orientation, C19/C20/C21/C22/C23/C40 functions and the output detection path are low-confidence. R29=15 kohm is conditional on the `18C` reading. Both stages have explicit feedback and input bias paths; this makes the chosen hypothesis electrically interpretable without pretending that the photos uniquely establish it.

Q7 is proposed as a receiver supply switch, with R18 feeding its emitter and R20 in series after its collector. Q7/R20's two sides are separate nets; no resistor has been accidentally shorted by sharing a label.

### H13 - antenna tuning

Five repeated PNP-controlled branches are selected. Their capacitor groupings follow front/rear placement:

| Switch | Top capacitor | Other front capacitor | Rear capacitor |
|---|---|---|---|
| Q3 | C10 | C11 | C12 |
| Q4 | C13 | C14 | C15 |
| Q5 | C16 | C29 | C38 |
| Q6 | C43 | C44 | C45 |
| Q11 | C46 | C47 | C48 |

**v0.9 correction:** the user-reviewed ground vias and front/rear lands replace the earlier antenna-rail assignments of all ten front/rear return capacitors and five transistor L pads. The local Ctop/Cfront/Crear midpoint grouping is retained. The earlier complete series-branch antenna hypothesis and its effective-capacitance calculation are withdrawn as a description of this board: hidden connections from V090/V095/V100/V103/V107 to ANT1/ANT2 remain unknown. The existing ANT1-R5 and ANT2-R42 links are retained hypotheses only.

Resonant total capacitance is C=1/((2*pi*f)^2*L). Neither antenna inductance nor operating frequency is established from these files, so numerical capacitor values and binary weighting are not invented. ANT_A/ANT_B naming, transistor orientation and controller line destinations remain hypotheses.

### H14/H15 - PIR interface

The corrected C2NM marking supports an S-812C33AMC regulator: R37 feeds pin2 VIN, C36 bypasses the input, pin3 VOUT feeds C37 and the PIR rail, and pin1 VSS is ground. The user reports C/R3 to G at 2.7 ohm, B/R2 at 34 kohm and A/R1 at 4.2 kohm; shorted tips later read 0.5 ohm. C is likely ground, with contact resistance uncertainty. 3.3 V is the candidate rating, not a measured voltage. NC4/5 remain open in the drawing because their board ties are unknown.

Q2 remains a proposed NPN input stage. In v0.9, R39.2 and R37.1 join V063 with unknown remote feed; their previous GND/VDD assignments are withdrawn. R32.1 instead joins user-GND V024, withdrawing its guessed PIR connection. J3 power/ground/signal assignments remain inferred; daughterboard internals are not traced. D4/D5 carry SD05 5 V TVS candidates; their lower pads are now photo-traced to PIC pins 27/28 respectively. Their opposite pads now join photo-matched VSS-associated rear copper (v0.8). D6 is a provisional MMSZ5228BS 3.9 V Zener, with PZU2.4B as a 2.4 V alternative; both routes remain unresolved. These candidate identities and polarities are not electrically verified.

## Validation and limits

Native KiCad 10.0.5 exports one A2 sheet with 150 references, 155 symbol units and 352 physical pads. The final native pin partitions match all 89 modeled nets. 28 original visual fragments remain joined; V_Q1_LEFT is explicitly withdrawn by the user. All 26 original photo checksums are retained. Twenty stock definitions and four project-local definitions match their registered library graphics and pins. Manufacturer pin-table contracts independently check U1/U5/U6/Q8 in the exported netlist.

ERC reports 51 open findings: 37 unconnected pins, 8 isolated labels, five undriven power checks and one undriven input (LED common). No off-grid endpoints, dangling wire ends or unintended multi-pin net merges remain. U6 and Q8 unpowered resistance readings are recorded; C6 exact path remains unresolved. Functional tests, voltage measurements, completion of GPIO tracing, physical PCB reconstruction and firmware recovery remain undone.

## Remaining completion items, v0.9

All 150 main-board catalog entries are represented. **No further exact-symbol files are missing for the confidently identified ICs.** U1/U5 are now completed from datasheets through MCP. U6/Q8 candidates are also implemented. The remaining work is identity confirmation, values and hidden connectivity:

| Parts / area | Remaining uncertainty | Current working choice |
|---|---|---|
| U6, C2NM | VIN/VOUT board connections and operating voltage | S-812C33AMC? pin map implemented; pin1 ground supported by resistance. |
| Q8, 3724A | Fitted maker and external source/drain connections | SIL3724A? implemented, drain join and ground return supported by resistance; C6 measured as supply-related; exact path unresolved. |
| D3 / A7 | Physical orientation and clamp routing | BAV99 series-dual candidate supported by user-confirmed A7. |
| D2 / 4P | Identity, pin functions and routing | FMMT2907R is a code/package lead only; numbered stock placeholder with all three pads open. |
| D4/D5/D6 | Diode type, polarity and connections | SD05 TVS / MMSZ5228BS Zener candidates assigned; D4/D5 lower pads photo-traced to ICSP clock/data; D4/D5 opposite pads now join photo-supported ground; the two D6 pads remain unresolved. |
| LED1 / S1 | LED emitter configuration/polarity; switch common pairs | Standard symbols present, physical mapping provisional. |
| Q1 | FMOS3401A candidate | Existing stock PMOS symbol; R1A marking and package evidence, exact maker unproved. |
| Q2/Q7 and repeated 2H transistors | Candidate identity and orientation | Existing stock BJT symbols; identity strength varies and is documented above. |
| L1/L2, unmarked capacitors | Bead versus inductor, capacitance and package sizes | Standard passive symbols present. Proposed decoupling values are estimates; RF filter/tuning values remain unknown. C27 is now across motor supply and GND; C41 now shunts the TP4/RB4 net to photo-supported ground. |
| PIC and block interfaces | Exact GPIO destinations and hidden tracks | 6 PIC pads remain open: 5,6,7,11,13,21. PIC15/16 now reach MX512H INA/INB. RC1/pin12 now reaches VREF/V053; remote roles remain partly inferred. See pic_gpio_status.json. |
| PIR daughterboard | Internal components and routes | Only the J3 interface is represented; daughterboard internals are outside the current main-board revision. |

The 37 open physical pins include 19 on unpopulated/DNP entries; the other 18 include named test pads and two internally open U6 pins. They are not 37 missing parts. U7/U6A/Q9 and other DNP entries do not require identifying a fitted chip. The machine-readable list is `evidence/completion_status.json`. Further photo/datasheet inference can continue without a broad measurement campaign. A completely confirmed schematic cannot be claimed from missing identity, value and buried-trace evidence.

## Package and value audit, v0.6

R29 and R44 both read 18C in the original photos (IMG_2434 and IMG_2438 respectively), yielding nominal 15 kohm using EIA-96. This resolves their value question marks without new measurements. 126 stock footprints were assigned using MCP, leaving C5/S1/LED1 for dimensions and pad mapping. FootprintConfidence and FootprintBasis properties retain the distinction between photo estimates and measured geometry. No net partitions were changed. The detailed per-part [completion audit](FINISHING_CHECKLIST.html) separates value, identity, package and routing gaps.

## Superseding v0.7 photo audit

The earlier generic PIC supply and battery-divider interpretation is partly contradicted by visible copper. This section takes precedence over those v0.6 descriptions. New direct GPIO routes: U4.2 to C25 right pad; U4.4 to C39 left pad; U4.24 to R4 lower pad; U4.26 to TP10 and R35 upper pad; U4.18 to TP17, with probable top-edge continuation to R13 upper pad. C32 visibly bridges U4.20 and U4.19, not the PIR rail. R35 is empty: its lower pad/Q9 lower-left are a separate local net.

D4 lower cathode candidate/R32 lower pad connect U4.27; D5 lower cathode candidate/R40 upper pad connect U4.28. Their old R32/PIR-supply and R40/VDD ties are withdrawn. C41 right pad connects TP4; its under-U4 continuation is unknown, so TP4 is removed from the antenna net. C26 no longer has the unsupported VDD tie. C25/C39 no longer have generic 100n bypass values. Ground assignments at their opposite pads and remote interface roles remain inferred.

C5 is 470uF/16V from the user. C11 dimensions support 1206; R8 complete-body dimensions including both metal end caps confirm the 0603 size match, revising the repeated fitted resistor package family provisionally. All 147 assigned footprint files remain standard-library candidates. C5 body/lead geometry, S1 and LED1 remain unassigned.

The v0.7 model has 87 net partitions, 54 open physical pads and 14 open PIC GPIOs. See evidence/pic_trace_audit.json and the annotated PDF. Existing photo resolution is enough for the direct local changes above; unresolved pad exits/top-edge continuations benefit from sharper, overlapping straight-on photos. Hidden copper still may need targeted continuity.

## Superseding v0.8 user continuity and via comparison

This section supersedes conflicting v0.7 guesses above. The user checked both visible copper and multimeter continuity. Recorded mappings are U4.3/RA1 to R28/R29/TP7; U4.17/RC6 to R13; U4.22/RB1 to TP2; U4.23/RB2 to TP1; U4.25/RB4 to TP4; U4.26/RB5 to TP10 corroborated. RP7 in the reply is interpreted as the photographed TP7. Exact ohms were not supplied; resistor free-end pin1 mappings use local photographs.

Removed hypotheses: RC7/TP17 onward to R13, TP2 to RF supply, TP1 to LED common, R28/R29 to the other bias nodes and TP7 to the speculative detector node. Retained local photo trace: RC7 to TP17, with remote continuation unknown. Existing receive feedback/coupling and LED polarity/common remain provisional.

D4.2/V030, D5.2/V027 and C41.2/V025 join the main rear copper without apparent clearance, identified using PIC VSS8/V041 and VSS19/V045 anchors. Added these three photo-supported grounds; C39.2/C26.2 ground estimates are corroborated. VDD20/V042 has rear clearance, as does RC1/V053. The latter remains electrically unidentified. See the [interactive via comparison](VIA_REVIEW.html).

The inventory is 127 visible rear sites with 10 individually matched anchors, not every physical via and not 127 resolved nets. Layer count, hidden power planes and occluded routing are not uniquely recoverable from surface photographs. The user's four-layer hypothesis is retained as plausible, not a confirmed stackup.

GPIOs 12,15,16,21 have reported vias with unknown onward nets. GPIOs 5,6,7,11,13 have no visible continuation; traces/vias under U4 remain possible. None is certified NC.

## Superseding v0.9 via evidence

Read [via review results](VIA_REVIEW_RESULTS.md) for all 28 endpoint corrections, held conflicts and component associations. The [complete status PDF](../output/pdf/PetSafe_completion_status.pdf) lists every current gap and every PIC pin. The updated viewer retains rear appearance separately from reported electrical identity. V050 is excluded without renumbering. No per-via resistance values or measured rail voltages were supplied in this review. The four-layer hypothesis remains unverified by surface photographs.

## v0.9.1 incremental via correction

101 distinct via IDs reviewed; 125 active sites / 127 stable IDs. V033 and V050 are rejected without renumbering; 26 IDs remain unmentioned, some already photo-matched. The latest batch corrects 21 sites. V017 joins R42.1 and R44.1 (R44 pad selected from the photo), replacing the earlier R42.1-to-ANT2 hypothesis. R43.2 is associated with V015, not V011-V014. V072-to-R22.2 is withdrawn. V073 is GND only; R19/V075 remains photo-derived. V113/V115 are the two remaining held conflicts.

R42.1/R44.1 share the new `V017_CONTROL` net; its function is unknown. The independent original Q1.L/R43.2 local fragment is retained at V015. Removing V072 from R22.2 does not validate or replace the earlier receiver-bias hypothesis. Further review is deferred at the user's request.

## v0.9.2 RF and receiver via review

111 distinct via IDs reviewed; 120 active sites / 127 stable IDs. The latest 19-site batch excludes V117/V120/V121/V122/V124 without renumbering. V113/V115 now correctly point to Q8 centre B2/pin5, GND; the old outer-pad annotation is withdrawn. V077 confirms C19.2/R29.2 are GND, replacing the earlier clamp/op-amp-input guesses. V091/R11, V097/R16, V102/R15 and V108/R14 identify tuning-control resistor ends, with onward GPIOs unknown. V114 reaches the opposite centre T2/pin2, but its earlier GND assignment versus source-supply hypothesis remains unresolved. V075 identifies Q7; exact terminal remains unspecified.

C19 pad2 is assigned to the upper pad beside V077 in IMG_2434; its other-pad routing remains inferred. R29.1 retains the PIC3/R28/TP7 user mapping; R29.2 becomes GND. The old R29-to-U3.5 and C19-to-clamp branches are withdrawn, while the original U3.5/C18.1 visual fragment remains joined. V114 is kept as a pad association with unknown net; Q8.T2 supply remains a separate hypothesis. The two Q8 outer drain pads remain joined from the earlier D-E reading, independently of the corrected centre-ground via association.

## v0.9.3 PIC and receiver via confirmations

118 distinct via IDs reviewed; 120 active sites / 127 stable IDs. The latest eight-site batch confirms V036=PIC5/RA3, V037=PIC6/RA4, V039=PIC7/RA5, V047=PIC11/RC0 and V049=PIC13/RC2. All eight GPIOs without modeled onward connections now have user-identified vias. V072 reaches TP6, explicitly not R22.2. V079/V080 both reach SGM8542 U3 pin5; TP6 and U3 pin5 remain separate across C18. Nine IDs are still unmentioned. Earlier Q8 and C19/R29 ground corrections remain; V114 net and V075 Q7 terminal are unresolved.

This batch adds local via evidence without changing any component-to-component net partition. Native GPIO pads remain open because a via with an unknown onward destination is not a fitted component or an NC. The schematic annotations and updated numbered map show the confirmed associations. RX_A_FILTER (TP6) stays separate from RX_B_PLUS (U3.5) across C18; neither is merged into the inferred R22.2 bias network.

## v0.9.4 confirmed motor controls and withdrawn Q1 tie

120 distinct via IDs reviewed; 120 active sites / 127 stable IDs. PIC15/RC4 connects through V022-V016 to MX512H INA pin2; PIC16/RC5 connects through V023-V019 to INB pin3. Six GPIO onward destinations remain unknown. V011-V014 reach Q1.L. The user explicitly removes the old Q1.L-R43.2 photo-derived connection; R43.2 still reaches V015. Seven IDs remain unmentioned, some already photo-matched. V114 net remains the only held via conflict.

MOTOR_INA and MOTOR_INB replace the H_ names because the PIC-to-driver connections are user-confirmed. This does not establish motor polarity or operating firmware states. The original V_Q1_LEFT photo fragment remains in the evidence history, explicitly withdrawn by the user; it is no longer imposed as a validation requirement. Native checks instead require Q1.L and R43.2 to be separate.

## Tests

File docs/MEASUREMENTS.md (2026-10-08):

# Recorded measurements and observations

Current as of 2026-10-08. These are user reports, not measurements performed by software. Full event records remain in `evidence/measurement_plan.json`, `evidence/via_audit.json`, the versioned net-change records and the [via-pair results](VIA_PAIR_TESTS.html). [The checklist](FINISHING_CHECKLIST.html) distinguishes remaining work.

## Numeric electrical results

The measurement requests specified battery and programmer disconnected. Shorted probe tips were initially pressure-dependent (2-5 ohm), then the user obtained **0.5 ohm**. Do not subtract a fixed baseline from every earlier reading or describe 2 ohm as exact copper resistance.

| Test | User reading | Interpretation |
|---|---|---|
| U6 G-C | 2.7 ohm | Supports ground at C; contact baseline was uncertain |
| U6 G-B | 34 kohm | Resistive path, not a direct ground join |
| U6 G-A | 4.2 kohm | Resistive path, not a direct ground join |
| Q8 D-E | 2 ohm | Supports the joined outer-pad node |
| Q8 E-F | 400 kohm | Rejects direct C6-to-output copper |
| Q8 S-G | 2 ohm | Supports ground association |
| Q8 F-P | 10 ohm | Exact path remains unresolved; not a proven copper join |
| Q8 F-G | 300 kohm | Not direct ground |
| V064-V070 | 11.2 kohm | Supports R18 1.2k + R19 10k hypothesis; not direct VDD |
| V049-V071 | 20 kohm | Not direct continuity |
| V049-V070 | Variable 200-300 kohm | Contact-dependent/inconclusive, not OL |
| V090 to V095/V100/V103/V107 | OL, all four | No direct continuity in this test |
| V095 to V100/V103/V107 | OL, all three | No direct continuity in this test |

Lettered Q8/U6 endpoints refer to the preserved annotated measurement photos, not package pin numbers. OL does not imply the absence of capacitive coupling.

## Confirmed connections and exclusions

Reported connections without numerical resistance are recorded as **user continuity reports**, not fabricated 0.0-ohm readings. Key examples include V022-V016 (PIC15-U5.2), V023-V019 (PIC16-U5.3), V036-V108, V037-V102, V039-V097, V047-V091, V064-V063, V064-V075, and V053-V070. See the [current via summary](VIA_REVIEW_RESULTS.md) and per-site audit for all reports.

V053-V071 and V053-VREF were explicitly rejected. Q1.L-R43.2 was explicitly withdrawn. Raw BATTERY+ and post-Q1 VSYS are distinct nets. V114 was corrected to U2.T2 ground, not Q8. V072 reaches TP6, not R22.2. These negative/corrective results remain constraints on future edits.

## Markings and dimensions

User readings: U6=C2NM; Q8=3724A; D2=4P; D3=A7; D4/D5=5U; D6=G3; R41=331 (330 ohm); C5=470 uF / 16 V. R29/R44=18C (15 kohm) came from photographs rather than a new meter reading.

User dimensions: C11 approximately 3.2 x 1.5 mm supports 1206; R8 approximately 1.6 x 0.77 mm, **including both metal end caps**, supports 0603. Other packages remain family/photo estimates until individually supported.

## Not yet measured

No actual rail voltages, powered functional results or LCR capacitor/inductor values have been supplied. The user has an LCR meter and multimeter. Prioritize RF/tuning values; record frequency, mode and in-circuit versus isolated-lead status. Do not infer a ceramic's value, voltage rating or dielectric from package size.

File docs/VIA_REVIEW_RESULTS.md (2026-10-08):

# Current via findings

This summary replaces the chronological investigation as the current view. [The viewer](VIA_REVIEW.html) and `evidence/via_audit.json` retain all per-site reports, corrections and rejected recognition artifacts. [Historical text](history/README.md) remains available.

- 123 IDs reviewed; 120 active sites after recognition-artifact rejection. Four unmentioned IDs were already photo-matched ground candidates. These are inventory counts, not a remaining-wire count.
- All PIC pads have modeled local nets. The residual search pool has nine sites in eight local groups; these are not eight proven missing nets.
- No broad via-pair measurement sweep is pending. Seven capacitor-pair OL results and the rejected V053/VREF/V071 joins remain recorded.

| Confirmed report | Current interpretation |
|---|---|
| V022-V016 | PIC15/RC4 to U5.2/INA |
| V023-V019 | PIC16/RC5 to U5.3/INB |
| V036-V108 | PIC5/RA3 to R14 |
| V037-V102 | PIC6/RA4 to R15 |
| V039-V097 | PIC7/RA5 to R16 |
| V047-V091 | PIC11/RC0 to R11 |
| V049-TP3 | PIC13/RC2; R10 local branch photo-derived |
| V053-V070 | PIC12/RC1 to R18.1; not VREF |
| V026, V035, V071 to VREF | PIC21, PIC4/C39, R21.2 respectively |
| V042 to VDD | PIC20/C32.1 logic supply |
| V064-V063 | VDD feed to R37/R39 |
| V064-V075 | Q7 supply node; exact terminal selection remains photo-derived |
| V067-J3.1 | Red PIR supply; U6A option association retained, still DNP |
| V015-TP14 | R43.2 on raw BATTERY+; separate from Q1.L |
| V017-TP4 | R42.1/R44.1 and PIC25/RB4; local pad selections photo-derived |
| V082-VDD TP | VDD confirmed; D3 terminal still unknown |
| V011-V014-Q1.L-U5.4 | VSYS, separate from BATTERY+ and board VDD |
| L1/L2 same VSYS | Supply sides share VSYS; opposite filter ends remain separate |
| V114 | U2.T2/native2 GND, not Q8 |
| V113/V115 | Q8 centre B2/native5 GND |
| V077 | C19/R29 junction GND |
| V072 / V079-V080 | TP6 / U3.5 respectively; separated across C18 |
| V125/V126 / V127 | C5 negative / photo-selected LED common ground |

The remaining candidate groups are V031 (PIC2/C25), V072 (TP6/C18.2), V079/V080 (U3.5), and V090/V095/V100/V103/V107 (five capacitor midpoints). The [completion checklist](FINISHING_CHECKLIST.html) also covers gaps with no unresolved via ID: D2/D3/D6, C6, button/antenna endpoints, identities, values and geometry.

A user report that a via reaches a component does not establish which pad unless specified. Do not promote all attached hypothetical branches to measured status. Surface clearance does not identify an inner-layer net or prove a four-layer stack.

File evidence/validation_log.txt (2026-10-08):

Native KiCad model/netlist cross-check: PASS
{
  "date": "2026-10-08",
  "native_tool": "Eeschema 10.0.5",
  "native_load_and_export": "PASS",
  "single_sheet": "PASS",
  "catalog_components": 150,
  "symbol_units": 155,
  "physical_pins": 352,
  "stock_library_symbols": 20,
  "custom_symbols": 4,
  "proposed_net_partitions": 83,
  "netlist_partition_comparison": "PASS",
  "unintended_multi_pin_nets": 0,
  "retained_original_visual_fragments": 28,
  "withdrawn_original_visual_fragments": [
    "V_Q1_LEFT"
  ],
  "original_photo_checksums": "PASS (26 files)",
  "unresolved_physical_pins": 28,
  "erc_total": 36,
  "erc_by_type": {
    "power_pin_not_driven": 5,
    "pin_not_connected": 28,
    "isolated_pin_label": 3
  },
  "erc_status": "OPEN FINDINGS - candidate IC pin types checked; unknown board routing remains",
  "gui_open": "NOT_TESTED (native CLI validated)",
  "hardware_verification": "PARTIAL: recorded U6/Q8 resistance and selected PIC meter/visual routes; user via reports plus photo cross-checks; circuit hypotheses remain; no functional or voltage test",
  "physical_pcb_layout": "NOT_CREATED",
  "schematic_sha256": "82e726dcbfc1dcad72cfe59cf4f342af0eba7867529473be2bcb66c36851ad5b",
  "input_zip_sha256": "151a5d246b051c6ee7edf50bac941261d3d87defedf9590f2ce442158552b52d",
  "datasheet_symbol_pin_contracts": "PASS (U1: 5 pins; U5: 8 pins; U6: 5 pins; Q8: 6 pins; types, footprints and source properties)"
}

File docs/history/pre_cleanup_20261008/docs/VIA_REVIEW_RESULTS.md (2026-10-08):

# Via review findings - v0.9.9

## Current v0.9.9: battery path, board labels and two new via checks

The earlier `H_VBAT` reconstruction incorrectly connected battery positive directly to the post-Q1 supply. This is corrected, not just renamed. User-authorized **VSYS** now names the previously unlabelled post-Q1 node. Printed board names are retained everywhere else.

| Name | Physical connection | Evidence |
|---|---|---|
| BATTERY (+) / net BATTERY+ | Battery positive to Q1 single pad3; TP14 and V015/R43.2 on this side | User battery/Q1 report, visible copper in IMG_2438, user V015-TP14 check |
| BATTERY (-) / GND | Battery negative, common ground | Existing board/ground review |
| VSYS | Q1.L/pad2, V011-V014, MX512H U5 pin4, L1/L2 supply sides | User reports; L1/L2 pad1 selections retained from photos |
| VDD | Board VDD test point TP103, PIC20/C32.1/V042, U5 pin1 VCC | Existing reconstruction; user V042-VDD and V082-VDD checks |
| VREF | Board VREF test point TP104, V026/PIC21, V071/R21.2, now V035/PIC4/C39.1 | User via-to-test-point checks; local pad selections from photos |

Battery+ and VSYS are **different copper nets connected through Q1**, not completely isolated circuits. L1 and L2 remain components between VSYS and their downstream nodes: their two terminals are not shorted together by this update. VREF is a connectivity label, not a measured reference voltage. No supply voltages have been measured.

Q1's old **MMBT3904 NPN hypothesis is withdrawn**. [Formosa FMOS3401A manufacturer datasheet](https://www.formosams.com/upload/product/Mosfets/FMOS3401A_REV_C.pdf), page 5, explicitly lists R1A / 3401 / R1 and shows a P-channel MOSFET: gate on the photo right paired pad (pin1), source on left paired pad (pin2), drain on single pad (pin3). Thus **photo Q1.S means single pad, not source**. The stock `Transistor_FET:Q_PMOS_GSD` symbol was installed through KiCad MCP. Exact fitted maker remains unverified. Drain-to-battery/source-to-load is consistent with reverse-polarity protection; gate behavior and powered operation remain unverified. [TI's explanation](https://e2e.ti.com/support/power-management-group/power-management/f/power-management-forum/944817/mc33063a-q1-reverse-polarity-protection-using-p-mosfet) supports that topology, not this board's identity.

The additional downstream supply branches are L2-to-U1 input, L1-to-RF/Q8, Q7-to-receiver, and U6-to-PIR. These are component-separated nodes; some routing and function are still inferred. They are not all independently regulated rails. Candidate 4.5 V / 3.3 V ratings are not measurements.

**V035-VREF** joins the previous RA2/C39 local node to VREF. **V042-VDD** confirms the existing PIC supply connection. These reports do not certify every prior inferred branch on the enlarged VREF net. RC1/V053 remains separate from VREF.

Current verification: **83 native/model net partitions; 36 ERC findings = 28 open pads + 3 isolated labels + 5 power findings**. No PIC pads are open in the model. All 26 original photo checksums retained. 123 reviewed IDs, 120 active via sites, no unresolved numbering conflicts. The remaining search pool is 9 sites in 8 local groups, not eight proven missing nets. No new measurement is queued.

Earlier sections below are historical snapshots; old net names and hypotheses are superseded by this section.

## Historical v0.9.8: GPIO destinations and PIR option supply

- User confirms **V053–V070**: PIC12/RC1 reaches R18.1 (`H_RX_ENABLE_CTL`).
- User explicitly says **V053 is NOT connected to VREF**. Old photo-only RC1–VREF association is rejected.
- **V026–VREF**: PIC21/RB0 reaches native TP104, now labelled simply `VREF`. The label does not establish its voltage/function.
- **V049–TP03**: interpreted as photographed TP3, establishing PIC13/RC2–TP3. Existing TP3–R10.1 local branch stays photo-derived.
- **V067–J3 pin 1/red wire**: earlier U6A.R1 pad association joins `H_PIR_VDD`. U6A remains DNP; other supply branches retain their existing confidence.

No numerical resistance was supplied for these new connections. V049–V070 variable 200–300 kΩ remains recorded as contact-dependent, not definite OL. D2 V070–V026 was unmeasured and withdrawn, not rejected. Q7/R19 local topology remains photo/resistance-supported inference.

**No PIC pads remain open in the model.** Remaining work is not zero: other partial local nets, candidate identities, 44 unmarked ceramic values, L1/L2 values and three exact package geometries remain. **84 modeled net partitions PASS; 36 ERC findings = 28 open pads (10 populated-entry, 18 DNP) + 3 isolated labels + 5 power findings.** All 26 original photo checksums retained. Current status and numbered map rebuilt; the pair guide shows a completed result with no repeat request.

The sections below are historical snapshots; later user corrections above take precedence.

## Latest evidence-only update: D1 variable high resistance

**V049–V070 = 200–300 kΩ depending on probe placement.** No direct continuity demonstrated. The result is kept as contact-dependent/inconclusive, distinct from a definite rejected pair or OL. Native v0.9.7 wiring remains unchanged; no RC2-to-R18 link is added. The next candidate is V070–V026 (PIC21/RB0); if also high, check known-pair and local-pad contact before further searching.

## Historical v0.9.7: resistive path and Q7 reconstruction

**V064–V070 = 11.2 kΩ**, with no reverse reading supplied. This rejects the direct R18 input-to-VDD assumption. It matches the nominal **1.2k R18 + 10k R19** series path. Together with IMG_2434 and the confirmed V064–V075 supply link, it supports a PNP supply-switch reconstruction: Q7.R/native2 emitter at VDD; Q7.L/native1 base joined to R18.2 and R19.1; R19.2 pulled to VDD; R18.1/V070 remains an unknown control source. Q7.S/native3 retains its collector path through R20.

**Additional reading: V049–V071 = 20 kΩ.** Recorded as a resistive path, not a direct RC2/R21 tie. V071 differs from V070; the pending V070–V049 check is still unmeasured. No path through specific resistors is inferred from this reading alone.

Those local pad assignments are explicitly **photo/circuit inferences supported by the resistance**, not new user-probed terminal confirmations. Candidate BC857C identity and operating function remain qualified. No MCU connection is guessed into the schematic. The initial RC2 candidate has now been tested with a variable high reading; see the latest update above.

KiCad 10.0.5 native/model validation: **84 partitions PASS; 42 ERC findings (33 open pads, four isolated labels, five power findings)**. All 26 original photo checksums remain intact. See [search reasoning and current test](VIA_PAIR_SEARCH.md).

## Historical continuity follow-up before v0.9.7

**V064–V075 is user-confirmed**, placing V075 on regulated VDD. No numerical resistance was supplied. V075 was previously associated with Q7, without a terminal; Q7.R/R19.2 remain photo candidates from IMG_2434. No terminal-level native merge is made from that component-only association. V064–V070/R18 is a different, unreported test.

**V095–V100, V095–V103 and V095–V107 all measured OL.** Together with the earlier V090 sweep there are seven excluded capacitor pairs. Stop the broad shared-node search; the three untested mutual pairs remain unknown. The [updated reasoning and single next check](VIA_PAIR_SEARCH.md) explain the changed search direction. Via graph now includes the V063/V064/V075 supply group and symmetric negative-pair records.

## Prior v0.9.6 results, retained

Four tuning-control pairs are confirmed: **V036–V108 = RA3–R14**, **V037–V102 = RA4–R15**, **V039–V097 = RA5–R16**, **V047–V091 = RC0–R11**. With the earlier RC6–R13 route, all five controls are mapped. Only RC2/pin13 and RB0/pin21 remain open GPIOs.

**V064–V063** confirms that the R37/R39 feed junction is regulated board VDD. The former separate `AUX_FEED_V063` hypothesis is merged into that rail. Motor VDD remains separate.

**V053–V071 is rejected. V090–V095/V100/V103/V107 all measured OL.** No corresponding direct connection is introduced. The remaining capacitor junctions could still form other groups; their mutual relationships remain unmeasured.

KiCad 10.0.5 validates 87 modeled net partitions. ERC: **42 findings = 33 open pins + 4 isolated labels + 5 power-drive findings**. Open pads comprise 14 populated-entry and 19 empty-option pads. All original photograph checksums pass. Q1's user-reported VDD still needs its rail distinguished.

See the [current targeted plan](VIA_PAIR_SEARCH.md) and [paired photo locator](VIA_PAIR_TESTS.html).

## Prior v0.9.5 state — current results above supersede its counts

### v0.9.5 corrections

| Via | Current association | Schematic effect |
|---|---|---|
| V114 | U2.T2 / native pin 2, GND; explicitly not Q8.T2 | Confirms existing U2 ground; resolves the old via conflict without grounding Q8 supply |
| V125, V126 | C5 negative terminal / pad 2, GND | Confirms existing capacitor ground |
| V127 | GND and LED1 | Ground the photo-selected common pair BL/BR / stock pins 3/4; internal LED mapping remains provisional |
| V011–V014 | Q1.L, user-reported VDD | Report recorded; distinguish regulated V064 from motor-supply V001 before assigning a rail |

The LED pair selection uses IMG_2432: the joined pair lies opposite the two resistor-fed terminals. The user's report establishes GND/component association; selecting the physical pair is a photo inference. Q1.L remains separate from R43.2/V015, as explicitly requested earlier. V114 supplies no evidence for the Q8 source rail, whose existing connection remains a hypothesis.

KiCad 10.0.5 validates 88 modeled net partitions. ERC has 50 findings: 37 open pins, eight isolated labels and five power-drive findings. The former LED input-drive finding is resolved by its ground connection. There are still six GPIOs with unknown onward destinations. All 26 original photo checksums pass.

The [targeted via-pair plan](VIA_PAIR_SEARCH.md) now has 29 local candidate groups / 33 non-rail sites, including the unresolved Q1 rail choice and one empty U6A option. Eleven proposed first-round readings remain unmeasured. [Paired photo locator](VIA_PAIR_TESTS.html).

## Historical v0.9.4 state — superseded where corrected above

120 distinct via IDs reviewed; 120 active sites / 127 stable IDs. PIC15/RC4 connects through V022-V016 to MX512H INA pin2; PIC16/RC5 connects through V023-V019 to INB pin3. Six GPIO onward destinations remain unknown. V011-V014 reach Q1.L. The user explicitly removes the old Q1.L-R43.2 photo-derived connection; R43.2 still reaches V015. Seven IDs remain unmentioned, some already photo-matched. V114 net remains the only held via conflict.

## v0.9.4 motor and Q1 corrections

| Sites | Confirmed connection | Native change |
|---|---|---|
| V016 - V022 | U5.2 INA - U4.15 RC4 | MOTOR_INA now driven by PIC |
| V019 - V023 | U5.3 INB - U4.16 RC5 | MOTOR_INB now driven by PIC |
| V011-V014 | Q1.L, explicitly not R43.2 | Withdraw old Q1.L-R43.2 link |
| V015 | R43.2 | Withdraw inferred Q1.L association |

The user explicitly answered “Remove Q1.L–R43.2 connection”. Historical fragment V_Q1_LEFT is preserved as rejected evidence, with the other 28 original fragments retained electrically. Q1.L and R43.2 now each have a known local via but unknown onward destination. This adds two open component pads while resolving two PIC pads: 37 open pads remain, of which six are PIC GPIOs.

## Prior v0.9.3 corrections

| Via | User-confirmed local destination | Remaining uncertainty |
|---|---|---|
| V036 | U4 pin5 / RA3 | Onward destination unknown |
| V037 | U4 pin6 / RA4 | Onward destination unknown |
| V039 | U4 pin7 / RA5 | Onward destination unknown |
| V047 | U4 pin11 / RC0 | Onward destination unknown |
| V049 | U4 pin13 / RC2 | Onward destination unknown |
| V072 | TP6.1; explicitly not R22.2 | Other RX_A_FILTER branches remain inferred |
| V079, V080 | SGM8542 U3 pin5 | Other receiver topology remains partly inferred |

These are local endpoint confirmations; no new component-to-component net merges. All eight unresolved GPIO onward routes now have identified local vias. TP6 and U3.5 remain separate across C18. Seven previously unmentioned IDs are now reviewed, leaving nine.

## Prior v0.9.2 corrections

| Via | Updated destination | Qualification |
|---|---|---|
| V075 | Q7 | Terminal not specified; Q7.R and former R19.2 association are photo candidates only |
| V077 | C19.2 / R29.2 / GND | User explicitly confirms junction GND; R29 opposite PIC3 end, C19 upper photo pad selected |
| V078 | C17.2 / GND | Component added to earlier GND report |
| V083 | C40.2 / GND | Component added to earlier GND report |
| V091 | R11.1 / H_TUNE_5 | Free upper pad photo-selected; onward GPIO unknown |
| V097 | R16.1 / H_TUNE_4 | Free upper pad photo-selected; onward GPIO unknown |
| V102 | R15.1 / H_TUNE_3 | Free upper pad photo-selected; onward GPIO unknown |
| V108 | R14.1 / H_TUNE_2 | Free upper pad photo-selected; onward GPIO unknown |
| V112 | C8.2 / GND | Component added to earlier GND report |
| V113, V115 | Q8.B2 / pin5 / GND | Centre-pad clarification replaces incorrect outer B1/B3 annotations |
| V114 | Q8.T2 / pin2; net unresolved | Follow-up confirms opposite-side second pin; GND versus supply not answered |
| V118 | C7.2 / GND | Component added to earlier GND report |
| V119 | C9.2; GND photo/model inference | User identifies component only |
| V117, V120, V121, V122, V124 | Rejected; not vias | Stable IDs retained; excluded from active markers |

Two native pad assignments change: C19.2 and R29.2 become GND. R29.1 stays on PIC3/TP7/R28, and the independent U3.5/C18.1 fragment remains. Q8 centre pin5 was already grounded in the schematic; its via annotations are corrected without grounding the outer drains or opposite source. V114 is the only held site conflict.

## Prior v0.9.1 corrections

| Via | Current association | Evidence qualification |
|---|---|---|
| V006 | C33.2 / GND | User C33; earlier GND report; pad photo-selected |
| V007 | C34.2 / GND | User C34; earlier GND report; pad photo-selected |
| V011-V014 | Not R43.2; destination unresolved | Incorrect Q1.L/R43.2 island association removed |
| V015 | R43.2; local Q1.L fragment retained | User lower pad2; Q1 connection from original visual fragment |
| V017 | R42.1 / R44.1 / V017_CONTROL | User explicitly R42.1 and R44; free R44 pad1 photo-selected; old R42-to-ANT2 guess withdrawn |
| V018 | C35.2 / GND | User C35; earlier GND report; pad photo-selected |
| V020 | R40.1 / ICSP_DAT | User R40; free pad1 photo-selected; existing local ICSP node |
| V029 | C25.2 / C26.2 / GND | User capacitor pair; earlier GND report; return pads photo-selected |
| V033 | Rejected, not a via | User recognition correction; ID preserved |
| V034 | R3.1 / H_VBAT | User VDD/R3; previous explicit common net with V001/MX512H pin4 |
| V040 | C28.2 / GND | User C28; earlier GND report; pad photo-selected |
| V059, V061 | L2.1 / H_VBAT | User L2; earlier motor supply report; source/right pad photo-selected |
| V060 | Q2.L / GND | User Q2; earlier GND report; local pad photo-selected |
| V065 | C2.2 / GND | User C2; earlier GND report; return pad photo-selected |
| V068 | C37.2 / C36.2 / GND | User pair; earlier GND report; return pads photo-selected |
| V072 | Not R22.2; superseded by v0.9.3 TP6 assignment | Prior independent receiver-bias hypothesis still unverified |
| V073 | GND only | User explicitly resolves duplicate; no R19 ground merge |

Only two component-pad net assignments change in this batch: R42.1 and R44.1 join `V017_CONTROL`. The other entries correct via metadata or corroborate existing qualified pad assignments. The original `V_Q1_LEFT` fragment (Q1.L to R43.2) remains; the user corrected the via location, not this independent local trace. Superseded in v0.9.2: V075 now identifies Q7; exact terminal and possible R19 continuation remain photo candidates.

## Prior v0.9 endpoint corrections retained

| Pad | Earlier net | Current net | Basis |
|---|---|---|---|
| C27.1 | Open | H_VBAT | C27 photo left pad to V003/V004; user ties these to MX512H pin4 motor VDD. |
| C27.2 | Open | H_GND | C27 photo right pad to V008/V009/V010 user GND. |
| R1.1 | Open | H_VDD | DNP free pads via V064 to board VDD test point / U1 output. This is distinct from MX512H pin4 motor VDD. |
| C3.1 | Open | H_VDD | DNP free pads via V064 to board VDD test point / U1 output. This is distinct from MX512H pin4 motor VDD. |
| R2.1 | Open | H_GND | DNP free pads lie on front ground copper shared with V057/V058. |
| C4.1 | Open | H_GND | DNP free pads lie on front ground copper shared with V057/V058. |
| R37.1 | H_VDD | AUX_FEED_V063 | User V063 joins R37 and R39; photo identifies their lower ends. Withdraw conflicting H_VDD and GND guesses. Remote feed unknown. |
| R39.2 | H_GND | AUX_FEED_V063 | User V063 joins R37 and R39; photo identifies their lower ends. Withdraw conflicting H_VDD and GND guesses. Remote feed unknown. |
| R10.2 | H_RF_MONITOR | H_GND | R10 free end visibly joins V116, user GND. |
| R32.1 | H_PIR_SIG | H_GND | R32 photo upper pad to V024, user GND; withdraw earlier PIR-signal guess. |
| Q9.R | Open | H_GND | DNP Q9 lower-right pad to V021, user GND; pad mapping R=stock pin2. |
| U4.12 | Open | PIC_RC1_VREF | PIC pin12 visible trace reaches V053, the VREF-labelled board pad. Remote continuation/function remains unknown. |
| VREF.1 | Open | PIC_RC1_VREF | PIC pin12 visible trace reaches V053, the VREF-labelled board pad. Remote continuation/function remains unknown. |
| Q11.L | H_ANT_A | H_GND | First four transistor L pads visibly join V089/V094/V099/V104, user GND. Q3 L joins the same front copper by photo inference. Candidate emitter functions not independently established. |
| Q6.L | H_ANT_A | H_GND | First four transistor L pads visibly join V089/V094/V099/V104, user GND. Q3 L joins the same front copper by photo inference. Candidate emitter functions not independently established. |
| Q5.L | H_ANT_A | H_GND | First four transistor L pads visibly join V089/V094/V099/V104, user GND. Q3 L joins the same front copper by photo inference. Candidate emitter functions not independently established. |
| Q4.L | H_ANT_A | H_GND | First four transistor L pads visibly join V089/V094/V099/V104, user GND. Q3 L joins the same front copper by photo inference. Candidate emitter functions not independently established. |
| Q3.L | H_ANT_A | H_GND | First four transistor L pads visibly join V089/V094/V099/V104, user GND. Q3 L joins the same front copper by photo inference. Candidate emitter functions not independently established. |
| C47.1 | H_ANT_B | H_GND | Front lower tuning-capacitor common band joins V087/V088 user GND. Withdraw antenna B assignment of these pads; midpoint antenna links remain unknown. |
| C44.1 | H_ANT_B | H_GND | Front lower tuning-capacitor common band joins V087/V088 user GND. Withdraw antenna B assignment of these pads; midpoint antenna links remain unknown. |
| C29.1 | H_ANT_B | H_GND | Front lower tuning-capacitor common band joins V087/V088 user GND. Withdraw antenna B assignment of these pads; midpoint antenna links remain unknown. |
| C14.1 | H_ANT_B | H_GND | Front lower tuning-capacitor common band joins V087/V088 user GND. Withdraw antenna B assignment of these pads; midpoint antenna links remain unknown. |
| C11.1 | H_ANT_B | H_GND | Front lower tuning-capacitor common band joins V087/V088 user GND. Withdraw antenna B assignment of these pads; midpoint antenna links remain unknown. |
| C48.1 | H_ANT_B | H_GND | Rear tuning-capacitor ground-side lands share copper around V093/V096/V101/V105. These are user-GND sites; opposite lands retain the local front/rear midpoint grouping. |
| C45.1 | H_ANT_B | H_GND | Rear tuning-capacitor ground-side lands share copper around V093/V096/V101/V105. These are user-GND sites; opposite lands retain the local front/rear midpoint grouping. |
| C38.1 | H_ANT_B | H_GND | Rear tuning-capacitor ground-side lands share copper around V093/V096/V101/V105. These are user-GND sites; opposite lands retain the local front/rear midpoint grouping. |
| C15.1 | H_ANT_B | H_GND | Rear tuning-capacitor ground-side lands share copper around V093/V096/V101/V105. These are user-GND sites; opposite lands retain the local front/rear midpoint grouping. |
| C12.1 | H_ANT_B | H_GND | Rear tuning-capacitor ground-side lands share copper around V093/V096/V101/V105. These are user-GND sites; opposite lands retain the local front/rear midpoint grouping. |

## Reports held for clarification

- Resolved by user: V025=GND; V026=PIC21/RB0. The onward RB0 destination is still unknown.
- Resolved by user: V073 is GND only. R19/V075 remains a photo association, not user-confirmed.
- Resolved in v0.9.2: V113/V115 reach centre Q8.B2/pin5 GND. The earlier outer-pad annotation was wrong. V114 opposite T2/pin2 net remains unresolved.

## What a component association establishes

V063 establishes a local R37/R39 junction, not its source voltage. V070/R18 and V071/R21 do not establish that their remote sides share a supply or bias node. V076 corroborates the opposite R22 ground return. V067 reaches empty U6A; no fitted chip is missing there. V082 associates D3 but does not settle its exact terminal. V011-V014 are explicitly not connected to R43.2; their previous Q1.L/R43.2 annotation was incorrect. V015 is the corrected R43.2 association.

V090/C46/C47, V095/C43/C44, V100/C16/C29, V103/C13/C14 and V107/C10/C11 corroborate local tuning junctions. Their rear capacitor partners are photo-associated. Ground returns invalidate the old complete antenna series-branch assumption; onward midpoint-to-antenna links still require tracing.

MX512H **pin4 VDD** is the motor supply net H_VBAT. Its **pin1 VCC** and the regulated board VDD test point are on the separate H_VDD model net. V064 joins the latter via the R1/C3 option pads.

## IDs not yet mentioned across the user reviews

V016, V019, V027, V028, V030, V035, V036, V037, V038, V039, V042, V047, V049, V053, V079, V080.

These are not all unresolved: V027/V028/V030/V038/V042 already had local photo matches, and V035/V053 now have additional local associations. No need to recheck every ground site. The interactive viewer distinguishes user-reported assignment, photo-local assignment, unresolved report, held conflict and rejected detection.
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

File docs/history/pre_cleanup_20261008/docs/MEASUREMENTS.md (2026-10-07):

# Verification status

No electrical measurements were supplied or performed. The current revision intentionally advances using photographic evidence, manufacturer datasheets and explicitly labeled hypotheses, as requested by the user.

The old broad continuity worksheet is historical material under `reference/v01/`. It is not a prerequisite for using or reviewing the new single-sheet drawing. See RECONSTRUCTION.md for the remaining specific uncertainties and their alternatives.

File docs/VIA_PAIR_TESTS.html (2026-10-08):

# Find the hidden connections, one useful pair at a time

GPIO batch complete. PIC12/RC1 → V053 → V070 → R18 is confirmed. V053 is NOT connected to VREF; PIC21/RB0 → V026 → VREF (TP104) remains separate. PIC13/RC2 → TP3 and V067 → J3 pin 1/PIR supply are also recorded. The photos below locate the completed V053–V070 result; no repeat reading is requested.

The current search pool contains 9 non-rail via sites in 8 local groups, with V067/U6A now excluded because its PIR supply connection is known. A known component at a via is different from knowing its remote destination.

Before measuring: disconnect the battery and programmer. Short the probes, then check the already known V022–V016 pair once as your contact baseline. Report actual ohms, kohms, OL or changing readings. A beep or a resistor path is not enough. Recheck near-zero hits with probes reversed.

Test PreviousNextPhoto Zoom Centre both points

A = fixed probe; B = moving probe. The dashed line below the overview labels is a proposed measurement, not a copper trace. Rear is mirrored to match front; check board landmarks. Drag each close-up to inspect it.

## Recorded result

ReadingReversed probes, if lowObservation

Entries are retained locally when your browser permits it. Use the reply box below to copy them into chat; nothing is submitted automatically.

## Completed connection

F1 is confirmed. E1 V053–VREF was rejected. D1 V049–V070 remains contact-dependent 200–300 kΩ. D2 was not measured and has been withdrawn; it is not a recorded negative.

Test | Pair | Probe B destination | Reading

## Result record

Shorted probes / known-pair baseline

Copy this text into chat. Unmeasured rows stay blank.

Select reply text

Why these tests were chosen, and what changed

We will merge only measured direct connections, keep rejected pairs, and choose the next tests from the remaining groups. Even a final pair suggested by elimination still needs a measurement. Very low resistance can include a zero-ohm link or inductor; this recovers electrical connectivity, not exact inner-layer geometry.

Plan based on schematic v0.9.9 and your via review of 8 October 2026. Native v0.9.8 includes RC1–R18, RC2–TP3, RB0–VREF and V067–J3.1. Q7 operating role and its local circuit reconstruction remain qualified.

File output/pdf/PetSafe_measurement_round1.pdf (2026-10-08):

# U6: your measurements recorded

C2NM supports S-812C33AMC, a 3.3 V regulator. Board remains unpowered for resistance tests.

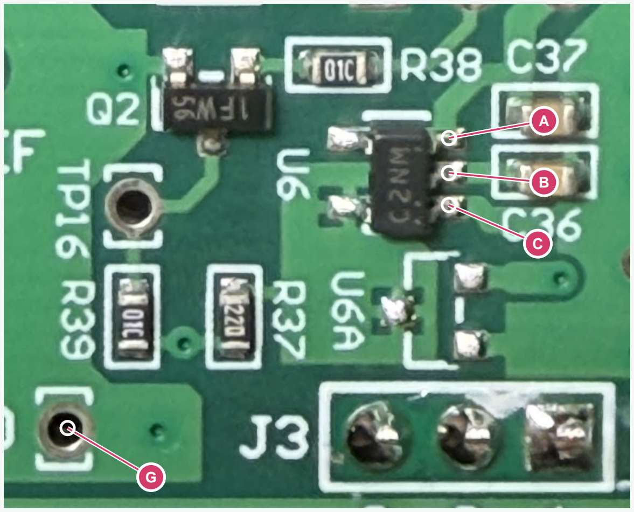
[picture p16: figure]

Original photo pixels; vector callouts only. Board orientation is unchanged. Candidate identities are unconfirmed.
PetSafe 100-1339 R03 A | 2026-10-08 | v0.5 measurement plan

Meter setup

Use resistance / ohms. First short the probes together and note the lead resistance.

Keep the black probe on G, the plated hole labelled GND on the PCB. Touch only the circled solder pad with the red probe.
Your readings; shorted tips = 0.5 ohm

G to A = 4.2 kohms (reported)

G to B = 34 kohms (reported)

G to C = 2.7 ohms (reported)

Wait for each reading to settle. Report changing readings too. If unclear, reverse the probes and give both readings.

A beep alone is not enough: a 22-ohm resistor can also trigger continuity. A direct copper connection should be close to your shorted-probe reading.

A = original R1 / upper-right lead; B = R2 / middle-right; C = R3 / lower-right.
S-812C33AMC predicts C = pin 1 / GND, B = pin 2 / VIN, A = pin 3 / VOUT. Ground is supported, not proven.

# Q8 and C6: measured results

D-E and S-G read 2 ohms. E-F reads 400 kohms: the proposed direct C6 output tie is withdrawn.

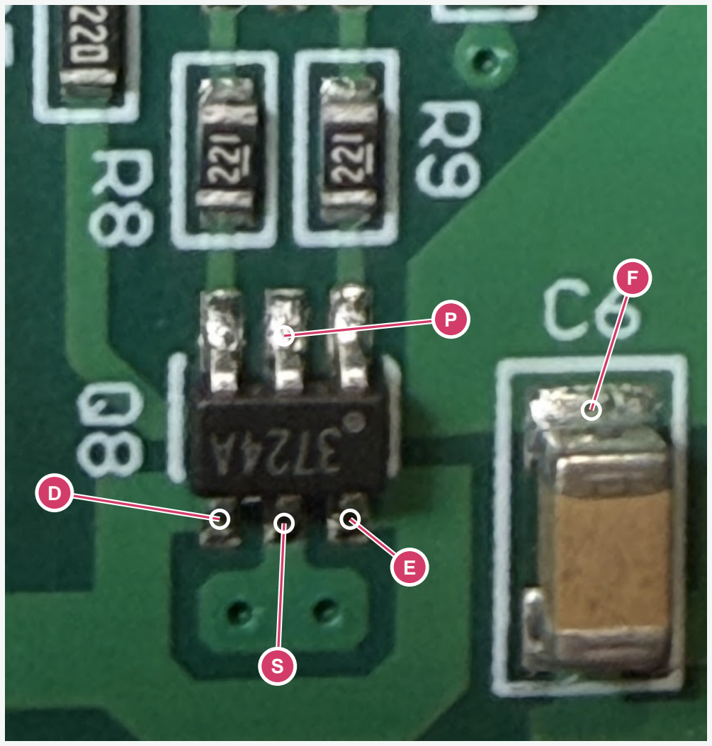
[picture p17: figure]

Original photo pixels; vector callouts only. Board orientation is unchanged. Candidate identities are unconfirmed.
PetSafe 100-1339 R03 A | 2026-10-08 | v0.5 measurement plan

Recorded results

D to E = 2 ohms. This supports joined drain pads.

S to G = 2 ohms. This supports the N-channel source returning to ground.

E to F = 400 kohms. F is not directly joined to the output. That proposed wire is removed.
C6 follow-up results

F to P = 10 ohms (reported)

P is Q8's upper middle solder pad, the candidate P-channel source / supply. F is the upper end of C6. F to G = 300 kohms (reported)

G is the same ground hole on page 1. F appears supply-related. The 10-ohm path is not yet established as direct copper.

No more measurements requested in this round. C6.1 remains unresolved; contact or series resistance may explain the F-P reading.

C6 connection unresolved. The 400-kohm in-circuit result is not a measurement of a discrete resistor.

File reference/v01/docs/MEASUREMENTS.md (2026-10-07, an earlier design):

# First continuity pass — no modifications

Use `evidence/measurements_round1.csv` to record results. No measurements have been prefilled.

Remove all four AA cells and disconnect any external supply. Check that the board has discharged before using resistance/continuity mode. Do not use the meter's resistance mode on a powered circuit. No component removal is required for this batch.

Touch the probes together and record their resistance first. A direct copper connection should be stable and close to that value. A beep alone is not proof: resistors and semiconductor paths can also beep. Record a resistance, or OL; reverse probes when a reading is ambiguous or polarity-dependent. An in-circuit result of several ohms or more is NOT automatically a same-net connection.

## Small first batch

M01–M08 establish ground and supply domains. M09–M13 verify the programming header. M14–M17 map the motor outputs and the two control inputs. Stop there initially if time is limited. M18–M23 extend the map into the analogue supply and sensor interface.

Use `photos/U4_probe_orientation.png` and `photos/U5_probe_orientation.png`. Pin names in a semiconductor datasheet describe the IC, not a confirmed connection elsewhere on this board.

For M16/M17, hold one fine probe on U5's indicated input and sweep the listed PIC pins carefully without bridging neighbours. Record the matching PIC pin and resistance. If there is no near-zero match, report that rather than assuming a connection; a series resistor or intermediate circuit may be present.

## What is deliberately deferred

Do not cut traces, lift IC pins, reprogram the PIC, connect ESP32 outputs, switch battery chemistry or remove the RFID capacitors for this continuity pass. These actions do not help identify the first hidden connections.

The next analogue pass will trace one complete switched-capacitor branch (Q3 with C10/C12/C11), then the two op-amp feedback/input networks. It will use the already established ground/supply nodes to avoid a large blind all-pairs search.

## Values versus connectivity

A connectivity-complete schematic can still contain UNKNOWN capacitor values. A multimeter can establish which pads are joined; it generally cannot uniquely identify an unmarked capacitor value inside a connected filter or resonant network. Later LCR measurements, and sometimes lifting one end, may be needed. Do not infer capacitance, dielectric or voltage rating from physical size.

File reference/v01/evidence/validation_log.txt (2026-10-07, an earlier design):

{
  "scope": "STRUCTURAL_AND_MODEL_CHECKS_ONLY",
  "native_kicad_available": false,
  "native_kicad_open_test": "NOT_RUN",
  "erc": "NOT_RUN",
  "physical_continuity_checks": "NONE_RECEIVED",
  "sheet_results": [
    {
      "file": "PetSafe_1001339.kicad_sch",
      "symbol_count": 0,
      "parse": "PASS",
      "symbol_definitions_and_pins": "PASS",
      "no_nc_flags": "PASS"
    },
    {
      "file": "control.kicad_sch",
      "symbol_count": 29,
      "parse": "PASS",
      "symbol_definitions_and_pins": "PASS",
      "no_nc_flags": "PASS"
    },
    {
      "file": "motor.kicad_sch",
      "symbol_count": 13,
      "parse": "PASS",
      "symbol_definitions_and_pins": "PASS",
      "no_nc_flags": "PASS"
    },
    {
      "file": "power.kicad_sch",
      "symbol_count": 25,
      "parse": "PASS",
      "symbol_definitions_and_pins": "PASS",
      "no_nc_flags": "PASS"
    },
    {
      "file": "receiver.kicad_sch",
      "symbol_count": 33,
      "parse": "PASS",
      "symbol_definitions_and_pins": "PASS",
      "no_nc_flags": "PASS"
    },
    {
      "file": "rf_drive.kicad_sch",
      "symbol_count": 22,
      "parse": "PASS",
      "symbol_definitions_and_pins": "PASS",
      "no_nc_flags": "PASS"
    },
    {
      "file": "tuning.kicad_sch",
      "symbol_count": 28,
      "parse": "PASS",
      "symbol_definitions_and_pins": "PASS",
      "no_nc_flags": "PASS"
    }
  ],
  "catalog_entries": 150,
  "local_net_fragments": 29,
  "electrically_measured_nets": 0,
  "unresolved_pads": 290
}

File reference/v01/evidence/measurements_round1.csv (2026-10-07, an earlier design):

id | from_point | to_point_or_search | method | purpose | expectation | result_ohm | matched_pin | notes
M01 | PCB GND | U4 pin 8 | resistance | Ground reference | UNVERIFIED — record actual reading
M02 | PCB GND | U4 pin 19 | resistance | Second PIC ground | UNVERIFIED — record actual reading
M03 | PCB GND | U5 pin 6 | resistance | Driver ground | UNVERIFIED — record actual reading
M04 | U5 pin 6 | U5 pin 7 | resistance | Driver ground pair | UNVERIFIED — record actual reading
M04b | PCB GND (central pad) | GND pad near C5 at RF end | resistance | Check the two separately captured physical ground pads | UNVERIFIED — record actual reading
M05 | PCB GND | BATTERY minus pad | resistance | Determine whether a protection element separates raw battery negative | UNVERIFIED — record actual reading
M06 | PCB VDD test point | U4 pin 20 | resistance | PIC supply domain | UNVERIFIED — record actual reading
M07 | PCB VDD test point | U5 pin 1 | resistance | Check logic-domain sharing; do not confuse U5 VCC and VDD | UNVERIFIED — record actual reading
M08 | BATTERY plus pad | U5 pin 4 | resistance | Motor supply route | UNVERIFIED — record actual reading
M09 | J1 pad labelled CLK | U4 pin 27 | resistance | Verify programming-header net, not a presumed UART | UNVERIFIED — record actual reading
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

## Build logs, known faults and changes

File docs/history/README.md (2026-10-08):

# Investigation history

These records preserve earlier reasoning and its provenance. They are **not current measurement requests or current circuit truth**. Use [the completion checklist](../FINISHING_CHECKLIST.html), [current circuit interpretation](../RECONSTRUCTION.md) and [current measurements](../MEASUREMENTS.md).

- [Pre-cleanup chronological reconstruction](pre_cleanup_20261008/docs/RECONSTRUCTION.md), [source/event register](pre_cleanup_20261008/docs/SOURCES.md), [via history](pre_cleanup_20261008/docs/VIA_REVIEW_RESULTS.md), and [old status JSON](pre_cleanup_20261008/evidence/completion_status.json). Their original relative links were relative to the project before archiving.
- Original supplied capture: `reference/v01/`; earlier authoring: `reference/v02/` at repository root.
- Dated `evidence/v0*_net_changes.json` and `evidence/v0*_verification.json` at repository root are provenance. Earlier verification reports describe their own revision; the latest electrical suite is `tools/verify_v099_review.py`.
- Earlier U6/Q8 reports document why the WN23 supervisor and 372A interpretations were superseded by C2NM and 3724A. They also contain temporary wiring conflicts later resolved.
- Older round-1/round-2 measurement PDFs are historical prompts. Do not repeat a test just because it appears there. Current via-pair results say the GPIO batch is complete.

Key superseded claims: no measurements supplied; two/eight GPIO pads still open; Q1 as MMBT3904; C6 tied directly to Q8 output; V114 on Q8; Q1.L joined to R43.2; raw battery merged with post-Q1 motor supply. Each is corrected in the current files while its original reasoning remains auditable.

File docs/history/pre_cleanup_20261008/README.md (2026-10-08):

# PetSafe PCB reverse engineering - v0.9.9

One editable **A2 KiCad 10 sheet**, with all 150 main-board catalog entries grouped into functional blocks. Wires connect parts within blocks; named nets connect blocks. This revision uses the installed **KiCad 10.0.5** and **KiCad MCP Server**, with **20 unmodified stock symbol definitions and four explicitly authorized datasheet symbols**.

## Current via review (v0.9.9)

123 IDs reviewed; 120 active sites. All PIC pads have modeled local destinations. The battery-path correction separates BATTERY+ from **VSYS**, the user-approved name for Q1 output / U5 pin4 / L1 and L2 supply inputs. The PCB's VDD test point stays on a separate regulated rail. V035 now joins VREF; V042 confirms VDD. Q1 is a stock PMOS symbol with the marking-backed FMOS3401A candidate, replacing the unsupported NPN guess. Read the [current rail and via evidence](docs/VIA_REVIEW_RESULTS.md).

## Measurement status

The GPIO batch is complete. The [paired photo locator](docs/VIA_PAIR_TESTS.html) shows the confirmed RC1-R18 result, with no repeat test queued. [Search rationale and results](docs/VIA_PAIR_SEARCH.md) preserve the earlier negative and resistive readings. The remaining 9 sites in 8 local groups are not eight proven missing connections.

## Corrected markings and measured evidence (2026-10-08)

[U6 / Q8 marking update](docs/U6_Q8_MARKING_UPDATE.md) identifies **U6 C2NM as a strong S-812C33AMC 3.3 V regulator candidate** and **Q8 3724A as a complementary N/P MOSFET pair, with SIL3724A as the datasheet candidate**. This replaces the earlier misread WN23/372A hypotheses. U6 ground, joined Q8 outer pads and the source-return candidate are supported by earlier resistance readings; the centre-pad correction now resolves V113/V115, and V114 is now corrected to U2.T2 GND; the proposed C6 output tie was refuted and removed; other routes and actual rail voltage remain unverified. U1/U5/U6/Q8 now use MCP-authored datasheet symbols with standard KiCad footprints. D3 uses a BAV99 candidate (A7); D2 is an unidentified 4P stock placeholder with its old clamp ties withdrawn. R41 is 330 ohm from the user-read 331 marking; D4/D5 use SD05 TVS candidates and D6 uses a provisional MMSZ5228BS 3.9 V Zener (2.4 V alternative).

## Open the result

- `docs/VIA_REVIEW.html`: interactive front/rear comparison, 120 active sites / 127 stable IDs; 123 user-reviewed IDs including corrections, conflicts and component cross-checks.
- `index.html`: zoomable offline viewer, searchable inventory and photo links.
- `schematic/PetSafe_1001339.kicad_pro`: open the single native schematic in KiCad 10.
- `output/pdf/PetSafe_single_sheet.pdf`: one-page vector drawing.
- `output/pdf/PetSafe_PIC_GPIO_pin_map.pdf`: updated close-up with all 28 PIC pins numbered and no open GPIO pads in the model; V035/RA2 reaches VREF and V042/PIC20 reaches VDD.
- `output/pdf/PetSafe_measurement_round1.pdf`: annotated photos, recorded U6/Q8 readings and targeted C6 follow-up.
- `docs/LIBRARIES_AND_ALTERNATIVES.md`: library choices, datasheet symbol provenance, footprints and Western alternatives.
- `docs/RECONSTRUCTION.md`: circuit hypotheses, identifications and calculations.
- `docs/SOURCES.md`: manufacturer documents and photograph provenance.

All symbol definitions are embedded, so the drawing is self-contained. Standard KiCad 10 libraries and the portable project-local `PetSafe_Datasheet.kicad_sym` support editing and updating. The previous custom library is archived in `reference/v02/` and is not registered in the active project.

## What is complete and what remains provisional

All 150 catalog entries and 352 photographed pads are retained. Of 29 original photo fragments, 28 remain electrically joined; Q1.L-R43.2 was explicitly withdrawn by the user. The native KiCad 10.0.5 netlist matches all 83 authored net partitions. All 26 original photos retain their checksums. The schematic is a functional reconstruction from photographs and datasheets, not a continuity-verified production design.

U1 (probable S-1200B45) and U5 (MX512H) now use datasheet-derived symbols created through MCP at the user's request. Their standard footprints are SOT-23-5 and SOIC-8 3.9 x 4.9 mm / 1.27 mm pitch. No custom footprint was needed. U6 and Q8 now have candidate datasheet pin maps, including both Q8 MOSFET units on this sheet. U3 uses KiCad's generic dual op-amp with its actual SGM8542XS value and pinout.

Western alternatives are documented separately: **MCP6002-I/SN** for SGM8542 and **DRV8212PDSGR** for an MX512H redesign. The motor driver has a different package and pinout; it has not been substituted into the reconstructed board. Both alternatives have standard KiCad symbols and footprints. Pin-compatible does not mean electrically interchangeable.

ERC retains **36 findings**: 28 unconnected pins, three isolated pin labels and five undriven power checks. No artificial no-connect or power flags hide missing evidence. Open pads comprise 18 on DNP entries and 10 populated-entry pads. No PIC pad remains open; existing local nets can still have uncertain onward routes or inferred branches.

Read the [complete status report](output/pdf/PetSafe_completion_status.pdf) for every remaining area and all 28 PIC pins, and the [via review findings](docs/VIA_REVIEW_RESULTS.md) for each changed endpoint. **Q8 V113/V115 are resolved as centre pin5 GND. V114 is corrected to U2.T2/pin2 GND; it is not Q8.** V025=GND and V026=PIC21/RB0 are now corrected. V073 is now GND only; its duplicate R19 report is resolved. No further symbol files are missing for the chosen candidates. PIR daughterboard internals and a routed PCB remain outside this main-board revision.

## Repository contents

- `input/PetSafe_KiCad_RE_v01.zip`: untouched user archive.
- `reference/v01/`, `reference/v02/`: historical files and retired custom-symbol workflow.
- `photos/originals/`: unchanged originals; `photo-atlas-v01.html` retains the original atlas.
- `evidence/reconstruction.json`: observed values, proposed circuit and library choices.
- `evidence/pin_crosswalk.json`: photographed pad IDs mapped to stock library numbers.
- `evidence/library_placements.json`: MCP placement requests updated for the candidate symbols and five extra units. Create/register their library first using `evidence/datasheet_symbol_authoring.json`.
- `tools/templates/mcp_standard_placements.kicad_sch`: actual MCP placement result.
- `evidence/validation.json`: native connectivity check and explicit limitations.
- `output/`: netlist, ERC, SVG and PDF exports.

This remains a separate local Git repository on `codex/single-sheet-reconstruction`; no remote repository has been published. Instructions in the imported ZIP are historical evidence. The user's current single-sheet, calculated-guess, standard-library and KiCad 10 preferences govern the project.

## Export and validate

```powershell
./tools/build.ps1
```

The script finds the installed KiCad 10 under LocalAppData or Program Files and rejects older versions. It exports and validates the current native schematic without regenerating over manual edits. There is no fallback to the old portable KiCad 9 cache.

To explicitly recreate the checked-in routing around the saved MCP placement template:

```powershell
./tools/build.ps1 -Regenerate -Python 'C:/Users/lukin/Documents/VS.Code.Projects/KiCAD-MCP-Server/.venv/Scripts/python.exe'
```

Regeneration requires `sexpdata` and the installed MCP server's formatter. It overwrites manual native edits; transfer those changes to the template/routing source first. `tools/prepare_library_rebuild.py` records the original conversion manifest from the archived v0.2 topology; it does not create symbol artwork. For additional parts or changed library definitions, use MCP library search/placement and update the saved template and crosswalk before rerouting.

## v0.6 completion audit

126 stock footprints were assigned through KiCad MCP; 147 of 150 catalog entries now have footprints. Photo-based family choices carry separate confidence and evidence properties. C5, S1 and LED1 still need dimensional/pad details. Connector and test-pad assignments remain approximate. All 38 fitted resistor nominal values are recovered, including R29/R44 = 15 kohm from visible 18C markings. No new copper connections were assumed.

The v0.6 round requested D2 diode-mode readings, C5 sleeve text/dimensions and one resistor body measurement. C5's value and the R8/C11 body measurements are now recorded in v0.7; do not repeat those requests. See [the current finishing checklist](docs/FINISHING_CHECKLIST.html). The user has an LCR meter and multimeter; 44 fitted capacitor values remain unknown or estimated.

## v0.7 user measurements and PIC tracing

C5 is 470 uF / 16 V from the sleeve. C11 measures approximately 3.2 x 1.5 mm (1206); R8 approximately 1.6 x 0.77 mm (0603; user confirms both metal end caps included). The fitted resistor family is revised provisionally to 0603. Earlier v0.6 0805 inference is superseded. Five more PIC local connections were recovered from existing photos, leaving 14 open GPIO pads. See [annotated photo review](output/pdf/PetSafe_PIC_trace_review.pdf) and [pin-by-pin evidence](evidence/pic_trace_audit.json). C32 moved to the PIC VDD/VSS; C25/C39 are signal filters, R4 returns to RB3, TP17 belongs to RC7, D4/D5 attach to ICSP, and TP4/C41 are no longer tied to the antenna hypothesis. C26 VDD tie was withdrawn.

The subsequent three user photos are preserved in `photos/user/2026-10-08/`. The [complete GPIO map](output/pdf/PetSafe_PIC_GPIO_pin_map.pdf) highlights pins 3, 5, 6, 7, 11, 12, 13, 15, 16, 17, 21, 22, 23 and 25. Pin 1 is at the lower right beside the moulded dot in this photo. All 28 leads are visible despite the top of the plastic body being cropped. Existing local connections remain partly inferred; preparing this tracing request did not change schematic connectivity. Photo hashes, pin coordinates and the reply format are in `evidence/pic_gpio_request.json`.

## Historical v0.8 user GPIO mapping and rear-via audit

The user explicitly confirmed both multimeter and visual tracing: RA1/pin3 joins R28, R29 and TP7 (reported as RP7, interpreted from the photographed label); RC6/pin17 joins R13; RB1/pin22 joins TP2; RB2/pin23 joins TP1; RB4/pin25 joins TP4; RB5/pin26 to TP10 is corroborated. Numerical resistance values were not supplied. Resistor-pad identities use local photographs.

Conflicting old guesses are withdrawn: R13 is not assigned to RC7; TP2 is not assigned to the RF supply; TP1 is not assigned to LED common; R28/R29/TP7 are separated from other speculative bias/detector nets. TP1/TP2 sit beside their LED resistors and are connected with local wires. The user-defined pairwise connections do not confirm the entire receive/LED circuit.

Matching front and rear photos supports D4.2, D5.2 and C41.2 on main rear copper anchored by PIC VSS pins8/19. These three additions are photo-derived, not meter measurements. The [via viewer](docs/VIA_REVIEW.html) catalogues 127 rear-visible sites, with 10 individually matched front anchors; other front positions are approximate projections. Four layers are plausible but unverified. A rear clearance does not reveal the name or function of an internal net. Separate edge/antenna copper is not automatically GND.

At v0.8, nine GPIO destinations remained (superseded by the v0.9 status above): 12/RC1, 15/RC4, 16/RC5 and 21/RB0 reach vias; 5/RA3, 6/RA4, 7/RA5, 11/RC0 and 13/RC2 have no visible continuation. None is marked NC. Pin12's via is V053 in the viewer. The other three need exact via association before hidden destinations can be targeted. Historical mapping evidence: `evidence/pic_gpio_user_mapping.json`, `evidence/via_audit.json`, `evidence/v08_net_changes.json`.

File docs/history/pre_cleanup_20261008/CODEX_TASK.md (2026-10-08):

# Current project state - v0.9.9

Repo branch codex/single-sheet-reconstruction. Single A2 KiCad 10.0.5 sheet; MCP authoring. 150 references,155 units,352 physical pads;20 stock+4 custom definitions in use. Preserve user-owned schematic/PetSafe_1001339.kicad_pro and schematic/.history/.

Latest user corrections: battery+ feeds Q1 single pad (photo Q1.S/native3). Q1.L/native2 feeds U5.4 and V011-V014. Raw battery and post-Q1 supply were incorrectly merged in H_VBAT; fixed. Printed board labels now used: BATTERY (+), BATTERY (-), VDD, VREF, GND. Net BATTERY+ before Q1; battery negative on GND. User explicitly authorized naming post-Q1 supply VSYS and confirms L1/L2 connect to it. Existing supply-side pad1 selections remain photo-derived; do not short across L1/L2. VDD test point/TP103 remains regulated logic supply, distinct from VSYS; U5.1 uses VDD. TP14 battery+ connection visible in IMG_2438; R43.2/V015-TP14 user confirmed. Q1.L-R43.2 explicitly rejected and remains separate.

Q1 changed through MCP from MMBT3904 NPN to standard Transistor_FET:Q_PMOS_GSD, value FMOS3401A?. Formosa manufacturer PDF page5 explicitly lists R1A marking and pad roles G1/S2/D3. Photo R=G1,L=S2,single S=D3. Crosswalk numbers unchanged. Exact fitted maker unconfirmed; reverse-polarity-protection role is inference; gate operation not tested. Datasheet saved docs/datasheets/FMOS3401A_REV_C.pdf. No new custom symbol.

Latest via reports: V035-VREF joins prior PIC4/RA2-C39.1 local photo node to VREF (TP104). V042-VDD confirms prior PIC20/C32.1 supply. VREF also PIC21/RB0/V026 and R21.2/V071. Older R22.2/R23.2/R48.2 VREF bias branches remain hypotheses. V053/RC1 explicitly NOT VREF; user V053-V070 confirms RC1-R18.1. RC2/V049 goes TP3/R10.1 (R10 branch photo-derived). V067 joins J3.1/red PIR supply with prior U6A option association; U6A stays DNP. V082 reaches VDD/TP103, exact D3 terminal unknown; don't merge H_RX_VDD automatically. V017/R42.1/R44.1 reaches TP4/PIC25; R44 pad1/C41 associations photo-derived.

Preserve previous measured routes: RC4 V022-V016 U5.2; RC5 V023-V019 U5.3; RA3 V036-V108 R14; RA4 V037-V102 R15; RA5 V039-V097 R16; RC0 V047-V091 R11; RC6 R13. V064-V063 R37/R39 feed VDD; V064-V075 Q7 supply. V064-V070 11.2kohm supports R18+R19/Q7 topology but is not a direct tie. V049-V071 20kohm not direct. V049-V070 variable200-300kohm is inconclusive/contact-dependent, not OL. Seven capacitor-pair OL results retained; no broad pair sweep queued. V053-V071 rejected. Historical unmeasured D2 V070-V026 withdrawn, not negative. V114=U2.T2/native2GND not Q8; V113/115=Q8.B2/native5GND. V077=C19.2/R29.2GND. V072=TP6 not R22.2, separated from U3.5 across C18. V079/80=U3.5. V125/126 C5negative; V127 LEDcommon. Seven via artifacts33/50/117/120/121/122/124 retained as tombstones.

Validation:83 native/model partitions PASS;36 ERC=28open+3isolated labels+5power. Open pads10populated-entry/18DNP; zero PIC open pads. 28 original visual fragments retained; only V_Q1_LEFT withdrawn by explicit user instruction. All26 original photo hashes retained. No artificial flags. 147/150 footprints; C5/S1/LED1 exact geometry missing;44 fitted ceramic values and L1/L2 value/type unresolved. C5=470uF/16V; R8 fullbody0603, C11size1206. No fabrication-ready PCB or powered functional verification.

Latest scripts: tools/verify_v099_review.py and verify_via_pair_plan.py. Native source tools/templates/mcp_standard_placements.kicad_sch plus finish_library_rebuild.py, library_layout.json and reconstruction.json. Keep MCP fields, model, native and generated exports consistent. Build tools/build.ps1 -Regenerate with MCP venv Python and PYTHONUTF8=1. Bundled Python for PDF/status/review builders. PDF marker already run once this turn; output scope grew from3 to4 after user's V035/V042 follow-ups. Four final PDFs: sheet,status,PICmap,via-pair completed-result guide. Final renders inspected; saved visual review in v099_verification.json.

User review123 IDs/120active;4 unmentioned IDs already photo-ground-matched; remaining search pool9sites/8localgroups (not proven missingnet count). No pending measurement. Browser file:// automation previously policy-denied; no bypass. HTML source/data/JS validated; interaction not tested. User has docs/VIA_REVIEW.html open; refresh after updates. Current docs/VIA_REVIEW_RESULTS.md top section supersedes historical net names. Historical verification reports remain unchanged.

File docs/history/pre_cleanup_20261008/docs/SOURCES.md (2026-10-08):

# Source register

Manufacturer pinouts and application examples establish plausible functions, not photographed board connectivity. Accessed 2026-10-07 and 2026-10-08. Key PDFs are saved under `datasheets/`; SHA-256 checksums are in `evidence/datasheet_manifest.json`.

| Ref | Primary source | What it supports |
|---|---|---|
| U1 | [ABLIC S-1200 Rev.6.0](https://www.ablic.com/en/doc/datasheet/voltage_regulator/S1200_E.pdf), saved as S1200.pdf | Page 5 SOT-23-5 pins; page 23 marking PPE = S-1200B45-M5T1x with fourth-character lot code; typical regulator application. |
| U2 | [TI SN74LVC2G14](https://www.ti.com/lit/ds/symlink/sn74lvc2g14.pdf), saved as SN74LVC2G14.pdf | Page 3 DBV six-pin top view; ordering addendum lists C14R; dual Schmitt inverter function. |
| U3 | [SGMICRO SGM8541/8542/8544](https://www.sg-micro.com/rect/assets/537cce2c-8022-4ea6-97f4-6524851a35e8/SGM8541_SGM8542_SGM8544.pdf), saved as SGM8542.pdf | Dual op-amp pinout, 2.1-5.5 V supply, approximately 1.1 MHz gain-bandwidth. |
| U4 | [Microchip PIC16(L)F18855/75 DS40001802H](https://ww1.microchip.com/downloads/aemDocuments/documents/MCU08/ProductDocuments/DataSheets/PIC16%28L%29F18855-75-Data-Sheet-40001802H.pdf) | 28-pin package, power, oscillator and ICSP pins; configurable peripherals. |
| U5 | [Mixic MX512H Rev.1.2, manufacturer PDF mirrored by Chipdip](https://static.chipdip.ru/lib/203/DOC045203539.pdf), saved as MX512H.pdf | Eight-pin H-bridge map; separate logic/motor supplies; application circuit and at least 4.7 uF logic decoupling. Mirror filename/title is less useful than the MX512H content. |
| Q2 | [Nexperia BC847x datasheet](https://assets.nexperia.com/documents/data-sheet/BC847X_SER.pdf) | BC847B marking 1F plus manufacturing code; NPN B/E/C pinout. |
| Q7 | [Nexperia BC857C product information](https://www.nexperia.com/products/bipolar-transistors/general-purpose-and-low-vcesat-bipolar-transistors/single-bipolar-transistors/single-bipolar-transistors-100-v/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) | BC857C PNP with 3G marking plus manufacturing code. |
| Q1 | [Formosa FMOS3401A Rev.C](https://www.formosams.com/upload/product/Mosfets/FMOS3401A_REV_C.pdf), saved as FMOS3401A_REV_C.pdf | Page 5 explicitly lists R1A, 3401 and R1 markings and shows SOT-23 PMOS pin functions. Fits Q1 photo/power path; exact fitted maker unproved. Earlier MMBT3904 NPN hypothesis withdrawn in v0.9.9. |
| Tuning Qs | [Taitron semiconductor catalog](https://www.taitroncomponents.com/docs/2007%20Semiconductor%20Catalog.pdf) | Manufacturer table lists MMBTA55 / 2H / PNP. Exact fitted manufacturer is unknown. |
| Tuning alternative | [Nexperia PBSS5140T](https://assets.nexperia.com/documents/data-sheet/PBSS5140T.pdf) | Alternative PNP candidate; short-code identification remains ambiguous. |
| D1 | [Nexperia BAV99](https://assets.nexperia.com/documents/data-sheet/BAV99.pdf) | A7 marking, SOT23 dual-series diode and pin map. Current Diodes-branded BAV99 uses a different marking; do not use that to prove A7. |
| U6 withdrawn WN hypothesis | [Richtek RT9818](https://www.richtek.com/assets/product_file/RT9818/DS9818-12.pdf) | Voltage-supervisor family exists in a five-pin package. The WN association comes from historical Richtek marking material [mirrored here](https://www.rom.by/files/Richtek_Marking_Code.PDF); it is a lead, not an exact identification. |
| Native format | [KiCad schematic format](https://dev-docs.kicad.org/en/file-formats/sexpr-schematic/) | Embedded library, symbol units, wires, junctions, instances and labels. Native validation uses the installed 10.0.5 CLI. |

## Photographs used for circuit decisions

| Photo | Main content |
|---|---|
| IMG_2430 | U1/PPEK, regulator capacitors and empty option network |
| IMG_2431, IMG_2432 | U2/C14R, Q8/3724A (sharper follow-up), D1, RF drive resistors |
| IMG_2433, IMG_2442 | Repeated tuning cells and corresponding rear capacitor/via arrangement |
| IMG_2429, IMG_2434 | U3, feedback resistors, receiver components |
| IMG_2435 | U6, Q2 and daughterboard interface |
| IMG_2436, IMG_2437 | PIC, oscillator, programming area and battery-divider resistors |
| IMG_2438 | Motor driver, Q1 and pushbutton |
| IMG_2421 and overview photos | Separate PIR daughterboard context; its internal circuit is not reconstructed |

Full provenance remains in the original component model and photo manifest. Existing image registration is an approximate alignment, not a dimensioned board or a verified layer-stack reconstruction. No exact schematic of this board was adopted from an unrelated product.

## KiCad 10 rebuild and Western alternatives (2026-10-08)

- [KiCad MCP Server](https://github.com/mixelpixx/KiCAD-MCP-Server): already installed and connected. Used for standard-library searches, blank schematic creation, all 150 component placements, extra units, footprint inspection and PDF/SVG export.
- [Microchip MCP6001/2/4 DS20001733L](https://ww1.microchip.com/downloads/aemDocuments/documents/MSLD/ProductDocuments/DataSheets/MCP6001-1R-1U-2-4-1-MHz-Low-Power-Op-Amp-DS20001733L.pdf): page 1 pinout, pages 3-4 operating range, current, offset and bandwidth; SOIC package drawings. Saved as MCP6002.pdf.
- [TI DRV8212P Rev. A](https://www.ti.com/lit/ds/symlink/drv8212p.pdf): page 4 pin functions and exposed pad, page 5 recommended operating conditions, typical application and package drawing. Saved as DRV8212P.pdf. Preferred motor-driver redesign candidate because MX512H advertises a 3 A peak.
- [TI DRV8837 Rev. F](https://www.ti.com/lit/ds/symlink/drv8837.pdf): alternative lower-current driver; its separate supplies, sleep input and WSON package differ from MX512H. Saved as DRV8837.pdf.

Library existence and footprint names were verified against the user's installed KiCad 10 libraries through MCP, not inferred from online search results. See LIBRARIES_AND_ALTERNATIVES.md for compatibility boundaries.

## Historical U6 / Q8 investigation (superseded marking interpretation)

- [Richtek RT9818 DS9818-12](https://www.richtek.com/assets/product_file/RT9818/DS9818-12.pdf), saved as `RT9818.pdf`: page 3 top-view package numbering and reset/supply/NC functions.
- [Richtek marking information, mirrored by Jotrin](https://www.jotrin.it/userfiles/downloadfile/202003111510585708.pdf), saved as `Richtek_Marking_2008.pdf`: actual document MI-080418, printed C-39 / PDF page 39 maps RT9818A-33PB to WN-. This is the inspected local marking source for the follow-up.
- [ROHM BD45/BD46 Rev.007, mirrored by RS](https://docs.rs-online.com/7ad0/0900766b8161bcad.pdf), saved as `BD45_BD46.pdf`: page 1 five-pin map and page 3 WN = BD46281, 2.8 V, 100 ms CMOS detector. Secondary U6 candidate.
- [Diodes DMC3071LVT](https://www.diodes.com/datasheet/download/DMC3071LVT.pdf) and [DMC2053UVT](https://www.diodes.com/datasheet/download/DMC2053UVT.pdf), saved under those names: page 1 complementary-pair pin maps, TSOT26 packages and C71 / AR2 markings. Topology comparisons only.
- [SYNC Power SPP3437](https://www.syncpower.com/datasheet/SPP3437.pdf), saved as `SPP3437.pdf`: pages 1-2 show 37 marking but a single P-channel device with multiple drain pins, not the leading two-gate hypothesis.

The [investigation report](U6_Q8_INVESTIGATION.html) separates manufacturer facts from new photo interpretations and the earlier native v0.3 circuit. Those hypotheses were retained in v0.4; v0.5 supersedes them with the new photographs and sources below. The derivative crops are reproducible from crop bounds/rotations in `evidence/u6_q8_investigation.json`; source photographs remain untouched.

## Authorized datasheet symbols, v0.4 (2026-10-08)

- ABLIC S1200.pdf page 5 / Table 3 provides the five-pin SOT-23-5 map. The internally open pin 4 may be tied to VIN/VSS. The B option uses active-high ON/OFF; the 45 option is nominally 4.5 V.
- Mixic MX512H.pdf page 2 provides the eight-pin functions; the truth table supports tri-state outputs in standby. Page 9 gives SOP-8 nominal 3.9 x 4.9 mm body, 6.0 mm overall span and 1.27 mm pitch, matching the selected stock narrow SOIC footprint.
- Actual MCP authoring requests, user authorization and footprint choices are preserved in `evidence/datasheet_symbol_authoring.json`. The MCP library writer retains a legacy generator-version metadata string; creation, native export and checks used installed KiCad 10.0.5.

## Corrected markings and diode candidates, v0.5

- [ABLIC S-812C](https://www.ablic.com/en/doc/datasheet/voltage_regulator/S812C_E.pdf), saved as S812C.pdf: printed p8 Table1 C2N = S-812C33AMC 3.3 V; p11 Table5 pins 1 VSS, 2 VIN, 3 VOUT, 4/5 NC for A variant.
- [ABLIC MP005-A package](https://www.ablic.com/en/doc/package/MP005-A.pdf), saved as ABLIC_MP005-A.pdf: PDF p5 three product-code characters, fourth assembly month, dot positions assembly year/week. Supports C2NM interpretation; M's exact month not decoded.
- [MCC SIL3724A manufacturer PDF, Chipdip mirror](https://static.chipdip.ru/lib/761/DOC050761871.pdf), saved as SIL3724A.pdf: p1 explicit 3724A marking, N/P pair, pin diagram and SOT23-6L dimensions. Same primary document was read via Mouser; direct Mouser download returned HTML, which was replaced with this valid PDF.
- [Nexperia BAV99](https://assets.nexperia.com/documents/data-sheet/BAV99.pdf), saved as BAV99.pdf: A7 marking and dual-series topology support D3 (user-confirmed A7) and D1. D2 was withdrawn after user-confirmed 4P.
- **Withdrawn D4-D6 candidate:** [Diotec 1N4148WS](https://diotec.com/tl_files/diotec/files/pdf/datasheets/1n4148ws.pdf), saved as 1N4148WS.pdf: T4/W2 mark and SOD-323F switching diode. Earlier photos were misread as T4; newer 5U/G3 readings supersede that guess. The PDF is retained as source history.
- New user photographs are copied unchanged to photos/user_updates/ and checksummed separately in evidence/user_evidence_2026-10-08.json. Measurements and the 0.5-ohm shorted-probe clarification are recorded in evidence/measurement_plan.json. The original 26-image manifest is unchanged.

## Sharp 5U / G3 photographs and final measurements

- [Semtech SD05/SD12, manufacturer PDF mirrored by TME](https://www.tme.eu/Document/7ef0e55cabc749c01c5f7eae977e91a5/SD05.pdf), saved as SD05.pdf: page 6 5U marking; pages 1-2 unidirectional SOD-323 TVS with 5 V standoff. D4/D5 candidate.
- [Diodes MMSZ5228BS](https://www.diodes.com/datasheet/download/MMSZ5228BS.pdf), saved as MMSZ5228BS.pdf: page 2 G3 = 3.9 V SOD-323 Zener. D6 provisional first candidate.
- [Nexperia PZUxB](https://assets.nexperia.com/documents/data-sheet/PZUXB_SER.pdf), saved as PZUXB_SER.pdf: page 2 G3 = PZU2.4B 2.4 V SOD323F. D6 alternative; the marking is not unique.
- New D4/D5/D6 user images are preserved in photos/user_updates. Q8 D-E=2 ohm and S-G=2 ohm support joined drains/ground source. E-F=400 kohm refutes direct C6/output copper; F-P=10 ohm and F-G=300 kohm support a supply-related C6 node, with exact path unresolved.

## Latest direct readings: D2, D3 and R41

User reports D2=4P, D3=A7 and R41=331 (nominal 330 ohm). These supersede the older ambiguous photo readings. D3 is supported by Nexperia BAV99 page 2. D2 remains unidentified: [Zetex FMMT2907(A), Issue 3, February 1996](https://media.digikey.com/pdf/Data%20Sheets/Zetex%20PDFs/FMMT2907%28A%29.pdf), page 1, lists FMMT2907R=4P in SOT-23; this is a candidate lead only, without a selected pin map. Local copy: `docs/datasheets/FMMT2907.pdf`. D2 uses an open numbered stock placeholder.

## v0.6 resistor and package audit

[Bourns CRP0603 marking table](https://www.bourns.com/pdfs/CRP0603.pdf), page 3: EIA-96 18=150 and C=100, therefore 18C=15 kohm. Used only for code decoding, not to identify the fitted manufacturer, package or tolerance. Existing photos IMG_2434.jpg (R29) and IMG_2438.jpg (R44) supply the markings. Package-size candidates use relative body/land proportions against neighboring known IC pitches and the installed KiCad 10 stock footprint descriptions. No calibrated dimensional measurements were supplied.

## v0.7 PIC photo tracing

Microchip DS40001802H, page 4 supplies the SOIC pin numbering and port names. Board connections come from IMG_2436/2437/2438 and the overlapping IMG_2435/2434/2433 top-edge photos, not from a typical application. Five GPIO local routes were added. The RC7/TP17-to-R13 continuation is explicitly probable; vias/body-covered routes remain open. User reports C5 470uF/16V, C11 3.2x1.5mm, R8 1.6x0.77mm. These reports supersede conflicting photo estimates.

## v0.8 continuity and front/rear via evidence

User 2026-10-08 replies confirm both multimeter and visible traces for the GPIO destinations in `evidence/pic_gpio_user_mapping.json`; no numerical resistances supplied in this round. RP7 is interpreted as TP7 from IMG_2434. R13 free-end geometry uses IMG_2433; R28/R29/TP7 use IMG_2434; TP1/TP2 resistor tracks use IMG_2432. This supersedes the previous RC7-to-R13 speculation.

Registered original mosaics `photos/front_registered.jpg` and `photos/back_mirrored_registered.jpg`, original rear IMG_2439-2443, existing cross-side registration records, and Microchip's SOIC VSS8/VSS19/VDD20 pin identities support the via comparison. Rear is already mirrored; do not mirror twice. Front projection errors up to approximately 46 pixels on the full mosaic require local verification. Detailed manually chosen coordinates and limitations are in `evidence/via_audit.json`.

[Altium plane-rule documentation](https://www.altium.com/documentation/altium-designer/pcb/design-rule-types/plane) explains clearance/antipad versus plane connection as general PCB terminology. It does not identify this board's hidden nets or layer count.

## v0.9 user via review and cross-checks

User assignments and ambiguities are preserved in `evidence/via_user_review.json`; the supplied MX512H application image is preserved unchanged at `photos/user/via_review/MX512H_pin4_supply.png`. No manufacturer source is inferred from the screenshot beyond its displayed application diagram. Site-to-component cross-checks use the original front/rear photographic mosaics and IMG_2431 through IMG_2443; see `via_audit.json` and `v09_net_changes.json`. Rear appearance, user assignment, model hypothesis and held conflicts remain separate. No new per-via ohms or operating voltages were supplied.

## v0.9.1 incremental user corrections

The user supplied 21 site corrections on 2026-10-08, preserved verbatim apart from capitalization/spacing normalization in `via_user_review.json` follow-up corrections. Component-only reports retain earlier ground/supply claims with separate provenance. Pad selections use the existing photos; notably R44.1 at V017 is photo-selected, while R42.1 is explicitly user-supplied. No new per-site resistance, datasheet, part identity or value was supplied. See `v091_net_changes.json` and `VIA_REVIEW_RESULTS.md`.

## v0.9.2 incremental review and clarifications

Nineteen user site entries and the two follow-up answers are preserved in `via_user_review.json`. The user explicitly confirms V077 C19-R29 is GND. The V114 answer repeats the opposite-side second-pin location without confirming or withdrawing the older GND claim. The Q8 photo pad convention and existing datasheet mapping identify centre B2=pin5 and T2=pin2. No new IC identity or pin-number reassignment is inferred. C19/R29, Q7 and tuning-resistor pad selections use IMG_2434/2433; the Q8/C7/C8/C9 area uses IMG_2431 and the registered mosaic. No new per-site ohms supplied.

### 2026-10-08: v0.9.3 user via confirmations

User directly identifies PIC pins 5/6/7/11/13 at V036/V037/V039/V047/V049; V072 at TP6 (not R22.2); V079/V080 at SGM8542 pin5. No new per-site numerical resistance supplied. These supersede candidate associations, not all inferred remote connections. Exact report retained in evidence/via_user_review.json.

### 2026-10-08: v0.9.4 motor controls and Q1 correction

User identifies U5.2 at V016, joined to V022 (PIC15/RC4), and U5.3 at V019, joined to V023 (PIC16/RC5). V011-V014 identify Q1.L; user explicitly answers “Remove Q1.L–R43.2 connection”. Original V_Q1_LEFT retained only as withdrawn historical evidence. No new numerical resistance supplied.

## v0.9.7 Q7 / R18 / R19 inference

User reports V064-V070 = 11.2 kΩ after confirming V064-V075. No reverse reading or isolated resistor measurement supplied. IMG_2434 shows the Q7/R19 paired-pad continuation; R18=122 and R19=01C supply the existing nominal 1.2k and 10k values. The matched series sum supports the reconstructed base-input/pull-up circuit, but does not uniquely establish the entire topology or a GPIO source.

[Nexperia BC856/BC857/BC858 datasheet, Rev. 9](https://assets.nexperia.com/documents/data-sheet/BC856_BC857_BC858.pdf), accessed 8 October 2026: page 2 gives BC857 pin1 base, pin2 emitter, pin3 collector; page 3 lists BC857C marking 3G plus manufacturing-site code. This verifies the existing candidate pinout and marking interpretation, not the board manufacturer or operating role. Q7 remains a candidate BC857C using the stock KiCad BC857 symbol.

## 2026-10-08 v0.9.8 continuity follow-up

User reports V049–TP03 (TP3), V026–VREF, explicitly rejects V053–VREF, confirms V053–V070, and confirms V067–J3.1/red wire. No numerical ohms were supplied for these connections. See `evidence/v098_net_changes.json` and raw follow-ups in `evidence/via_user_review.json`. User VREF locator photograph preserved unchanged at `photos/user/2026-10-08/VREF_user_locator.png` (SHA-256 in the change record).

These supersede the older photo-only RC1–VREF interpretation. TP104 is the existing native VREF test-point reference. The printed VREF label does not establish measured voltage or circuit function. Previous Q7 local topology and TP3–R10.1 photo association remain qualified. Variable V049–V070 200–300 kΩ is inconclusive/contact-dependent and does not establish OL or a discrete resistance value.

Further same-session reports: V015–TP14 and V017–TP4. Existing V015–R43.2 and V017–R42.1/R44.1 associations retained. TP4 already reaches PIC25/RB4. Numerical ohms not supplied; TP14–Q1.S branch and circuit function remain prior hypotheses.

User V082–board VDD test-point report: marked photograph preserved at `photos/user/2026-10-08/VDD_user_locator.png`, hash in v098_net_changes.json. V082 assigned to TP103/H_VDD only; D3 pin remains unconfirmed. MX512H manufacturer pinout distinguishes pin1 VCC (logic) from pin4 VDD (motor). S-1200B45 suggests nominal 4.5V but no output voltage measurement is recorded.

User V071–VREF follow-up confirms the R21.2/V071 node reaches TP104/VREF/PIC21/RB0. Other prior receiver-bias branches retain their inference status. No numeric ohms or voltage supplied.

User explicitly resolves V011–V014/Q1.L supply to the MX512H pin4 motor rail. Q1 device identity, polarity and function are still hypotheses; this report establishes the rail, not transistor behavior.

## Current v0.9.9: battery path, board labels and two new via checks

The earlier `H_VBAT` reconstruction incorrectly connected battery positive directly to the post-Q1 supply. This is corrected, not just renamed. User-authorized **VSYS** now names the previously unlabelled post-Q1 node. Printed board names are retained everywhere else.

| Name | Physical connection | Evidence |
|---|---|---|
| BATTERY (+) / net BATTERY+ | Battery positive to Q1 single pad3; TP14 and V015/R43.2 on this side | User battery/Q1 report, visible copper in IMG_2438, user V015-TP14 check |
| BATTERY (-) / GND | Battery negative, common ground | Existing board/ground review |
| VSYS | Q1.L/pad2, V011-V014, MX512H U5 pin4, L1/L2 supply sides | User reports; L1/L2 pad1 selections retained from photos |
| VDD | Board VDD test point TP103, PIC20/C32.1/V042, U5 pin1 VCC | Existing reconstruction; user V042-VDD and V082-VDD checks |
| VREF | Board VREF test point TP104, V026/PIC21, V071/R21.2, now V035/PIC4/C39.1 | User via-to-test-point checks; local pad selections from photos |

Battery+ and VSYS are **different copper nets connected through Q1**, not completely isolated circuits. L1 and L2 remain components between VSYS and their downstream nodes: their two terminals are not shorted together by this update. VREF is a connectivity label, not a measured reference voltage. No supply voltages have been measured.

Q1's old **MMBT3904 NPN hypothesis is withdrawn**. [Formosa FMOS3401A manufacturer datasheet](https://www.formosams.com/upload/product/Mosfets/FMOS3401A_REV_C.pdf), page 5, explicitly lists R1A / 3401 / R1 and shows a P-channel MOSFET: gate on the photo right paired pad (pin1), source on left paired pad (pin2), drain on single pad (pin3). Thus **photo Q1.S means single pad, not source**. The stock `Transistor_FET:Q_PMOS_GSD` symbol was installed through KiCad MCP. Exact fitted maker remains unverified. Drain-to-battery/source-to-load is consistent with reverse-polarity protection; gate behavior and powered operation remain unverified. [TI's explanation](https://e2e.ti.com/support/power-management-group/power-management/f/power-management-forum/944817/mc33063a-q1-reverse-polarity-protection-using-p-mosfet) supports that topology, not this board's identity.

The additional downstream supply branches are L2-to-U1 input, L1-to-RF/Q8, Q7-to-receiver, and U6-to-PIR. These are component-separated nodes; some routing and function are still inferred. They are not all independently regulated rails. Candidate 4.5 V / 3.3 V ratings are not measurements.

**V035-VREF** joins the previous RA2/C39 local node to VREF. **V042-VDD** confirms the existing PIC supply connection. These reports do not certify every prior inferred branch on the enlarged VREF net. RC1/V053 remains separate from VREF.

Current verification: **83 native/model net partitions; 36 ERC findings = 28 open pads + 3 isolated labels + 5 power findings**. No PIC pads are open in the model. All 26 original photo checksums retained. 123 reviewed IDs, 120 active via sites, no unresolved numbering conflicts. The remaining search pool is 9 sites in 8 local groups, not eight proven missing nets. No new measurement is queued.

Earlier sections below are historical snapshots; old net names and hypotheses are superseded by this section.

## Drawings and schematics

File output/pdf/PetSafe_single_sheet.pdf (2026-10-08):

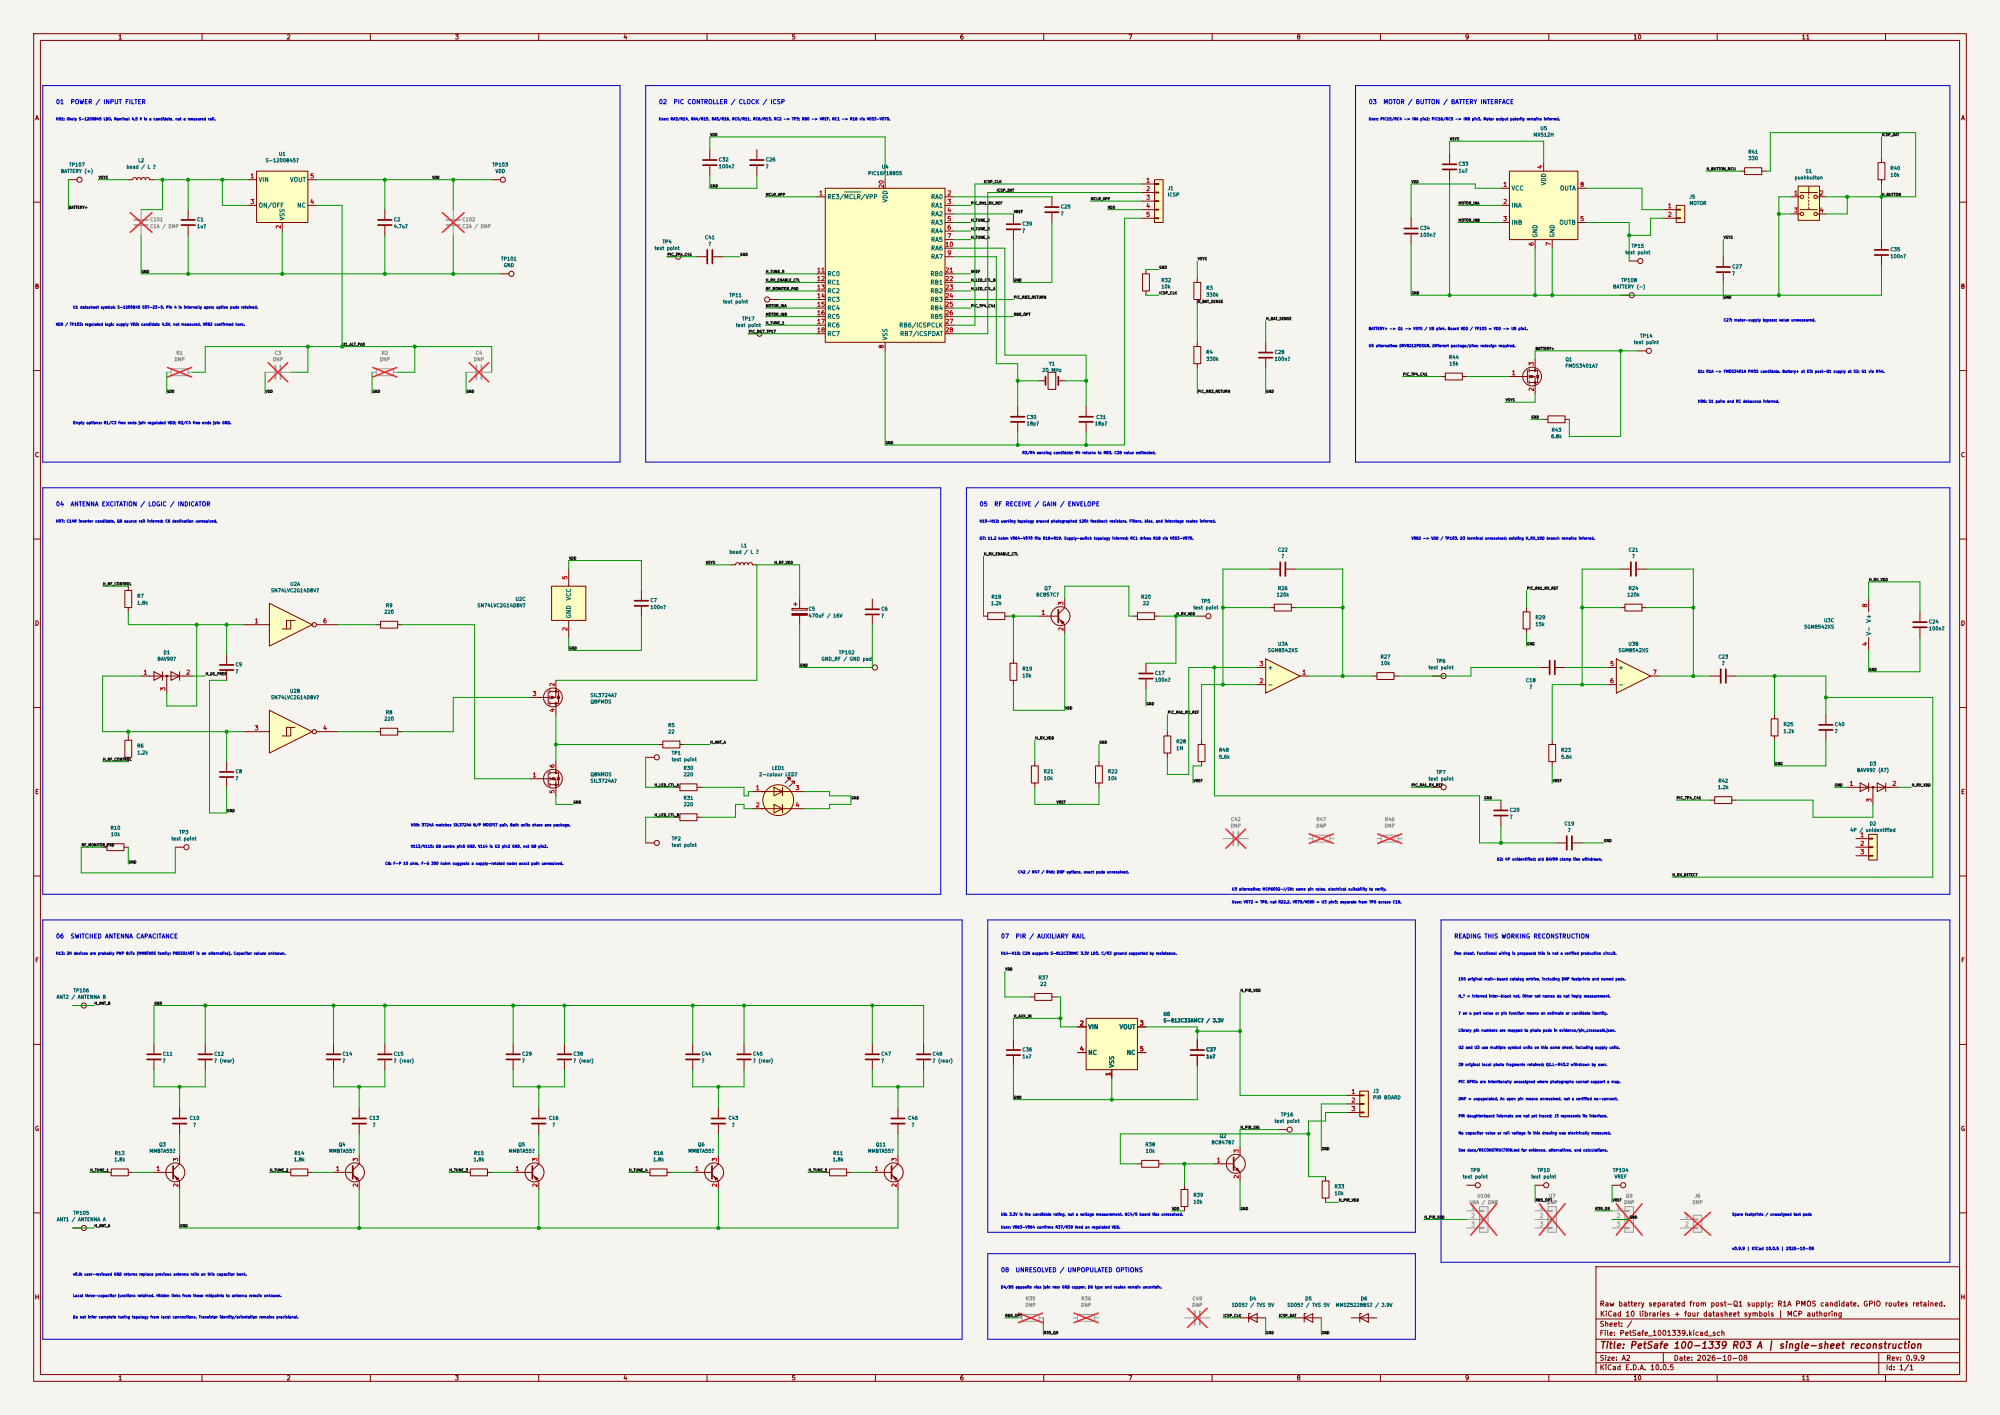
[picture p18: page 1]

U5 alternative: DRV8212PDSGR. Different package/pins; redesign required. 01 POWER / INPUT FILTER

02 PIC CONTROLLER / CLOCK / ICSP

03 MOTOR / BUTTON / BATTERY INTERFACE

H01: likely S-1200B45 LDO. Nominal 4.5 V is a candidate, not a measured rail.

User: PIC15/RC4 -> INA pin2; PIC16/RC5 -> INB pin3. Motor output polarity remains inferred.

U1 datasheet symbol: S-1200B45 SOT-23-5. Pin 4 is internally open; option pads retained.

VDD / TP103: regulated logic supply VDD; candidate 4.5V, not measured. V082 confirmed here.

H06: S1 pairs and RC debounce inferred. Q1: R1A -> FMOS3401A PMOS candidate. Battery+ at D3; post-Q1 supply at S2; G1 via R44.

R3/R4 sensing candidate; R4 returns to RB3. C28 value estimated. Empty options: R1/C3 free ends join regulated VDD; R2/C4 free ends join GND.

H07: C14R inverter candidate. Q8 source rail inferred; C6 destination unresolved. 04 ANTENNA EXCITATION / LOGIC / INDICATOR

05 RF RECEIVE / GAIN / ENVELOPE

H10-H12: working topology around photographed 120k feedback resistors. Filters, bias, and interstage routes inferred. Q7: 11.2 kohm V064-V070 fits R18+R19. Supply-switch topology inferred; RC1 drives R18 via V053-V070.

V082 -> VDD / TP103. D3 terminal unresolved; existing H_RX_VDD branch remains inferred.

D2: 4P unidentified; old BAV99 clamp ties withdrawn.

No capacitor value or rail voltage in this drawing was electrically measured. 06 SWITCHED ANTENNA CAPACITANCE

PIR daughterboard internals are not yet traced; J3 represents its interface. DNP = unpopulated. An open pin means unresolved, not a certified no-connect. H13: 2H devices are probably PNP BJTs (MMBTA55 family; PBSS5140T is an alternative). Capacitor values unknown.

H14-H15: C2N supports S-812C33AMC 3.3V LDO. C/R3 ground supported by resistance.

28 original local photo fragments retained; Q1.L-R43.2 withdrawn by user. Library pin numbers are mapped to photo pads in evidence/pin_crosswalk.json.

See docs/RECONSTRUCTION.md for evidence, alternatives, and calculations.

User: V063-V064 confirms R37/R39 feed on regulated VDD.

v0.9: user-reviewed GND returns replace previous antenna rails on this capacitor bank. Local three-capacitor junctions retained. Hidden links from these midpoints to antenna remain unknown. Do not infer complete tuning topology from local connections. Transistor identity/orientation remains provisional.

D4/D5 opposite vias join rear GND copper. D6 type and routes remain uncertain.

Raw battery separated from post-Q1 supply; R1A PMOS candidate. GPIO routes retained.
KiCad 10 libraries + four datasheet symbols | MCP authoring
Sheet: /
File: PetSafe_1001339.kicad_sch
Title: PetSafe 100-1339 R03 A | single-sheet reconstruction

Size: A2 | Rev: 0.9.9
KiCad E.D.A. 10.0.5 | Id: 1/1

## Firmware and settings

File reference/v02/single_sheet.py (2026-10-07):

"""Generate a functional, single-sheet KiCad working reconstruction.
Coordinate unit = 2.54 mm. All circuit routes are explicitly authored.
"""
from pathlib import Path
from collections import defaultdict
import json, uuid, math, csv
ROOT=Path(__file__).resolve().parents[2]; OUT=ROOT/'schematic'
BASE=json.loads((ROOT/'reference/v01/evidence/reconstruction.json').read_text())
C={c['ref']:dict(c) for c in BASE['components']}
NS=uuid.UUID('c5ee9f10-9018-4456-81b4-a963cfead728')
def uid(s):return str(uuid.uuid5(NS,s))
def q(s):return json.dumps(str(s),ensure_ascii=False)
def mm(x):return f'{x*2.54:.4f}'.rstrip('0').rstrip('.') if x else '0'
def eff(size=.5,just='',hide=False):return f'(effects (font (size {mm(size)} {mm(size)})){" (justify "+just+")" if just else ""}{" hide" if hide else ""})'
RID=uid('sheet');PROJECT='PetSafe_1001339'
GRAPH=[];LIB={};INST=[];PINS={};LOC={};WIRES=[];LABELS=[];NOTES=[];USED=set();NETINFO={}
REF_MAP={'C1A':'C101','C2A':'C102','U6A':'U106'}
for i,r in enumerate(['GND','GND_RF','VDD','VREF','ANT1','ANT2','BATP','BATN'],101):REF_MAP[r]=f'TP{i}'
def text(t,x,y,size=.6):
    NOTES.append(dict(text=t,x=x,y=y,size=size))
    GRAPH.append(f'(text {q(t)} (at {mm(x)} {mm(y)} 0) {eff(size,"left")} (uuid {uid("text:"+str((t,x,y)))}))')
def block(title,x,y,w,h,subtitle):
    for a,b in [((x,y),(x+w,y)),((x+w,y),(x+w,y+h)),((x+w,y+h),(x,y+h)),((x,y+h),(x,y))]:
        GRAPH.append(f'(polyline (pts (xy {mm(a[0])} {mm(a[1])}) (xy {mm(b[0])} {mm(b[1])})) (stroke (width .254) (type default)) (fill (type none)) (uuid {uid(str((title,a,b)))}))')
    text(title,x+3,y+4,1);text(subtitle,x+3,y+8,.52)
def line(pts,fill='none'):
    return '(polyline (pts '+' '.join(f'(xy {mm(x)} {mm(-y)})' for x,y in pts)+f') (stroke (width .254) (type default)) (fill (type {fill})))'
def rect(x1,y1,x2,y2):return f'(rectangle (start {mm(x1)} {mm(-y1)}) (end {mm(x2)} {mm(-y2)} ) (stroke (width .254) (type default)) (fill (type background)))'
def circle(x,y,r,fill='none'):return f'(circle (center {mm(x)} {mm(-y)}) (radius {mm(r)}) (stroke (width .254) (type default)) (fill (type {fill})))'
def pin(p,name,x,y,side,typ='passive',length=2):return dict(p=str(p),name=name,x=x,y=y,side=side,typ=typ,length=length)
def part(ref,x,y,kind=None,value=None,orientation='h',unit=1,pins=None,body=None,size=(8,6),hyp='',reverse=False):
    c=C[ref];USED.add(ref);key=ref if unit==1 else f'{ref}:{unit}'
    if value is not None:c['proposed_value']=value
    if hyp:c['hypothesis']=hyp
    val=c.get('proposed_value',c['value']);val='?' if val=='UNKNOWN' else val
    if ref in REF_MAP:val=f'{ref} / {val}'
    k=kind or c['kind'];g=[]
    if pins is None:
        if k in ['R','C','Y','L','D2']:
            v=orientation=='v'
            pins=[pin('1','~',0,-3,270,length=1.6),pin('2','~',0,3,90,length=1.6)] if v else [pin('1','~',-3,0,0,length=1.6),pin('2','~',3,0,180,length=1.6)]
            if k=='R':paths=[[(-1.4,-.5),(1.4,-.5),(1.4,.5),(-1.4,.5),(-1.4,-.5)]]
            elif k=='C':paths=[[(-1.4,0),(-.4,0)],[(-.4,-1),(-.4,1)],[(.4,-1),(.4,1)],[(.4,0),(1.4,0)]]
            elif k=='Y':paths=[[(-1,-1),(1,-1),(1,1),(-1,1),(-1,-1)],[(-1.4,-1.5),(-1.4,1.5)],[(1.4,-1.5),(1.4,1.5)]]
            elif k=='L':paths=[[(cen+.35*math.cos(math.pi-j*math.pi/10),-.7*math.sin(math.pi-j*math.pi/10)) for j in range(11)] for cen in [-1.05,-.35,.35,1.05]]
            else:paths=[[(-1.4,-.7),(1.4,-.7),(1.4,.7),(-1.4,.7),(-1.4,-.7)]]
            g=[line([(-b,a) for a,b in path] if v else path) for path in paths];size=(2,2)
        elif k=='TP':pins=[pin('1','~',-2,0,0,length=1.3)];g=[circle(0,0,.7)];size=(1,1)
        elif k in ['NPN','PNP']:
            m=c.get('bce',{'B':'R','E':'L','C':'S'})
            pins=[pin(m['B'],'B?',-4,0,0),pin(m['C'],'C?',2,-4,270),pin(m['E'],'E?',2,4,90)]
            g=[line([(-2,-1.5),(-2,1.5)]),line([(-2,-.6),(2,-2)]),line([(-2,.6),(2,2)])]
            arrow=[(.1,1.35),(1.8,1.9),(.8,.65),(.1,1.35)] if k=='NPN' else [(-1.3,.85),(.4,.9),(-.3,2),(-1.3,.85)]
            g.append(line(arrow,'outline'));size=(4,4)
        elif k=='DUALD':
            pins=[pin('L','A1?',-6,0,0),pin('R','K2?',6,0,180),pin('S','K1/A2?',0,4,90)]
            g=[line([(-4,0),(-3,0),(-3,-1),(-1,0),(-3,1),(-3,0)]),line([(-1,-1),(-1,1)]),line([(-1,0),(1,0),(1,-1),(3,0),(1,1),(1,0)]),line([(3,-1),(3,1)]),line([(3,0),(4,0)]),line([(0,0),(0,2)])];size=(6,3)
        elif k=='SW':
            pins=[pin('TL','TL',-5,-2,0),pin('BL','BL',-5,2,0),pin('TR','TR',5,-2,180),pin('BR','BR',5,2,180)]
            g=[line([(-3,-2),(-3,2)]),line([(3,-2),(3,2)]),line([(-3,0),(2,-1)]),line([(0,-1),(0,-2)])];size=(5,3)
        else:
            pp=c['pins'];half=math.ceil(len(pp)/2)
            pins=[pin(p,p,-size[0]-2,(i-(half-1)/2)*2,0) for i,p in enumerate(pp[:half])]
            pins += [pin(p,p,size[0]+2,(i-(len(pp)-half-1)/2)*2,180) for i,p in enumerate(pp[half:])]
            g=[rect(-size[0],-size[1],size[0],size[1])]
    else:g=body or [rect(-size[0],-size[1],size[0],size[1])]
    if reverse:
        assert len(pins)==2
        pins[0]['p'],pins[1]['p']=pins[1]['p'],pins[0]['p']
    lid='PetSafe_Working:RE_'+ref
    LIB.setdefault(ref,dict(lid=lid,units={}));assert unit not in LIB[ref]['units']
    LIB[ref]['units'][unit]=(g,pins)
    if k in ['R','C','L','Y','D2'] and orientation=='v':rx,ry,vx,vy,just=x+2,y-.7,x+2,y+.9,'left'
    else:rx,ry,vx,vy,just=x,y-size[1]-2.5,x,y-size[1]-1,''
    if ref in ['U2','U3'] and unit==3:rx,ry,vx,vy,just=x-9,y-1,x-9,y+.5,'right'
    if ref=='U4':rx,ry,vx,vy=x+12,y-28,x+12,y-26.5
    if ref=='U5':rx,ry,vx,vy=x+12,y-14,x+12,y-12.5
    if k in ['NPN','PNP']:rx=vx=x-2
    if ref=='R43':ry,vy=y+2.5,y+4
    if ref=='R48':rx=vx=x+4
    if ref=='GND_RF':rx=vx=x-6
    INST.append(dict(ref=ref,actual=REF_MAP.get(ref,ref),x=x,y=y,unit=unit,lid=lid,value=val,rx=rx,ry=ry,vx=vx,vy=vy,just=just,pins=pins,kind=k))
    LOC[key]=dict(x=x,y=y,kind=k,unit=unit,size=size)
    for p in pins:
        ep=ref+'.'+p['p'];assert ep not in PINS,ep;PINS[ep]=(x+p['x'],y+p['y'])
def pos(p):return PINS[p] if isinstance(p,str) else tuple(p)
def wire(name,*points):
    pp=[pos(p) for p in points]
    for a,b in zip(pp,pp[1:]):
        if a==b:continue
        assert a[0]==b[0] or a[1]==b[1],('NONORTHOGONAL',name,a,b)
        WIRES.append(dict(net=name,a=a,b=b))
def label(name,p):LABELS.append(dict(net=name,p=pos(p)))
def stub(name,ep,dx=0,dy=0):
    if dx<0 and dy==0:dx=-max(abs(dx),math.ceil((len(name)*.32+1.2)*2)/2)
    a=pos(ep);b=(a[0]+dx,a[1]+dy);wire(name,a,b);label(name,b)
def bus(name,y,eps,x1=None,x2=None):
    pp=[pos(p) for p in eps];xs=[p[0] for p in pp]
    x1=min(xs) if x1 is None else x1;x2=max(xs) if x2 is None else x2
    wire(name,(x1,y),(x2,y));label(name,(x1,y))
    for ep,(x,_) in zip(eps,pp):wire(name,ep,(x,y))

def power():
    block('01  POWER / INPUT FILTER',10,20,135,88,'H01: likely S-1200B45 LDO. Nominal 4.5 V is a candidate, not a measured rail.')
    part('BATP',18,42,value='BATTERY +');part('L2',33,42,value='bead / L ?')
    part('C1',44,52,orientation='v',value='1u?');part('C1A',33,52,orientation='v')
    pp=[pin('L1','VIN (1)?',-9,-4,0,'power_in'),pin('L2','GND (2)?',0,9,90,'power_in',length=3),pin('L3','EN (3)?',-9,3,0,'input'),pin('R1','OUT (5)?',9,-4,180,'power_out'),pin('R2','NC/ALT (4)?',9,3,180)]
    part('U1',66,46,value='S-1200B45?',pins=pp,size=(7,6),hyp='H01: ABLIC S1200 Rev6 page23 maps PPE to S-1200B45-M5T1x and fourth character to lot. Strong identity candidate; board-wide connections remain inferred.')
    part('C2',90,52,orientation='v',value='4.7u?');part('C2A',106,52,orientation='v');part('VDD',117,42,value='VDD pad');part('GND',119,64,value='GND pad')
    wire('H_VBAT','BATP.1','L2.1');label('H_VBAT',(23,42))
    wire('H_LDO_IN','L2.2','U1.L1');wire('H_LDO_IN','C1.1',(44,42));wire('H_LDO_IN','C1A.1',(38,49),(38,42));wire('H_LDO_IN','U1.L3',(52,49),(52,42))
    wire('H_VDD','U1.R1','VDD.1');wire('H_VDD','C2.1',(90,42));wire('H_VDD','C2A.1',(106,42));label('H_VDD',(101,42))
    bus('H_GND',64,['C1.2','C1A.2','U1.L2','C2.2','C2A.2','GND.1'])
    text('Original pad IDs on U1. Candidate datasheet pin numbers in parentheses.',17,72,.55)
    part('R1',42,87);part('C3',65,87);part('R2',90,87);part('C4',112,87)
    wire('U1_ALT_PAD','U1.R2',(80,49),(80,81),(115,81),'C4.2')
    wire('U1_ALT_PAD','R1.2',(48,87),(48,81),(80,81));wire('U1_ALT_PAD','C3.2',(72,87),(72,81));wire('U1_ALT_PAD','R2.2',(97,87),(97,81));label('U1_ALT_PAD',(80,81))
    text('Optional R1/R2/C3/C4 network: empty footprints; free ends unresolved.',17,99,.55)

def controller():
    block('02  PIC CONTROLLER / CLOCK / ICSP',151,20,160,88,'H02: programming and decoupling inferred. Unassigned GPIOs stay open; PPS prevents a unique functional pin guess.')
    names=['MCLR/VPP','RA0','RA1','RA2','RA3','RA4','RA5','VSS','OSC1/RA7','OSC2/RA6','RC0','RC1','RC2','RC3','RC4','RC5','RC6','RC7','VSS','VDD','RB0','RB1','RB2','RB3','RB4','RB5','ICSPCLK/RB6','ICSPDAT/RB7']
    pp=[pin('20','VDD',0,-25,270,'power_in'),pin('8','VSS',-3,25,90,'power_in'),pin('19','VSS',3,25,90,'power_in')]
    for pn,y in [(1,-17),(2,-11),(3,-8),(4,-5),(5,-2),(6,1),(7,4),(9,13),(10,17)]:pp.append(pin(pn,names[pn-1],-13,y,0,'input' if pn in(1,9) else 'bidirectional'))
    for i,pn in enumerate(list(range(11,19))+list(range(21,29))):pp.append(pin(pn,names[pn-1],13,-20+i*2.5,180,'bidirectional'))
    part('U4',207,62,pins=pp,size=(11,23))
    part('J1',271,47,value='ICSP',pins=[pin(p,p,-5,(i-2)*3,0) for i,p in enumerate(['CLK','DAT','VPP','VDD','GND'])],size=(3,8))
    part('C25',166,38,orientation='v',value='100n?');part('C26',177,38,orientation='v',value='100n?');part('C39',188,38,orientation='v',value='100n?')
    bus('H_VDD',32,['U4.20','C25.1','C26.1','C39.1']);bus('H_GND',44,['C25.2','C26.2','C39.2'])
    wire('ICSP_CLK','U4.27',(228,77),(228,47),(253,47),(253,41),'J1.CLK');label('ICSP_CLK',(230,47))
    wire('ICSP_DAT','U4.28',(231,79.5),(231,50),(257,50),(257,44),'J1.DAT');label('ICSP_DAT',(233,50))
    stub('MCLR_VPP','U4.1',-7,0);stub('MCLR_VPP','J1.VPP',-5,0);stub('H_VDD','J1.VDD',-3,0)
    wire('H_GND','J1.GND',(263,53),(263,91));bus('H_GND',91,['U4.8','U4.19'],204,263)
    part('Y1',172,77,value='20 MHz');part('C30',164,88,orientation='v',value='18p?');part('C31',180,88,orientation='v',value='18p?')
    wire('OSC1','U4.9',(188,75),(188,71),(164,71),(164,77),'Y1.1');wire('OSC1','C30.1',(164,77));label('OSC1',(177,71))
    wire('OSC2','U4.10',(188,79),(188,81),(180,81),(180,77),'Y1.2');wire('OSC2','C31.2',(180,96),(190,96),(190,81),(180,81))
    wire('H_GND','C30.2',(164,98),(175,98),(175,85),'C31.1');label('H_GND',(164,98))
    part('TP11',225,49.5);wire('PIC_RC3','U4.14','TP11.1')
    part('R3',280,68,orientation='v');part('R4',280,83,orientation='v');part('C28',296,83,orientation='v',value='100n?');part('TP17',301,75)
    stub('H_VBAT','R3.1',0,-4);wire('H_BAT_SENSE','R3.2',(280,75),'R4.1');wire('H_BAT_SENSE',(280,75),'TP17.1');wire('H_BAT_SENSE','C28.1',(296,75));label('H_BAT_SENSE',(284,75));bus('H_GND',94,['R4.2','C28.2'])
    text('H03: R3/R4 divider candidate: 1/2 VBAT. Capacitor values estimated.',239,101,.5)

def motor_ui():
    block('03  MOTOR / BUTTON / BATTERY INTERFACE',317,20,139,88,'H04: MX512H typical supply/output topology. Motor A/B and MCU control assignments remain hypotheses.')
    pp=[pin('1','VCC logic',-10,-5,0,'power_in'),pin('2','INA',-10,0,0,'input'),pin('3','INB',-10,5,0,'input'),pin('4','VDD motor',0,-12,270,'power_in'),pin('5','OUTB',10,5,180,'output'),pin('8','OUTA',10,-5,180,'output'),pin('6','GND',-2,12,90,'power_in'),pin('7','GND',2,12,90,'power_in')]
    part('U5',361,48,pins=pp,size=(8,10));part('C33',339,39,orientation='v',value='1u?');part('C34',330,54,orientation='v',value='100n?')
    part('J5',393,49,value='MOTOR',pins=[pin('A','A',-5,-6,0),pin('B','B',-5,4,0)],size=(3,7));part('TP15',383,61);part('BATN',381,69,value='BATTERY -')
    bus('H_VBAT',33,['U5.4','C33.1']);wire('H_VDD','U5.1',(330,43),'C34.1');label('H_VDD',(330,43));wire('H_GND','C33.2',(339,69));bus('H_GND',69,['C34.2','U5.6','U5.7','BATN.1'])
    wire('H_MOTOR_A','U5.8','J5.A');wire('H_MOTOR_B','U5.5','J5.B');wire('H_MOTOR_B','TP15.1',(381,53))
    stub('H_MOTOR_INA','U5.2',-8,0);stub('H_MOTOR_INB','U5.3',-8,0)
    part('S1',423,48);part('C35',440,59,orientation='v',value='100n?');part('R40',440,40,orientation='v');part('R41',410,40,value='mark 33...?');part('C27',403,63,orientation='v')
    stub('H_VDD','R40.1',0,-3);wire('H_BUTTON','R40.2',(440,46),'C35.1');wire('H_BUTTON',(440,46),'S1.TR');wire('H_BUTTON','S1.BR',(432,50),(432,46))
    wire('H_BUTTON','R41.2',(414,40),(414,31),(448,31),(448,46),(440,46));label('H_BUTTON',(440,46))
    wire('H_GND','S1.TL',(416,46),(416,50),'S1.BL');wire('H_GND',(416,50),(416,69));wire('H_GND','C35.2',(440,69),(416,69));wire('H_GND',(379,69),(416,69));stub('H_BUTTON_MCU','R41.1',-3,0)
    text('C27 role unresolved',403,75,.5)
    part('Q1',357,88,'NPN',value='MMBT3904?',hyp='H05: R1A mark suggests MMBT3904; B=R, E=L, C=S inferred from SOT23 orientation.')
    part('R44',340,88,value='15k?');part('R43',364,98);part('TP14',385,82)
    wire('Q1_BASE','R44.2','Q1.R');wire('Q1_EMITTER','Q1.L',(359,94),(370,94),(370,98),'R43.2');wire('H_BAT_DETECT','Q1.S',(359,82),'TP14.1');stub('H_Q1_BIAS','R44.1',-3,0);stub('H_GND','R43.1',-2,0)
    text('H05: NPN interface candidate; bias destination unresolved.',397,87,.5)
    text('H06: S1 pairs and RC debounce inferred.',397,94,.5)

def rf():
    block('04  ANTENNA EXCITATION / LOGIC / INDICATOR',10,114,210,95,'H07: U2 matches SN74LVC2G14 (C14R, 6 pins). Q8 probably contains two switching devices; exact type unresolved.')
    tri=[line([(-4,-3),(-4,3),(3,0),(-4,-3)]),circle(3.6,0,.6),line([(-2,-1),(-1,-1),(-1,1),(0,1),(0,-1),(1,-1)])]
    part('U2',69,146,value='74LVC2G14?',unit=1,pins=[pin('T3','~',-6,0,0,'input'),pin('B3','~',6,0,180,'output')],body=tri,size=(5,4),hyp='H07: exact TI C14R marking and 6-pin DBV package match. Photo top row left to right = 3,2,1; bottom = 4,5,6.')
    part('U2',69,171,unit=2,pins=[pin('T1','~',-6,0,0,'input'),pin('B1','~',6,0,180,'output')],body=tri,size=(5,4))
    part('U2',133,141,unit=3,pins=[pin('B2','VCC',0,-5,270,'power_in'),pin('T2','GND',0,5,90,'power_in')],body=[rect(-5,-3,5,3)],size=(5,3))
    part('C7',150,141,orientation='v',value='100n?');part('C8',53,181,orientation='v');part('C9',53,156,orientation='v')
    part('R8',91,171);part('R9',91,146);part('R6',30,175,orientation='v');part('R7',30,140,orientation='v');part('D1',39,158,'DUALD',value='BAV99?',hyp='H08: A7 mark + SOT23 fits BAV99 series dual diode. Photo pad mapping is provisional.')
    pp=[pin('T3','drive A?',-7,-5,0),pin('T1','drive B?',-7,2,0),pin('T2','T2',7,-5,180),pin('B1','B1',-3,9,90),pin('B2','B2',1,9,90),pin('B3','B3',7,5,180)]
    part('Q8',118,169,value='dual switch? / 372A',pins=pp,size=(5,7),hyp='H09: paired 220-ohm inputs from U2 suggest complementary RF switching device; exact type and supply-pad assignment unknown.')
    wire('U2_DRIVE_A','U2.B3','R9.1');wire('Q8_DRIVE_A','R9.2',(102,146),(102,164),'Q8.T3')
    wire('U2_DRIVE_B','U2.B1','R8.1');wire('Q8_DRIVE_B','R8.2','Q8.T1')
    wire('H_RF_IN_A','U2.T3',(53,146),'C9.1');wire('H_RF_IN_A',(53,146),(39,146),(30,146),'R7.2');wire('H_RF_IN_A','D1.S',(39,165),(46,165),(46,146))
    wire('H_RF_IN_B','U2.T1',(53,171),'C8.1');wire('H_RF_IN_B',(53,171),(30,171),'R6.1');wire('H_RF_IN_B','D1.L',(24,158),(24,171),(30,171))
    stub('H_RF_CONTROL','R7.1',-6,0);stub('H_RF_CONTROL','R6.2',-6,0);stub('H_D1_FREE','D1.R',3,0)
    # Separate capacitor returns are joined below the two gates.
    wire('H_GND','C9.2',(57,159),(57,190));wire('H_GND','C8.2',(53,190),(57,190));label('H_GND',(53,190))
    bus('H_VDD',131,['U2.B2','C7.1']);bus('H_GND',152,['U2.T2','C7.2'])
    part('L1',174,132,value='bead / L ?');part('C5',187,143,orientation='v',value='electrolytic ?');part('C6',204,143,orientation='v');part('GND_RF',204,156,value='GND pad');part('TP2',200,132)
    stub('H_VBAT','L1.1',-6,0);wire('H_RF_VDD','L1.2',(204,132));wire('H_RF_VDD','C5.1',(187,132));wire('H_RF_VDD','C6.1',(204,132));label('H_RF_VDD',(183,132));bus('H_GND',156,['C5.2','C6.2','GND_RF.1'])
    part('R5',157,174);wire('H_RF_OUT_CAND','Q8.B3','R5.1');stub('H_ANT_A','R5.2',6,0)
    text('H09: B3 = RF output is low-confidence.',96,193,.5);text('Q8 T2/B1/B2 power assignments open.',96,198,.5)
    part('R10',27,198);part('TP3',43,198);stub('H_RF_MONITOR','R10.2',0,4);wire('RF_MONITOR_PAD','R10.1',(19,198),(19,204),(41,204),'TP3.1')
    part('LED1',182,187,value='2-colour LED?',size=(5,5));part('R30',161,184);part('R31',161,191);part('TP1',211,187)
    wire('H_LED_A','R30.2',(174,184),(174,186),'LED1.TL')
    wire('H_LED_B','R31.2',(172,191),(172,188),'LED1.TR')
    stub('H_LED_CTL_A','R30.1',-5,0);stub('H_LED_CTL_B','R31.1',-5,0)
    wire('H_LED_COMMON','LED1.BL',(199,186),(199,187),'TP1.1');wire('H_LED_COMMON','LED1.BR',(199,188),(199,187));label('H_LED_COMMON',(200,187))

def receiver():
    block('05  RF RECEIVE / GAIN / ENVELOPE',226,114,230,95,'H10-H12: working topology around photographed 120k feedback resistors. Filters, bias, and interstage routes inferred.')
    tri=[line([(-5,-5),(-5,5),(5,0),(-5,-5)])]
    part('U3',300,158,value='SGM8542XS',unit=1,pins=[pin('3','+',-7,-2,0,'input'),pin('2','-',-7,2,0,'input'),pin('1','OUT',7,0,180,'output')],body=tri,size=(5,5))
    part('U3',382,158,unit=2,pins=[pin('5','+',-7,-2,0,'input'),pin('6','-',-7,2,0,'input'),pin('7','OUT',7,0,180,'output')],body=tri,size=(5,5))
    part('U3',437,146,unit=3,pins=[pin('8','VS+',0,-5,270,'power_in'),pin('4','VS-',0,5,90,'power_in')],body=[rect(-5,-3,5,3)],size=(5,3))
    part('C24',449,146,orientation='v',value='100n?');bus('H_RX_VDD',136,['U3.8','C24.1']);bus('H_GND',157,['U3.4','C24.2'])
    part('R26',300,142,reverse=True);part('C22',300,133,reverse=True);part('R48',281,176,orientation='v');part('R27',324,158,reverse=True);part('TP6',337,158)
    wire('RX_A_FB','U3.2',(286,160),(286,142),'R26.2');wire('RX_A_FB',(286,142),(286,133),'C22.2');wire('RX_A_FB','R48.1',(281,160),(286,160))
    wire('RX_A_OUT','U3.1','R27.2');wire('RX_A_OUT',(314,158),(314,142),'R26.1');wire('RX_A_OUT','C22.1',(314,133),(314,142))
    wire('RX_A_FILTER','R27.1','TP6.1');wire('H_RX_BIAS','R48.2',(279,179),(279,183));label('H_RX_BIAS',(279,183))
    part('R24',382,142,reverse=True);part('C21',382,133,reverse=True);part('R23',363,176,orientation='v');part('C18',363,156,reverse=True)
    wire('RX_B_FB','U3.6',(370,160),(370,142),'R24.2');wire('RX_B_FB',(370,142),(370,133),'C21.2');wire('RX_B_FB','R23.1',(363,160),(370,160))
    wire('RX_B_OUT','U3.7',(396,158),(396,142),'R24.1');wire('RX_B_OUT','C21.1',(396,133),(396,142))
    wire('RX_B_PLUS','U3.5','C18.1');wire('RX_A_FILTER','C18.2',(344,156),(344,158),'TP6.1');stub('H_RX_BIAS','R23.2',0,4)
    part('C23',403,158);part('R25',415,170,orientation='v');part('C40',427,170,orientation='v');part('R42',403,187)
    part('D3',438,184,'DUALD',value='clamp?');part('D2',438,198,'DUALD',value='clamp?');part('R29',357,145,orientation='v',value='15k?');part('R28',273,174,orientation='v',value='1M');part('C19',367,197);part('C20',351,190,orientation='v');part('TP7',337,184)
    wire('RX_B_OUT',(396,158),'C23.1');wire('H_RX_DETECT','C23.2',(415,158),'R25.1');wire('H_RX_DETECT',(415,158),(427,158),'C40.1');bus('H_GND',179,['R25.2','C40.2'])
    wire('H_RX_RF_SENSE','D3.S',(438,191),(424,191),(424,187),'R42.2');wire('H_RX_RF_SENSE','C19.2',(420,197),(420,187),(424,187))
    stub('H_RX_BIAS','R29.1',0,-4);wire('RX_B_PLUS','R29.2',(357,151),(373,151),(373,156),'U3.5')
    stub('H_ANT_B','R42.1',-4,0);stub('H_GND','D3.L',-3,0);stub('H_RX_VDD','D3.R',3,0);stub('H_GND','D2.L',-3,0);stub('H_RX_VDD','D2.R',3,0)
    wire('H_RX_DETECT','D2.S',(438,205),(452,205),(452,163),(427,163),(427,158));wire('H_RX_DETECT','TP7.1',(330,184),(330,205),(438,205));label('H_RX_DETECT',(391,205))
    wire('RX_A_PLUS','C19.1',(351,197),'C20.2');wire('RX_A_PLUS',(351,197),(346,197),(346,186),(284,186),(284,156),'U3.3');stub('H_GND','C20.1',-4,0)
    stub('H_RX_BIAS','R28.1',0,-4);wire('RX_A_PLUS','R28.2',(273,181),(278,181),(278,156),(284,156))
    C['Q7']['bce']={'B':'L','E':'R','C':'S'}
    part('Q7',247,144,'PNP',value='BC857C?',hyp='H11: 3GW fits BC857C. Physical B=L E=R C=S orientation and switched supply role inferred.')
    part('R19',237,157,orientation='v');part('R18',257,134);part('R20',268,144);part('C17',268,158,orientation='v',value='100n?');part('TP5',282,144)
    wire('RX_SUPPLY_SERIES','Q7.S',(249,137),(264,137),(264,144),'R20.1');wire('H_RX_VDD','R20.2','TP5.1');wire('H_RX_VDD','C17.1',(275,155),(275,144));label('H_RX_VDD',(275,144));stub('H_GND','C17.2',0,4)
    wire('H_RX_ENABLE','R19.1',(237,144),'Q7.L');stub('H_RX_ENABLE_CTL','R19.2',0,4)
    wire('H_RX_SUPPLY_FEED','Q7.R',(249,151),(260,151),'R18.2');stub('H_VDD','R18.1',-4,0)
    part('R21',242,181,orientation='v');part('R22',257,181,orientation='v')
    stub('H_RX_VDD','R21.1',0,-5);wire('H_RX_BIAS','R21.2',(242,188),(257,188),'R22.2');label('H_RX_BIAS',(247,188));stub('H_GND','R22.1',0,-4)
    part('C42',289,196);part('R47',309,196);part('R46',325,196)
    text('C42 / R47 / R46: DNP options, exact pads unresolved.',238,204,.5)
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

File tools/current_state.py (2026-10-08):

"""Derive current review metrics; remaining_work.json owns unresolved questions."""
from pathlib import Path
from collections import Counter
import hashlib
import json
import re

ROOT = Path(__file__).resolve().parents[1]

def read(path):
    return json.loads((ROOT / path).read_text(encoding='utf-8'))

def current_state():
    model = read('evidence/reconstruction.json')
    validation = read('evidence/validation.json')
    work = read('evidence/remaining_work.json')
    components = {c['ref']: c for c in model['components']}
    fitted = sorted(p for p in model['unresolved_pins'] if components[p.rsplit('.', 1)[0]]['population'] != 'DNP')
    dnp = sorted(set(model['unresolved_pins']) - set(fitted))
    ceramics = sorted((c['ref'] for c in components.values() if c['kind'] == 'C' and c['population'] == 'populated' and c['ref'] != 'C5'), key=lambda ref:int(re.search(r'\d+', ref).group()))
    magnetic = sorted(c['ref'] for c in components.values() if c['kind'] == 'L' and c['population'] == 'populated')
    blank = sorted(c['ref'] for c in components.values() if not c['footprint'])
    return dict(
        date=work['date'], revision=model['revision'], review_revision=work['review_revision'],
        interpretation='Every catalog entry is drawn. Hardware connectivity, values and identities are only partially verified. No routed PCB exists.',
        catalog_entries=len(components), physical_pins=sum(len(c['pins']) for c in components.values()),
        unresolved_physical_pins=len(model['unresolved_pins']),
        unresolved_pins_by_population=dict(Counter(components[p.rsplit('.', 1)[0]]['population'] for p in model['unresolved_pins'])),
        unresolved_pins_by_reference=dict(Counter(p.rsplit('.', 1)[0] for p in model['unresolved_pins'])),
        current_gpio_pins=sorted(int(p.split('.')[1]) for p in fitted if p.startswith('U4.')),
        current_fitted_open_pads=fitted, current_dnp_open_pads=dnp,
        unknown_ceramic_values=ceramics, unknown_magnetic_values=magnetic,
        footprints=dict(assigned=len(components)-len(blank), unassigned=blank, qualification='Assigned is not the same as measured. R8 and C11 anchor photo-based package families.'),
        erc_total=validation['erc_total'], erc_by_type=validation['erc_by_type'],
        modeled_nets=validation['proposed_net_partitions'],
        schematic_sha256=hashlib.sha256((ROOT/'schematic/PetSafe_1001339.kicad_sch').read_bytes()).hexdigest(),
        known_identified_ICs_needing_new_symbols=[], complete_symbols_for_selected_candidates=True,
        available_instruments=['LCR meter', 'multimeter'],
        via_review=read('evidence/via_audit.json')['review_summary'],
        current_gaps=[dict(id=i['id'], area=i['area'], gap=i['unknown'], method=i['next_action']) for i in work['issues']],
        items=work['issues'], rails=work['rails'],
        population_note='Open pads include empty options, test pads and internally NC pins. Zero open PIC pads does not prove every onward route.',
        completed=work['confirmed_summary'], history='docs/history/README.md',
    )

if __name__ == '__main__':
    status = current_state()
    (ROOT/'evidence/completion_status.json').write_text(json.dumps(status, indent=2)+'\n', encoding='utf-8')
    print(f"Current status: {len(status['items'])} issue groups; {len(status['current_fitted_open_pads'])} fitted-entry open pads; {len(status['current_gpio_pins'])} open PIC pads")

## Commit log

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2026-10-07 Reconstruct main board as one functional KiCad sheet with documented hypotheses
    [PetSafe_1001339.kicad_sch, candidate_connections_NOT_WIRED.csv, components.csv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]
2026-10-07 Rebuild single-sheet schematic with KiCad 10 stock libraries and MCP
    [PetSafe_1001339.kicad_sch, components.csv, mcp_standard_placements.kicad_sch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]
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2026-10-08 Add datasheet-derived U1 and U5 symbols through KiCad MCP
    [PetSafe_1001339.kicad_sch, components.csv, mcp_standard_placements.kicad_sch]
2026-10-08 Update component candidates and routing from markings and resistance evidence
    [PetSafe_1001339.kicad_sch, components.csv, mcp_standard_placements.kicad_sch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]
2026-10-08 Assign stock footprint candidates and audit remaining reconstruction gaps
    [PetSafe_1001339.kicad_sch, completion_audit.csv, components.csv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]
2026-10-08 Trace PIC connections from photos and record passive dimensions
    [PetSafe_1001339.kicad_sch, completion_audit.csv, components.csv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]
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2026-10-08 Add complete PIC GPIO tracing map from new user photos
    [PIC_GPIO_missing.csv]
2026-10-08 Incorporate measured PIC mappings and front-rear via evidence
    [PIC_GPIO_missing.csv, PetSafe_1001339.kicad_sch, completion_audit.csv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]
2026-10-08 Reconcile user via review and document remaining schematic gaps
    [PIC_GPIO_missing.csv, PetSafe_1001339.kicad_sch, completion_audit.csv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]
2026-10-08 Apply incremental via corrections and connect R42 R44 at V017
    [PetSafe_1001339.kicad_sch, mcp_standard_placements.kicad_sch, proposed_nets.csv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]
2026-10-08 Correct Q8 via mapping and ground the C19 R29 junction
    [PetSafe_1001339.kicad_sch, mcp_standard_placements.kicad_sch, proposed_nets.csv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]
2026-10-08 Record confirmed PIC vias and correct TP6 and op-amp via mappings
    [PIC_GPIO_missing.csv, PetSafe_1001339.kicad_sch, mcp_standard_placements.kicad_sch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]
2026-10-08 Connect PIC motor controls and remove refuted Q1 R43 connection
    [PIC_GPIO_missing.csv, PetSafe_1001339.kicad_sch, completion_audit.csv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]
2026-10-08 Apply measured via routes and add adaptive photo measurement guide
    [PIC_GPIO_missing.csv, PetSafe_1001339.kicad_sch, completion_audit.csv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]
2026-10-08 Record Q7 supply via and retire capacitor pair sweep
    [via_inventory.csv, via_pair_readings.csv, via_pair_round2_readings.csv]
2026-10-08 Reconstruct Q7 base network from measured resistor path
    [PetSafe_1001339.kicad_sch, completion_audit.csv, components.csv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]
2026-10-08 Resolve RC1 receiver control and measured test-point routes
    [PIC_GPIO_missing.csv, PetSafe_1001339.kicad_sch, completion_audit.csv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]
2026-10-08 Distinguish logic and motor supplies and record VREF bias route
    [PetSafe_1001339.kicad_sch, completion_audit.csv, components.csv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]
2026-10-08 Separate battery and VSYS rails; confirm VREF and VDD via routes
    [PetSafe_1001339.kicad_sch, completion_audit.csv, components.csv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]
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2026-10-09 Address architect review: J1 numbering, live completion checks and circuit gaps
    [PetSafe_1001339.kicad_sch, completion_audit.csv, mcp_standard_placements.kicad_sch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]
2026-10-09 Record measured D3 rails and R42 continuity; close V082 association
    [PetSafe_1001339.kicad_sch, completion_audit.csv, components.csv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]
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2026-10-09 Record D2 series-junction measurements and narrow remaining checks
    [completion_audit.csv]
2026-10-09 Confirm D2 user pad orientation and R-to-VDD reading
    [completion_audit.csv]
2026-10-09 Record D2 L rail readings and retire direct rail-clamp checks
    [completion_audit.csv]
2026-10-09 Map D2 antenna and receiver connections with empty R46 option
    [PetSafe_1001339.kicad_sch, completion_audit.csv, components.csv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]
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2026-10-09 Resolve measured U3 bias and J3 ground; queue focused follow-up checks
    [PetSafe_1001339.kicad_sch, completion_audit.csv, components.csv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]
2026-10-09 Confirm J3 signal entry, R23 input and R22 ground from bench readings
    [PetSafe_1001339.kicad_sch, completion_audit.csv, components.csv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]
2026-10-09 Resolve R23 junction and require photo tracing before bench requests
    [PetSafe_1001339.kicad_sch, completion_audit.csv, components.csv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]
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2026-10-09 Map U7 PIR connector and correct RB0 signal route
    [PetSafe_1001339.kicad_sch, completion_audit.csv, components.csv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]
2026-10-09 Resolve C26 to PIC RA1 from annotated board photo
    [PetSafe_1001339.kicad_sch, completion_audit.csv, components.csv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]
2026-10-09 Reconstruct C6 in parallel with C5 from board photos
    [PetSafe_1001339.kicad_sch, completion_audit.csv, components.csv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]
2026-10-09 Resolve receiver option wiring and measured D6 U6 connections
    [PetSafe_1001339.kicad_sch, completion_audit.csv, components.csv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]
2026-10-09 Map J6 Q9 option and correct button routing to VPP
    [PetSafe_1001339.kicad_sch, completion_audit.csv, components.csv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]
2026-10-09 Complete U6A option pad mapping with confirmed ground
    [PetSafe_1001339.kicad_sch, completion_audit.csv, components.csv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]
2026-10-09 Assign stock S1 tactile footprint from measured body dimensions
    [PetSafe_1001339.kicad_sch, completion_audit.csv, components.csv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]
2026-10-09 Group optional circuits by function and replace device placeholders
    [PetSafe_1001339.kicad_sch, completion_audit.csv, components.csv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]
2026-10-09 Record LED1 red-green emitters and measured square body
    [PetSafe_1001339.kicad_sch, completion_audit.csv, components.csv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]
2026-10-09 Assign C5 radial footprint from measured can dimensions
    [PetSafe_1001339.kicad_sch, completion_audit.csv, components.csv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]
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2026-10-09 Clean up current schematic evidence and finishing plan for v0.9.29
    [PetSafe_1001339.kicad_sch, completion_audit.csv, components.csv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]
2026-10-09 Resolve RF drive routing from original photos and document review findings
    [PetSafe_1001339.kicad_sch, completion_audit.csv, components.csv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]
2026-10-09 Declare power sources and consolidate remaining schematic work
    [PetSafe_1001339.kicad_sch, completion_audit.csv, components.csv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]
2026-10-09 Record Q3 diode results and withdraw unsupported R33 pull-up
    [PetSafe_1001339.kicad_sch, completion_audit.csv, components.csv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]
2026-10-09 Record Q8 supply continuity and stage S1 contact checks
    [PetSafe_1001339.kicad_sch, completion_audit.csv, components.csv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]
2026-10-09 Verify S1 contacts and close E05; prepare LED colour checks
    [PetSafe_1001339.kicad_sch, completion_audit.csv, components.csv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]
2026-10-09 Record LED1 red and green channel mapping; close colour checks
    [PetSafe_1001339.kicad_sch, completion_audit.csv, components.csv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]
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2026-10-09 Map J5 contacts and stage targeted antenna measurements
    [PetSafe_1001339.kicad_sch, completion_audit.csv, components.csv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]
2026-10-14 Correct front antenna capacitor band using measured C11 continuity
2026-10-14 Resolve RA0 receiver link and TP14 motor output in v0.9.39
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2026-10-15 Resolve Q1 low-resistance discrepancy with measured rechecks
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2026-10-15 Correct R39 output pull-up from original PCB copper
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2026-10-15 Correct current partition count and superseded receiver narrative
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2026-10-17 Correct D1/D3 diode symbol semantics without moving numbered terminals
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2026-10-17 Arm button timer before assertion and consume failed attempts safely
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
